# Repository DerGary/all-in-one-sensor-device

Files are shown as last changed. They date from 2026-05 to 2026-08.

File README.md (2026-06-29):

# All-In-One Smart Home Sensor Device

This is a project containing multiple sensors, an esp32 with esphome as well as a 3d printed enclosure to create a DIY Smart Home Sensor Device.

When I started building my smart home, I realized that most devices only cover very specific use cases. To get full functionality in each room, you usually need to buy multiple different devices.

My goal with this project was to create **the ultimate DIY smart home sensor device** that integrates all the essential sensors needed to achieve the following:

## 🎯 Goals

1. Control the lighting in a room by turning it on when motion is detected and keeping it on as long as someone is present (even if the person is not moving).
1. Monitor the brightness in the room and only turn lights on if needed (and off again when no longer required).
1. Measure air quality, humidity, and temperature.
1. Use Bluetooth to track a person’s smartphone and thereby determine which room they are in, so the smart home can react accordingly.
1. Keep the footprint as small as possible.
1. Powered by a single cable. USB-C in particular.
1. Ensure the design is unobtrusive and blends seamlessly into the living room.
1. Integrate with Home Assistant.
1. No cloud dependency.

## Device Types and Revisions

- [All-In-One Smart Home Sensor Case V1](./V1/README.md) - [Makerworld](https://makerworld.com/de/models/1744429-all-in-one-smart-home-sensor-case-v1#profileId-1854007)
- [All-In-One Smart Home Sensor Case V2](./V2/README.md) - [Makerworld](https://makerworld.com/de/models/2180710-all-in-one-smart-home-sensor-case-v2#profileId-2381634)
- [All-In-One Smart Home Sensor Case V2.1](./V2.1/README.md) - [Makerworld](https://makerworld.com/de/models/2180710-all-in-one-smart-home-sensor-case-v2#profileId-2381634)
- [Ultimate Smart Home Sensor Case](./Ultimate/README.md) - [Makerworld](https://makerworld.com/de/models/2946707-ultimate-smart-home-sensor-case#profileId-3300915)

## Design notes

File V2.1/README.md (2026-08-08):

![[./instructions/intro]]

## 🛠️ Assembly Instructions

1. Download the V2.1 assembly instructions PDF from below
2. Follow the assembly instructions in the PDF file

![[./instructions/changelog]]
![[../V2/changelog]]
![[./instructions/disclaimer]]

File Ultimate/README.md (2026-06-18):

![[./instructions/intro]]

## 🛠️ Assembly Instructions

1. Download the Ultimate assembly instructions PDF from below
2. Follow the assembly instructions in the PDF file

![[./instructions/changelog]]
![[./instructions/disclaimer]]

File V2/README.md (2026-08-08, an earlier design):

# All-In-One Smart Home Sensor Case V2

[Makerworld](https://makerworld.com/de/models/2180710-all-in-one-smart-home-sensor-case-v2#profileId-2381634)

## Please read the disclaimer at the bottom before printing

Hello everyone 👋, this has been one of my biggest projects so far. If you have any questions about the project please ask them in the comments then I can answer them and everyone can learn from that.

When I started building my smart home, I realized that most devices only cover very specific use cases. To get full functionality in each room, you usually need to buy multiple different devices.

My goal with this project was to create **the ultimate DIY smart home sensor device** that integrates all the essential sensors needed to achieve the following:

## 🎯 Goals

1. Control the lighting in a room by turning it on when motion is detected and keeping it on as long as someone is present (even if the person is not moving).
1. Monitor the brightness in the room and only turn lights on if needed (and off again when no longer required).
1. Measure air quality, humidity, and temperature.
1. Use Bluetooth to track a person’s smartphone and thereby determine which room they are in, so the smart home can react accordingly.
1. Keep the footprint as small as possible.
1. Powered by a single cable. USB-C in particular.
1. Ensure the design is unobtrusive and blends seamlessly into the living room.
1. Integrate with Home Assistant.
1. No cloud dependency.

## 🖨️ Print Instructions

- **Material:** PLA/PETG
- **Layer Height:** 0.20 mm
- **Nozzle:** 0.4 mm
- **Infill:** 15 %
- **Walls:** 2
- **Divider:** print **upright** with a **brim**, flat side on the build plate. If you orient it differently, it won’t print correctly.
- **Brightness sensor shield:** print with **transparent** material, or omit it entirely. It’s not required but hides the sensor a bit and improves the look.

## 🛠️ Assembly Instructions

1. Download the V2 assembly instructions PDF from below
2. Follow the assembly instructions in the PDF file

## 🆕 Changelog

See [changelog.md](./changelog.md).

### ⚠️ Disclaimer

This project is **not easy**: you have to solder a lot, including **very small** pins. You have been warned — but I’d love to see people try it 😊

The finished product is not perfect — that’s why the title is not *“Ultimate Smart Home Sensor Device”* 😅. I plan to release a revised version with other sensors when I have time and when the sensors I want become more accessible. Since I don’t know when that will be, I’m sharing this version for now.

**Things that bug me on the current version:**

1. **(This got a lot better on the V2 version, to a point where its not really an issue anymore, but it might happen and therefore is still listed here)** The motion sensor is very cheap and sometimes triggers when no one is in the room. (This can be minimized by **reducing the ESP’s Wi-Fi signal strength**, as cheap motion sensors are prone to misfire due to Wi-Fi interference.)
1. The motion sensor can trigger when you **air the room**, as it detects heat changes.
1. The presence sensor uses **24 GHz**. While it can detect mostly stationary humans, it cannot detect **very small movements** or someone under a blanket. (This mostly applies to my girlfriend — somehow I am tracked a bit better 😅).
1. The presence sensor is **extremely hard to solder**. I actually broke a sensor by accidentally desoldering the resistor right next to the pins. I now solder the wires directly to the pins which is janky but it works and is a lot easier.

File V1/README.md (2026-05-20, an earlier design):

# All-In-One Smart Home Sensor Case V1

This version of the sensor is deprecated please use V2 instead.

Please find more information on this version at [Makerworld](https://makerworld.com/de/models/1744429-all-in-one-smart-home-sensor-case-v1#profileId-1854007)

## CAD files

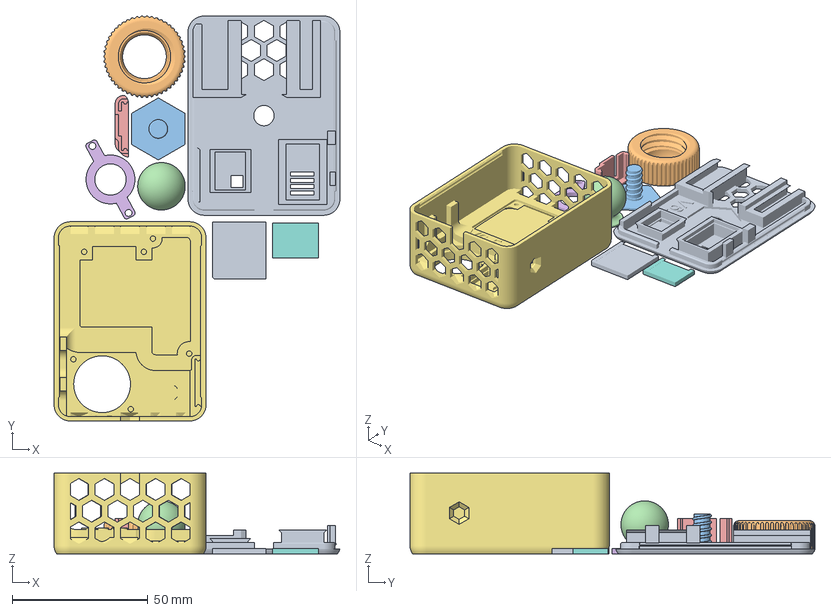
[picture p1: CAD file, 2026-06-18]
Ultimate/models/ultimate.3mf
105.3 x 149.2 x 29.8 mm
ultimate.stl_5
Screw.stl
ultimate.stl_6
ultimate.stl_9
ultimate.stl_4
ultimate.stl_3
Assembly
ultimate.stl_7
ultimate.stl_8

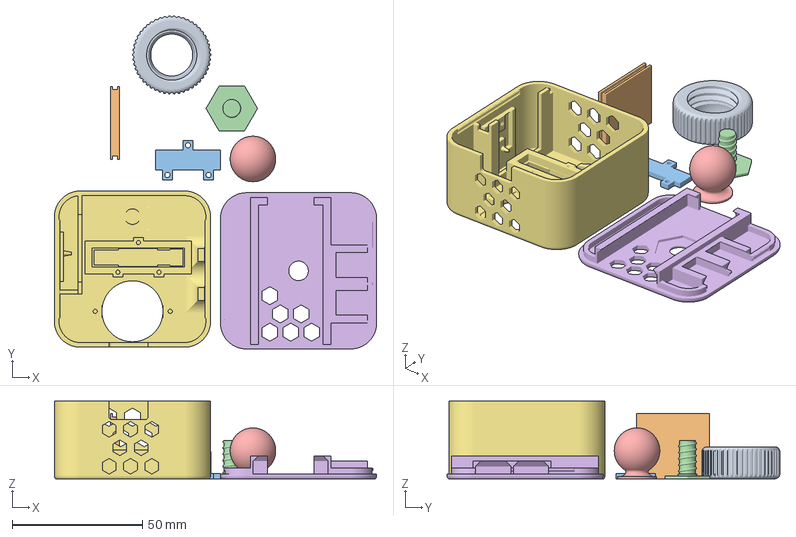
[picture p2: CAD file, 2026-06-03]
V2.1/models/V2.1-Large.3mf
123.8 x 127.8 x 29.8 mm
Screw.stl
V2.1-D1Mini.stl_2
V2.1-D1Mini.stl_5
V2.1-D1Mini.stl_6
V2.1-D1Mini.stl_8
V2.1-Large.stl_7
V2.1-Large.stl

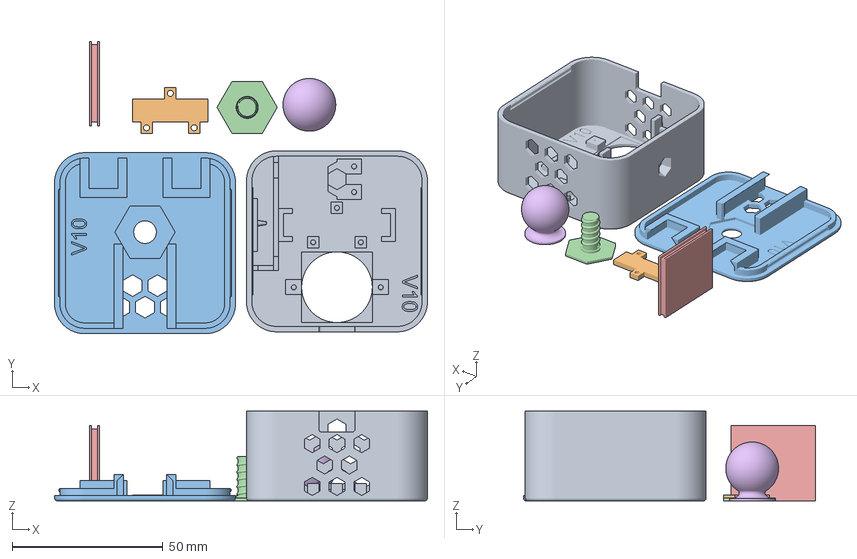
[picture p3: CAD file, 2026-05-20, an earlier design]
V2/models/v2-SuperMini.3mf
123.6 x 96.9 x 29.8 mm
All-In One Sensor Case ESP Super Mini.stl
All-In One Sensor Case ESP Super Mini.stl_4
All-In One Sensor Case ESP Super Mini.stl_5
All-In One Sensor Case ESP Super Mini.stl_6
All-In One Sensor Case ESP Super Mini.stl_7
All-In One Sensor Case ESP Super Mini.stl_8

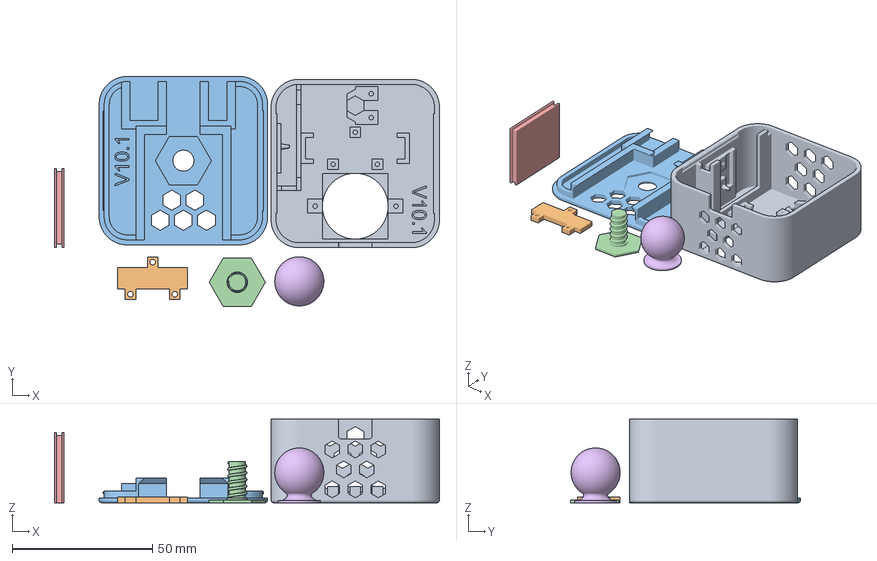
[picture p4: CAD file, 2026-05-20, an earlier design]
V2/models/v2-D1Mini.3mf
137.1 x 81.9 x 29.8 mm
All-In One Sensor Case ESP D1 Mini.stl
All-In One Sensor Case ESP D1 Mini.stl_4
All-In One Sensor Case ESP D1 Mini.stl_5
All-In One Sensor Case ESP D1 Mini.stl_6
All-In One Sensor Case ESP D1 Mini.stl_7
All-In One Sensor Case ESP D1 Mini.stl_8

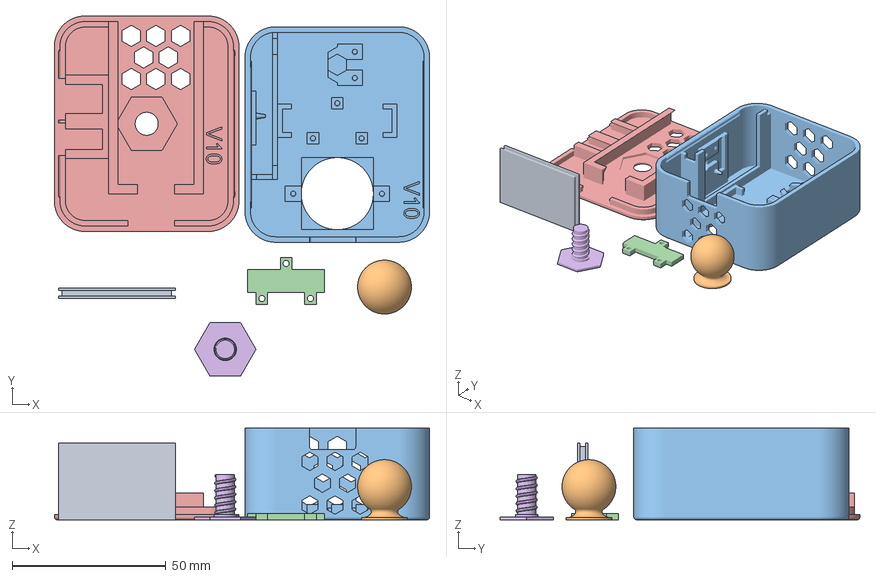
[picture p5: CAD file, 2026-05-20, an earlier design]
V2/models/v2-Large.3mf
121.9 x 116.9 x 29.8 mm
Sensor Gehäuse Large ESP32.stl_2
Sensor Gehäuse Large ESP32.stl_8
Sensor Gehäuse Large ESP32.stl
Sensor Gehäuse Large ESP32.stl_5
Sensor Gehäuse Large ESP32.stl_6
Sensor Gehäuse Large ESP32.stl_7

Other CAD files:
V2.1/models/V2.1-SuperMini.3mf
V2.1/models/V2.1-D1Mini.3mf
Ultimate/models/ultimate.stl
V2.1/models/V2.1-D1Mini.stl
V2.1/models/V2.1-Large.stl
V2.1/models/V2.1-SuperMini.stl
V2/models/v2-D1Mini.stl
V2/models/v2-Large.stl
V2/models/v2-SuperMini.stl

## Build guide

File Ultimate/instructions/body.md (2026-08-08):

## 🔢 Steps

1. Source all the parts from the shopping list
1. Print the enclosure
1. Solder and wire all sensors to the distribution boards and ESP
1. Flash the ESP with the software and verify that all sensors work (connect it to your Home Assistant instance to monitor them).
1. Assemble the sensors and ESP into the enclosure.
1. Place the device in its designated spot.
1. After a few minutes, calibrate the sensors and re-flash the software.
1. Create your Home Assistant automations using the sensors.

### 🛒 Shopping List

You can also buy the parts from other sites. If you don’t mind waiting, AliExpress is usually cheaper. I’ve listed the exact products I used because I can confirm they worked for me.

| Name | Hint | Link |
| ----- | --- | --- |
| ESP32 Super Mini | My prebuilt binaries use the C6, you can also use other variants if you build it yourself. | [DFRobot ESP32-C6](https://www.berrybase.de/en/dfrobot-beetle-esp32-c6-wifi-6-bluetooth-5-zigbee-3.0-thread-risc-v-13-io-ports-3.3v) <br> [ESP32-C6 Super Mini](https://de.aliexpress.com/item/1005009089500839.html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) (you must choose the correct variant, as the link does not include the choice) |
| Power Supply (PSU) | Any low-power PSU you already have should work. Otherwise, buy a simple one. | [Amazon](https://www.amazon.de/dp/B0D7MD5BJ3?ref=ppx_yo2ov_dt_b_fed_asin_title&th=1) |
| Temperature Sensor SHT4x or BME280 | I decided to use the SHT41 as its temperature sensor is more accurate. <br> The BME280 is also supported when you need to measure air pressure. | [BME280](https://amzn.eu/d/04BAvHum) <br> [SHT4x](https://de.aliexpress.com/item/1005008518326181.html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) |
| Screws | 8x M2x3mm | [Amazon](https://www.amazon.de/dp/B0CZNT5YXV?ref=ppx_yo2ov_dt_b_fed_asin_title&th=1) |
| Brightness Sensor BH1750 | Worked flawlessly for me in V1 and V2 so it is back in the Ultimate | [Amazon](https://www.amazon.de/dp/B0D3WN41FS?ref=ppx_yo2ov_dt_b_fed_asin_title) |
| CO2 Sensor SCD4x | Measures actual CO2 concentration. Both SCD40 and SCD41 are supported. | [Aliexpress](https://de.aliexpress.com/item/1005008696769890.html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) |
| VOC Sensor SGP30 | Measures volatile organic compounds (air quality). I am using the blue module also called GY-SGP30. | [Aliexpress](https://de.aliexpress.com/item/1005012034193686.html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) |
| Motion Sensor Panasonic EKMC 1603111 | Theoretically other Panasonic PIRs would be also compatible if they have the same form factor. | [Aliexpress](https://de.aliexpress.com/item/1005006704410099.html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) |
| Presence Sensor LD2450 | Handles multi-person, zone-based tracking. Pay attention that the one you buy includes the cable as it is easier to work with. | [Amazon](https://www.amazon.de/dp/B0FMRQ6DWJ?ref_=ppx_hzod_title_dt_b_fed_asin_title_0_0) |
| Presence Sensor C4001 | Handles still-presence detection (detecting a stationary person). Both sensors are needed; they complement each other. Unfortunately this sensor is hard to source — import taxes may apply depending on the supplier. | [DigiKey](https://www.digikey.de/de/products/detail/dfrobot/SEN0609/23028638) <br> [RobotShop](https://eu.robotshop.com/de/products/dfrobot-mmwave-c4001-24ghz-sensor-zur-erkennung-menschlicher-prasenz-25-meter-uart) <br> [Mouser](https://www.mouser.de/ProductDetail/DFRobot/SEN0609?qs=HFfMDpzxxd21aKNJkzimmg%3D%3D) <br> [OpenELAB](https://openelab.io/de/products/dfrobot-mmwavec400124ghz-humanpresencedetectionsensor-25meters) <br> [DFRobot](https://www.dfrobot.com/product-2793.html) |
| Cables | I used 22 AWG wire | [Aliexpress](https://de.aliexpress.com/item/1005007671008743.html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)<br>[Amazon](https://www.amazon.de/dp/B0FDKT9XPV?ref_=ppx_hzsearch_conn_dt_b_fed_asin_title_1&th=1) |
| Long USB Cable | Choose length to fit your setup. | [Aliexpress](https://de.aliexpress.com/item/1005007053181899.html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) |
| Filament | I printed my case in Kingroon White PLA and with Kingroon White PETG. You can use bambu labs filament of course. I printed the brightness sensor cover out of translucent PLA/PETG. | [Kingroon Filament](https://de.aliexpress.com/item/1005007226921275.html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)<br>[Elegoo Transparent PLA](https://www.amazon.de/dp/B0CD7BS7B1?ref_=ppx_hzsearch_conn_dt_b_fed_asin_title_8)<br>[eSUN Clear PETG](https://www.3djake.de/esun/petg-clear-5) |
| Cable Distribution (Proto Boards) | I broke something off proto boards and used that to distribute the cables which needed to go to multiple sensors. | [Amazon](https://amzn.eu/d/0a2D7E1M) |
| Status LED | I used an LED from leftovers of a WS2812 LED strip with 5V that I got lying around | [Amazon](https://amzn.eu/d/04rXpC34) |
| 100µF 16V Electrolytic Capacitor<br>100nF (104) Ceramic Capacitor | The capacitors are used to suppress interferences that may be injected by the ESP32 into the power rails.<br> This measure was taken to improve the reliability of the PIR sensor and remove false positives as much as possible. It is recommended by Panasonic to do so. I got pretty good results without them but I wanted the best possible experience and your mileage may vary if you omit them. | [Amazon](https://www.amazon.de/dp/B0DXC7MX53) |

You also need:

- A soldering iron (and soldering skills)
- Solder
- Wire stripping tool
- Side cutters to trim the cables
- Screwdriver
- Pliers
- Desoldering pump (optional)
- Multimeter (optional if you trust your soldering skills)
- Electrical tape (optional, to cover LEDs on the C4001 and ESP)

### 🔢 Assembly Instructions

1. Desolder all the pin headers if there are any on your purchased sensors
    - Remove the pin spacers with pliers.
    - Clamp the sensor in a vise.
    - Desolder and remove the pins. It’s also possible to heat the solder and pull the pins with pliers without a desoldering pump.
1. Break a **7x4** matrix from the proto board
    I used a carpet knife to cut around the matrix on the proto board on both sides and used pliers to carefully break the proto board at the cut.

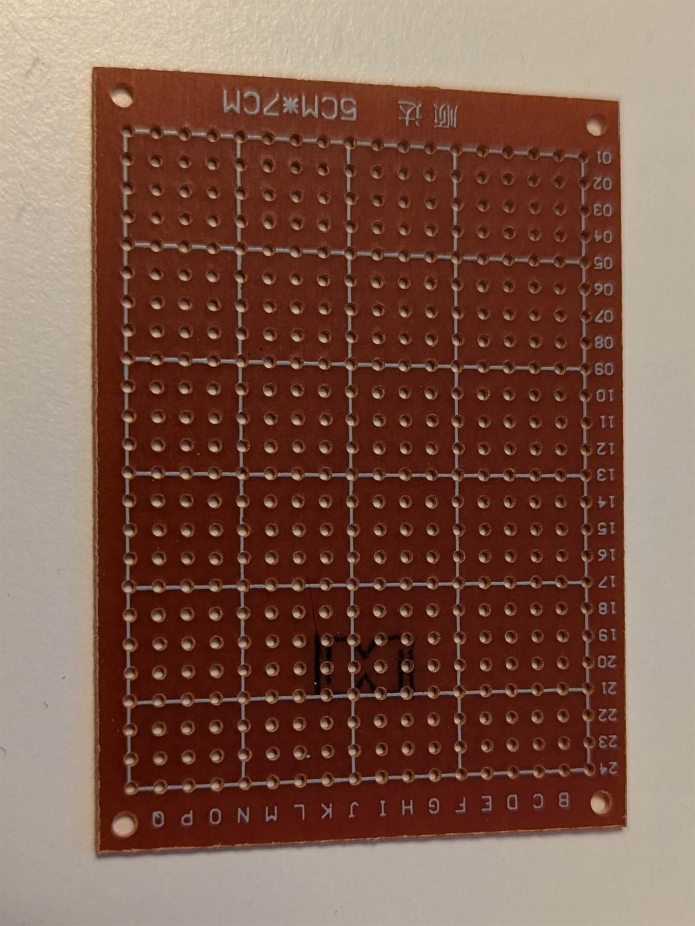
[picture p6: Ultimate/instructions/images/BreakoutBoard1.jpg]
    
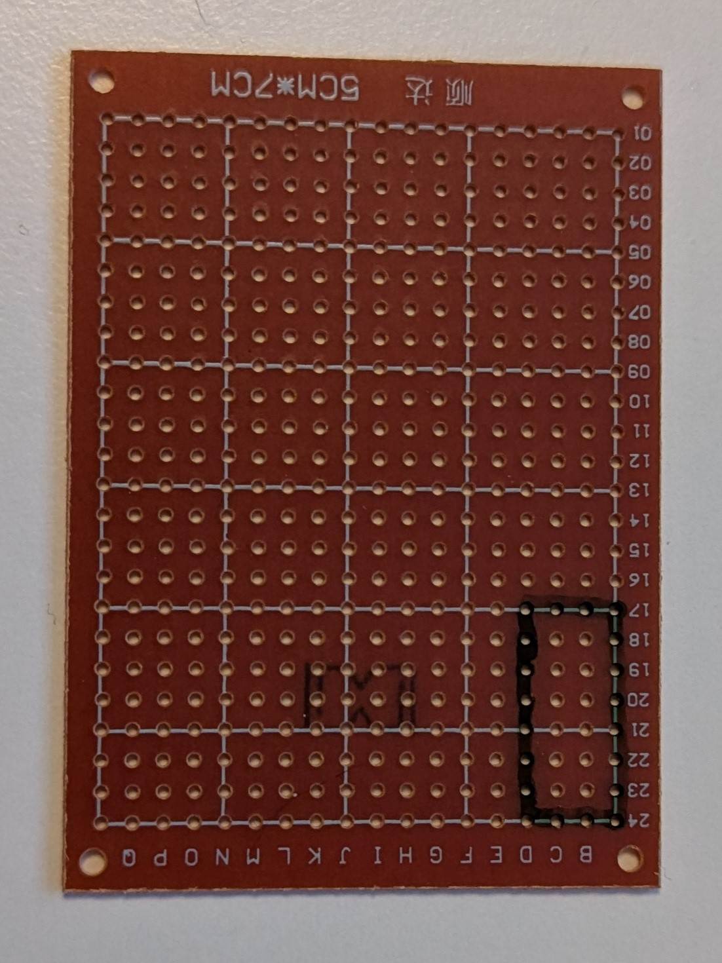
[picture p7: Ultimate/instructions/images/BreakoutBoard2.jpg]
    
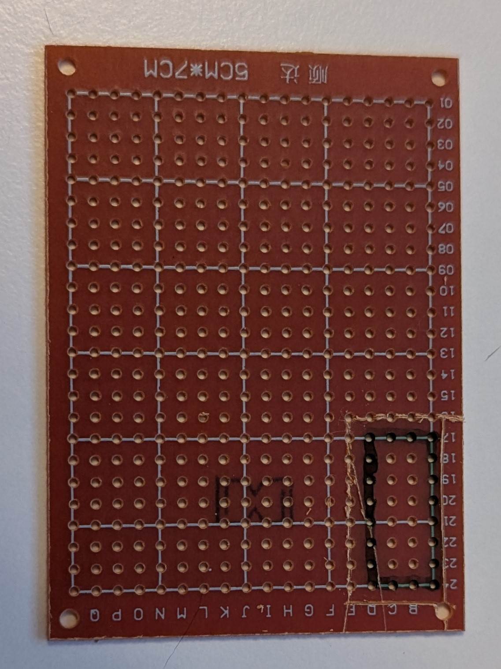
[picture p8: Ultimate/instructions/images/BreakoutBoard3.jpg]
    
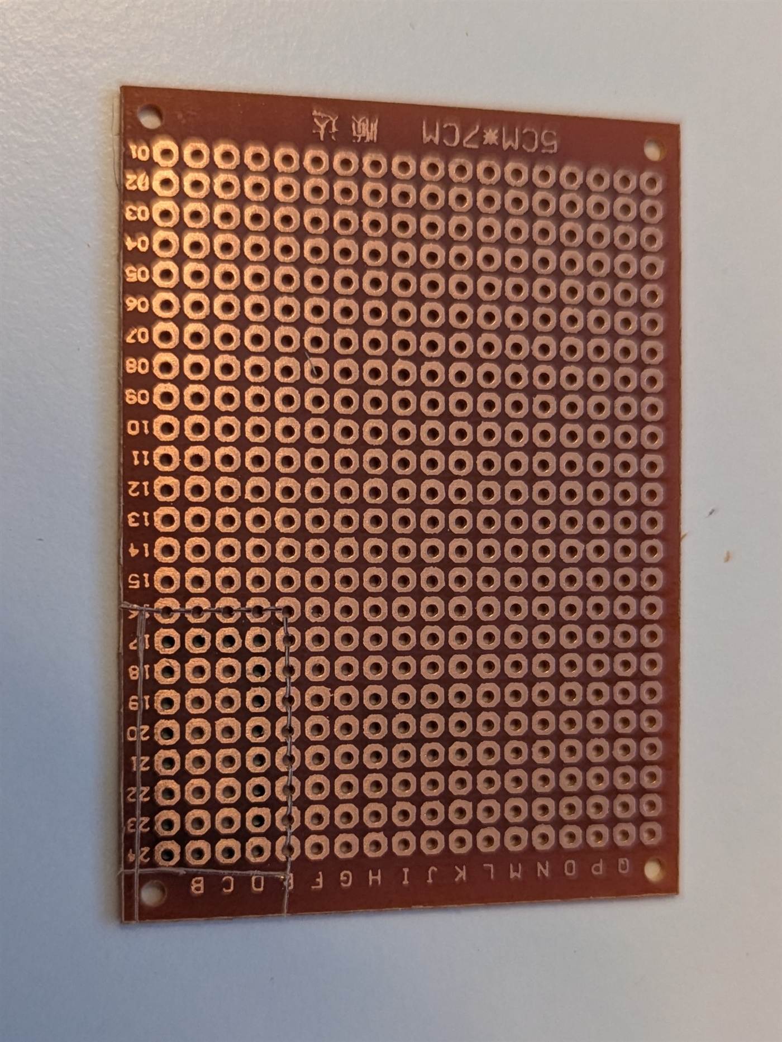
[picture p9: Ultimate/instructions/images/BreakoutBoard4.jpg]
    
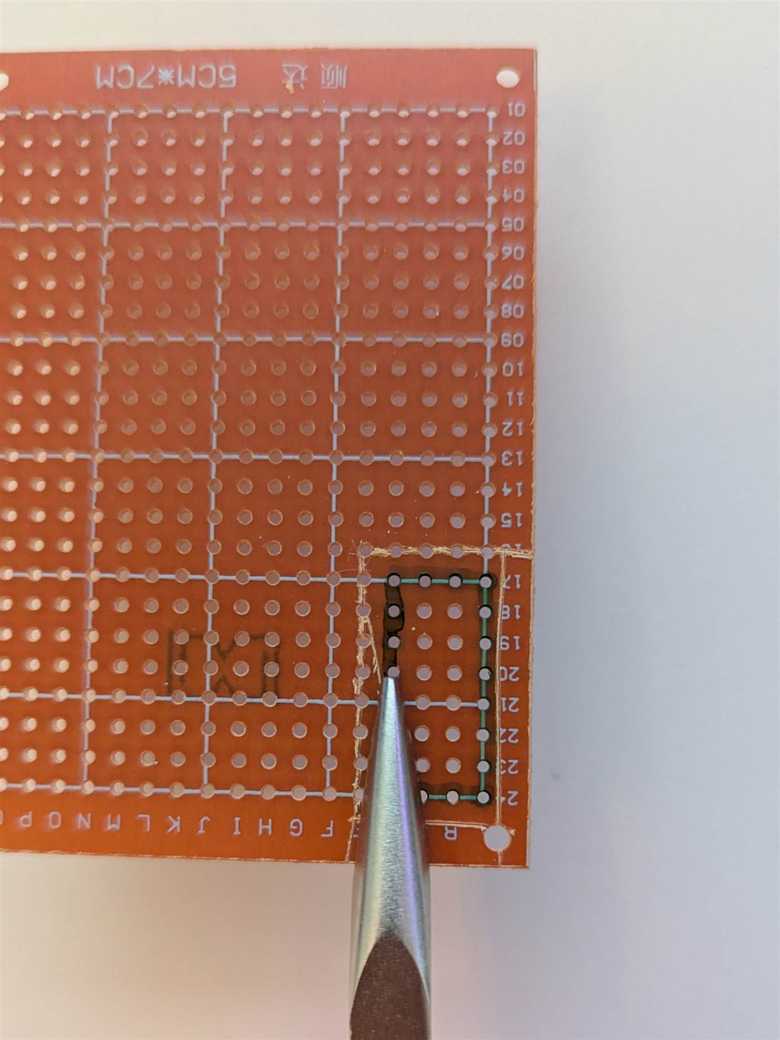
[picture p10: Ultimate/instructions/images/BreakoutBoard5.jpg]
    
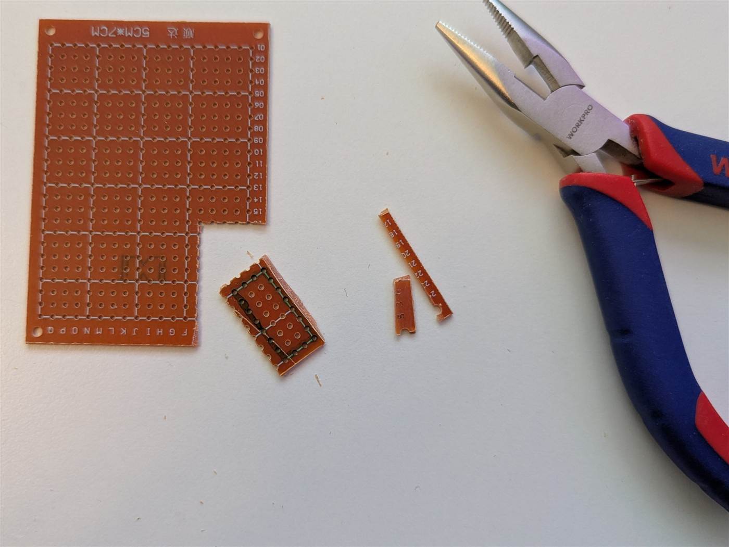
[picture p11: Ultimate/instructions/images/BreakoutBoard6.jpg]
    

1. Break a **5×2** matrix from the proto board
    Using the same technique as above.
1. Cut wires to length. I wrote the length of the cables in mm into the connection drawings. I show the two distribution boards separately to make things easier to follow. (There are further steps below on soldering order.) For the generic ESP32-C6 Super Mini the wiring differs in one aspect from the DFRobot Beetle as it only has one ground pin.
    - I only had 5 colors of wire
        - red = Voltage (If you have more colors use different colors for 3.3V (BME280/BH1750/SGP4x/SHT4x/SCD4x/PIR) and 5V(LD2450/C4001/LED), It is important to never mix them up)
        - black = Ground
        - Green = I2C SCL/UART (If you have more colors you can use different colors for UART and I2C)
        - Blue = I2C SDA/UART (If you have more colors you can use different colors for UART and I2C)
        - Yellow = Motion Out / Status LED Data In
    - **DFRobot Beetle ESP32-C6**
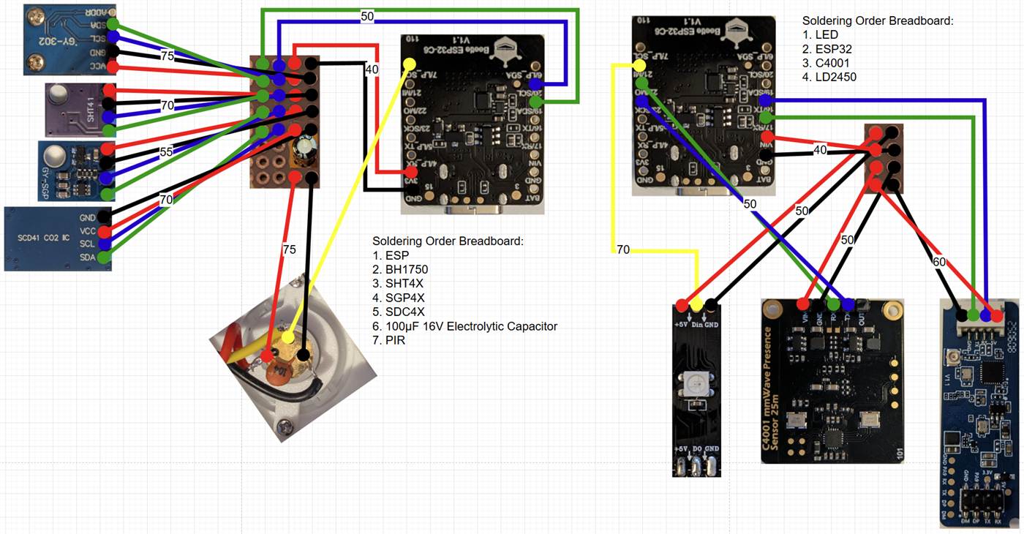
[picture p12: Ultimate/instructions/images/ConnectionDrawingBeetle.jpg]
        
    - **Generic ESP32-C6 Super Mini**
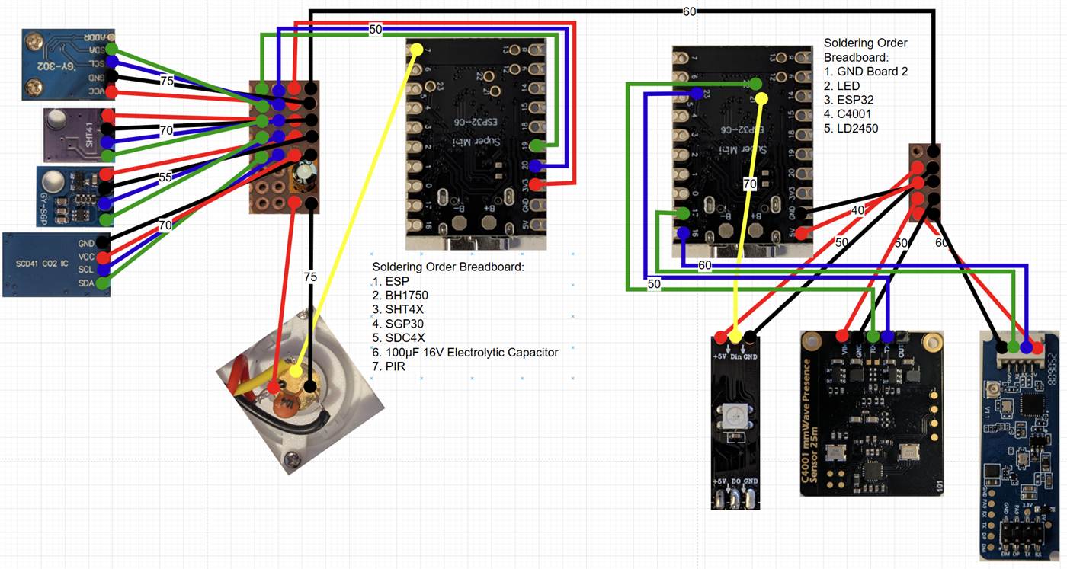
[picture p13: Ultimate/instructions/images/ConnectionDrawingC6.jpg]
        

    **Pin Reference**

    | Sensor / Function | GPIO |
    | --- | --- |
    | PIR Motion Out | GPIO7 |
    | I2C SDA (BH1750 / SHT4x / SGP30 / SCD4x) | GPIO19 |
    | I2C SCL (BH1750 / SHT4x / SGP30 / SCD4x) | GPIO20 |
    | WS2812 LED Data | GPIO21 |
    | LD2450 TX (ESP→Sensor) | GPIO16 |
    | LD2450 RX (Sensor→ESP) | GPIO17 |
    | C4001 TX (ESP→Sensor) | GPIO22 |
    | C4001 RX (Sensor→ESP) | GPIO23 |

1. Make sure to tin the wire ends
1. Solder one end of each wire to the sensors as described in the Connection Drawings from Step 4
    - PIR Sensor:
        - First place the printed round PIR bracket on the sensor as this can't be done when the sensor is already soldered together
        - The middle pin is the data pin
        - also solder the 100nF ceramic capacitor between the ground and the voltage pin
    - Presence Sensor LD2450:
        - **The colors of the included cable are different to the drawings. The cable may have different colors on your version. Pay attention to correctly wire every pin to the correct location. The pins are labeled on the board.**

    | PIR Sensor | Presence Sensors | BH1750 |
    | ---------- | ---------------- | ------ |
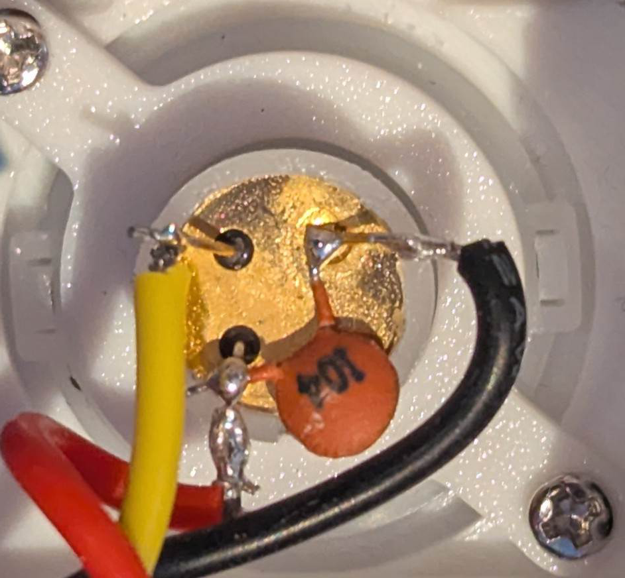
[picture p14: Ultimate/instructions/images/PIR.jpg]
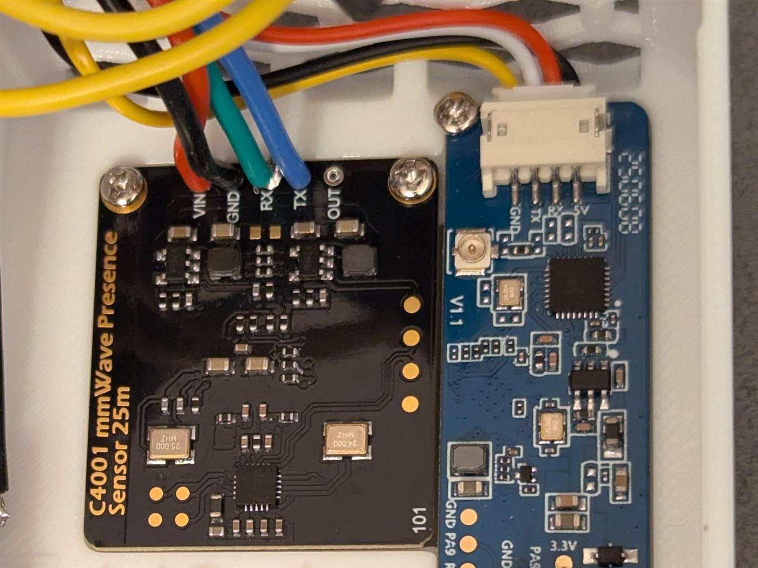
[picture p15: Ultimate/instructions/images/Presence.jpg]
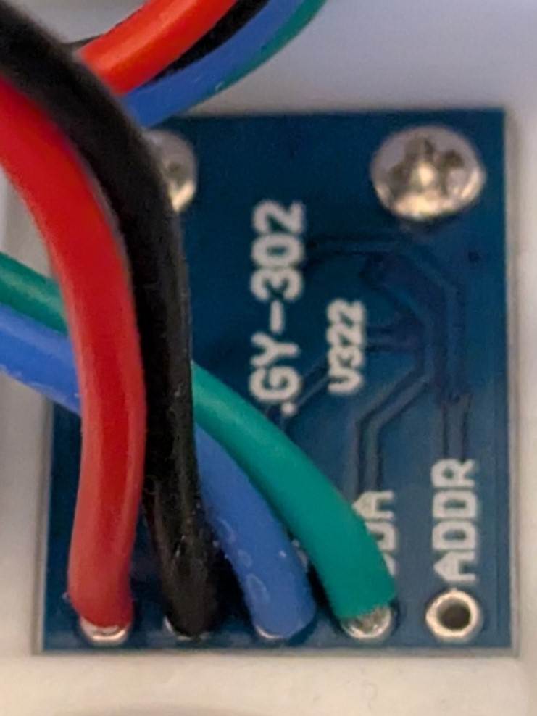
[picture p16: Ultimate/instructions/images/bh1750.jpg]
    |  |  |  |

    | SHT41 | SCD41 | SGP30 |
    | ----- | ----- | ----- |
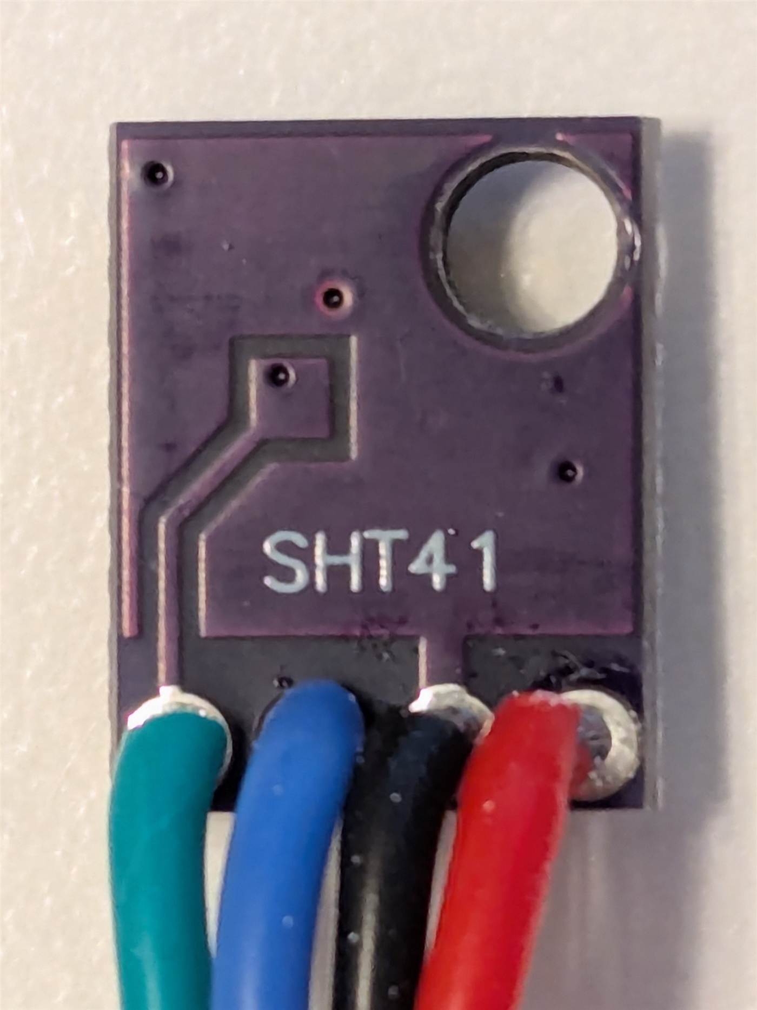
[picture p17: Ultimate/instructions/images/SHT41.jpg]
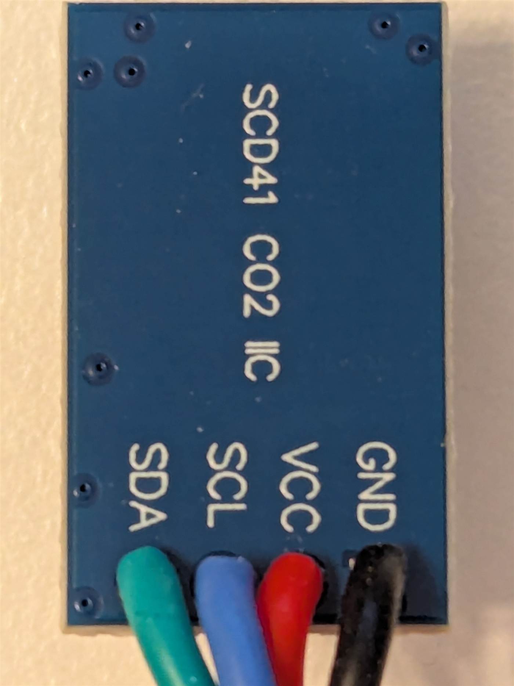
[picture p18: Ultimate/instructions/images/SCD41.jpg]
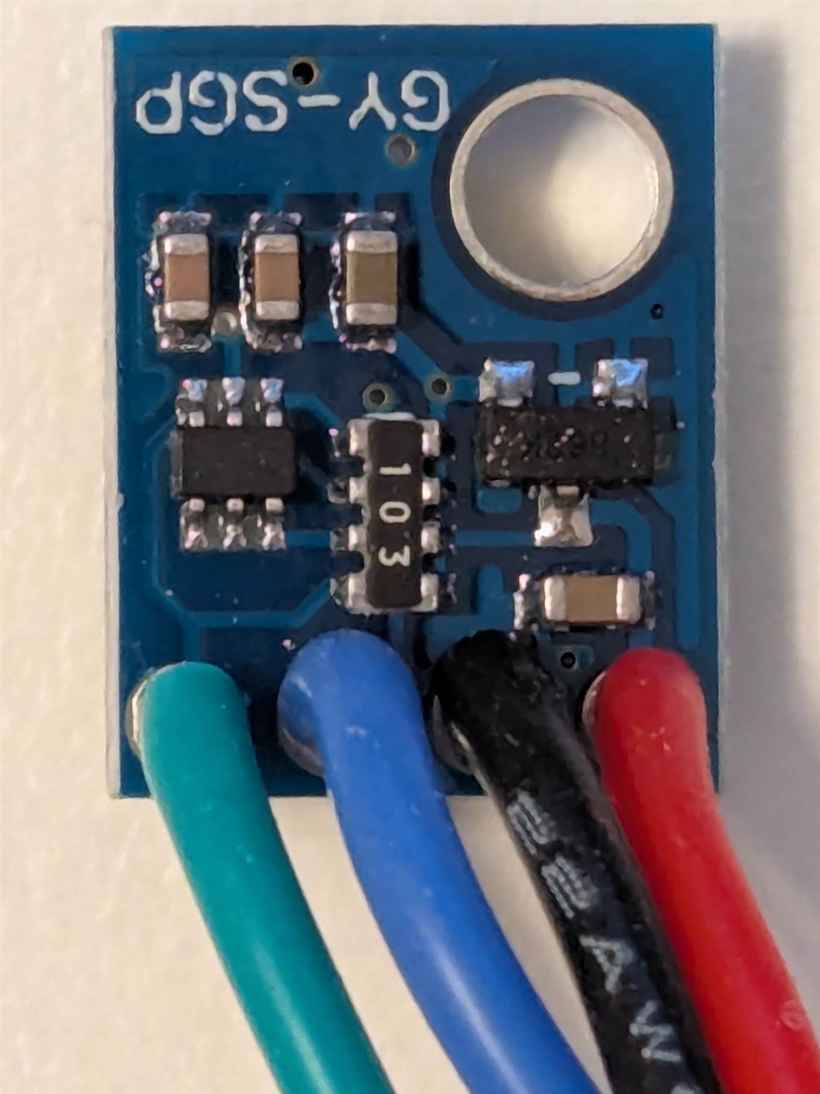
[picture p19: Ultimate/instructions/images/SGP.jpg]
    |  |  |  |

1. Solder the **other end** of the wires to the **distribution proto boards and ESP respectively. Connect wires of the same color together.** If you used a proto board where the lines are already connected via the board you don't need to do any extra step. My proto board has separated solder points so I had to bridge them.

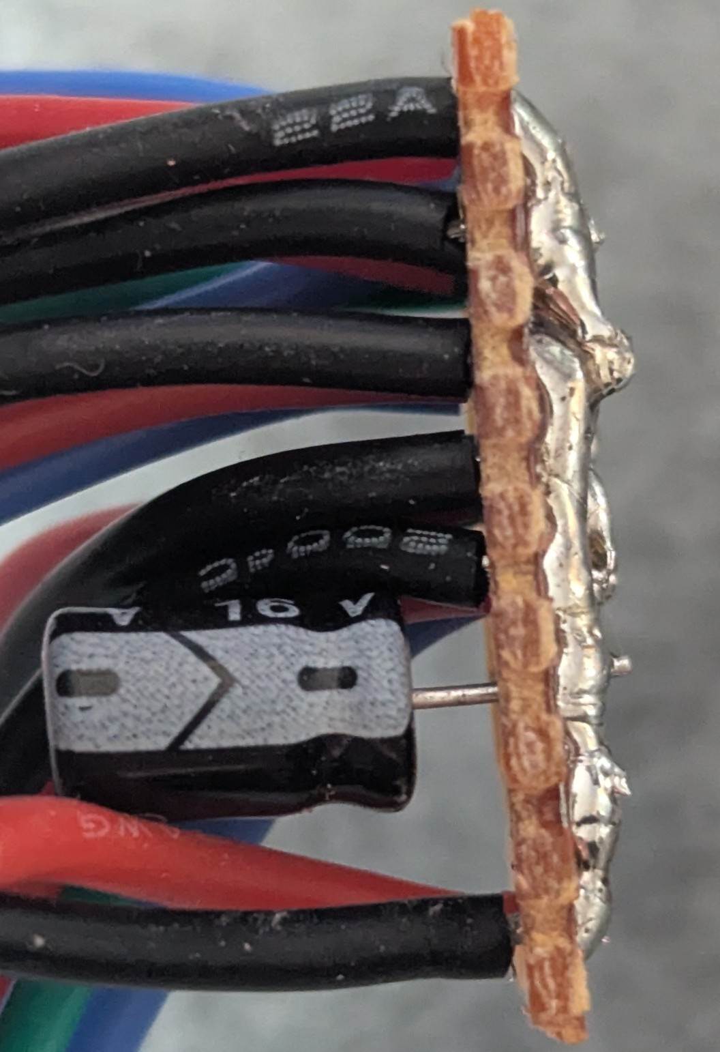
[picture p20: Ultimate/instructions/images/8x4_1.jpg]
    
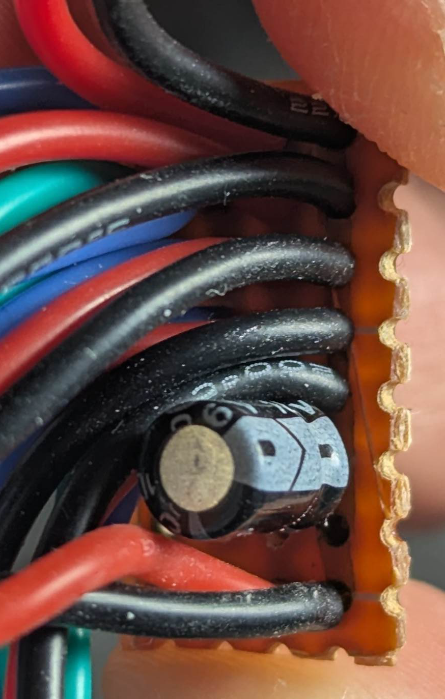
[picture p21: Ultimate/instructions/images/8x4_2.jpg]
    
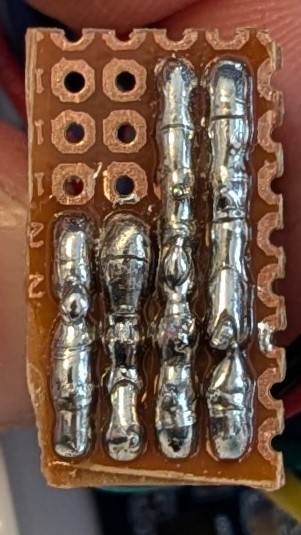
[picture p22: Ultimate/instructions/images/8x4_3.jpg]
    <br>
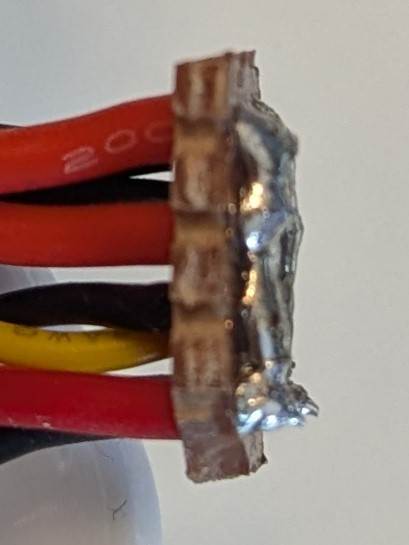
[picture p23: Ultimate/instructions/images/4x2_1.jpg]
    
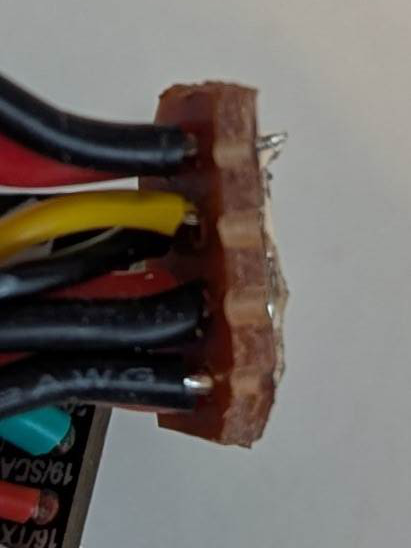
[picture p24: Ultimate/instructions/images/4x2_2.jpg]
    
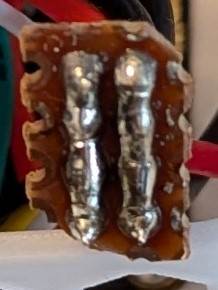
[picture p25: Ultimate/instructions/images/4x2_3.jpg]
    

    Also solder the **100µF electrolytic capacitor** across the 3.3V and GND rails on the distribution proto board, as shown in the Connection Drawings above. Observe polarity — the negative lead (shorter leg / marked stripe) connects to GND.

1. **Solder the wires to the ESP pins** as described in the connection drawings above. You need to attach the cables from the back side (because the wifi antenna is on the front and we want that to be facing away from the motion sensor) — attach them as shown in the photos.

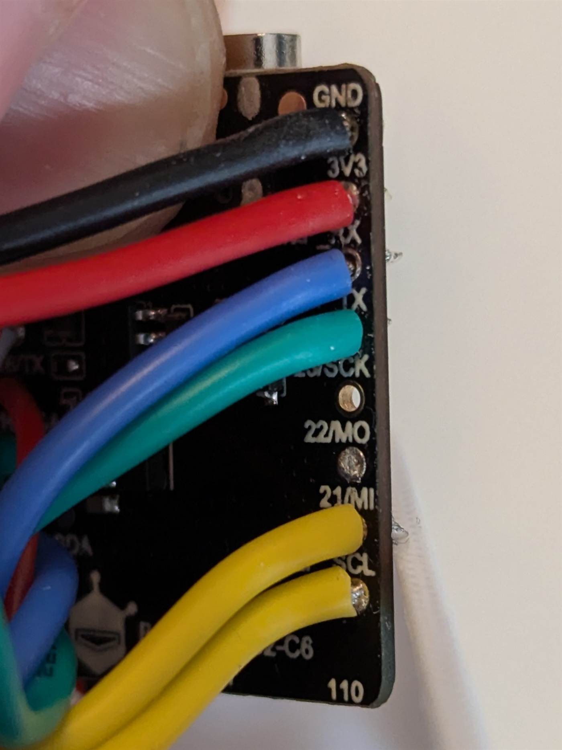
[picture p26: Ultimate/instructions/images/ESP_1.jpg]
    
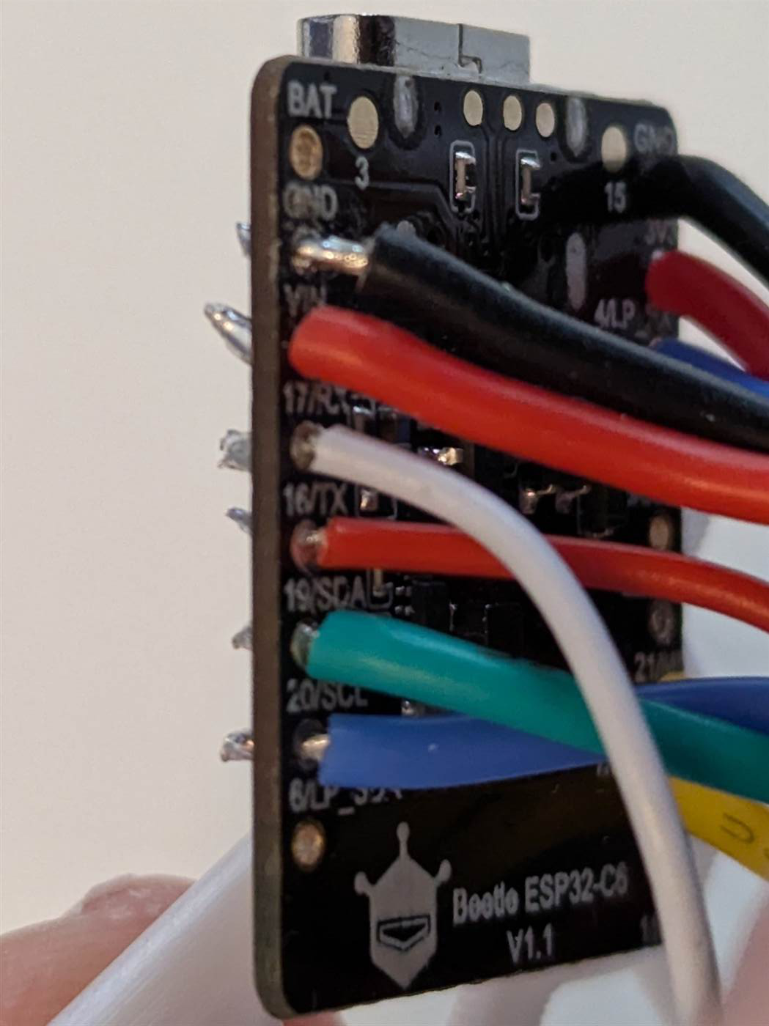
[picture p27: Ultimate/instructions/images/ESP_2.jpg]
    
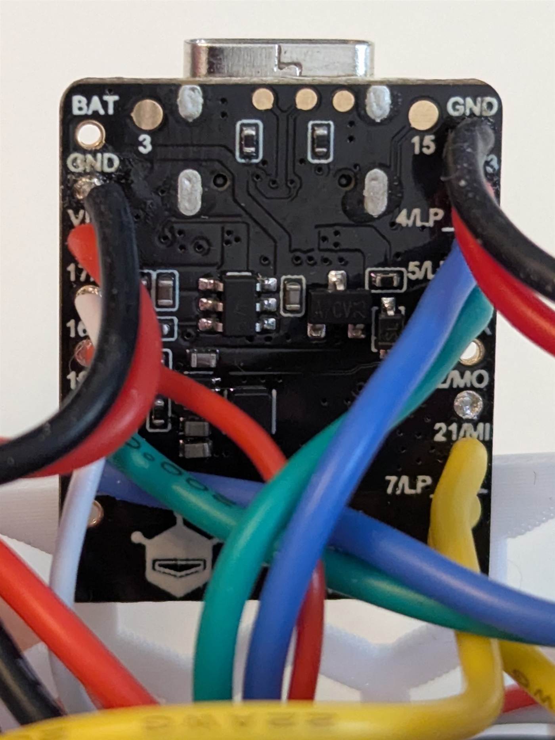
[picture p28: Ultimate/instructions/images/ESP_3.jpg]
    

1. Use a **multimeter** to verify that solder joints of different colors do not bridge. Any short can damage components and may cause smoke or even fire.
1. Now it's time to check whether all the soldering has worked out. Flash the software onto the ESP. It can be found in the software section. Verify that all sensors are detected and reporting, then return here to complete assembly.
1. Optionally cover the LEDs on the **C4001** and the **ESP** with a small piece of electrical tape to prevent them from lighting up inside the enclosure.

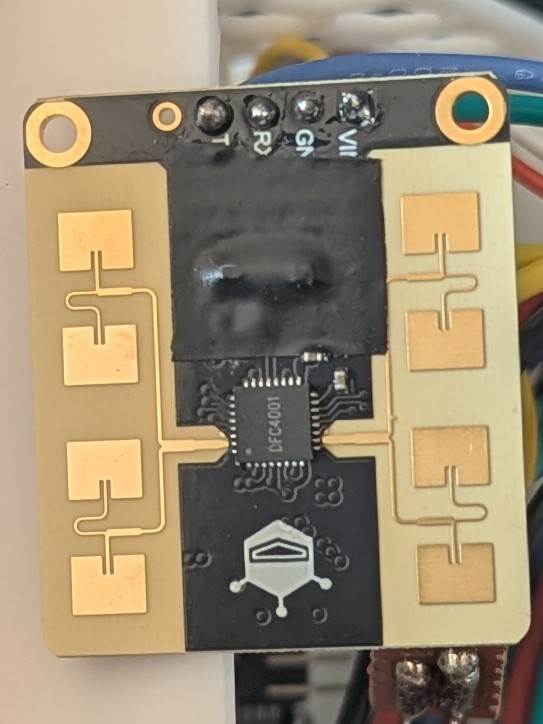
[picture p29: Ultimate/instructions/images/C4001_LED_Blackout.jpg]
    
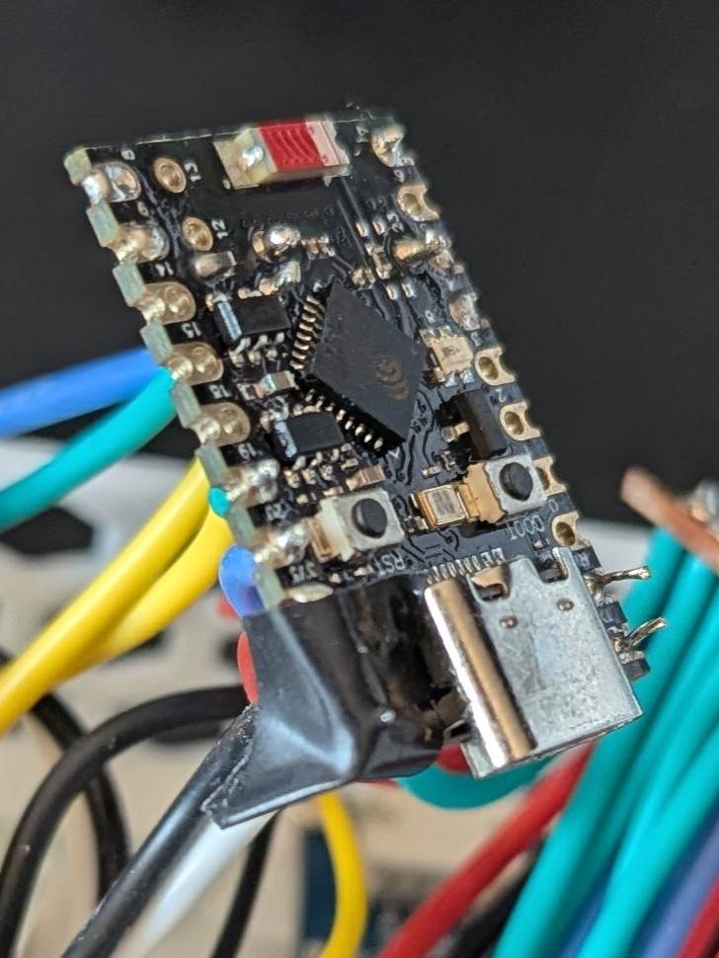
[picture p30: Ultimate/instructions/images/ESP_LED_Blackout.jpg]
    

1. Attach the ball head mount to the back of the case

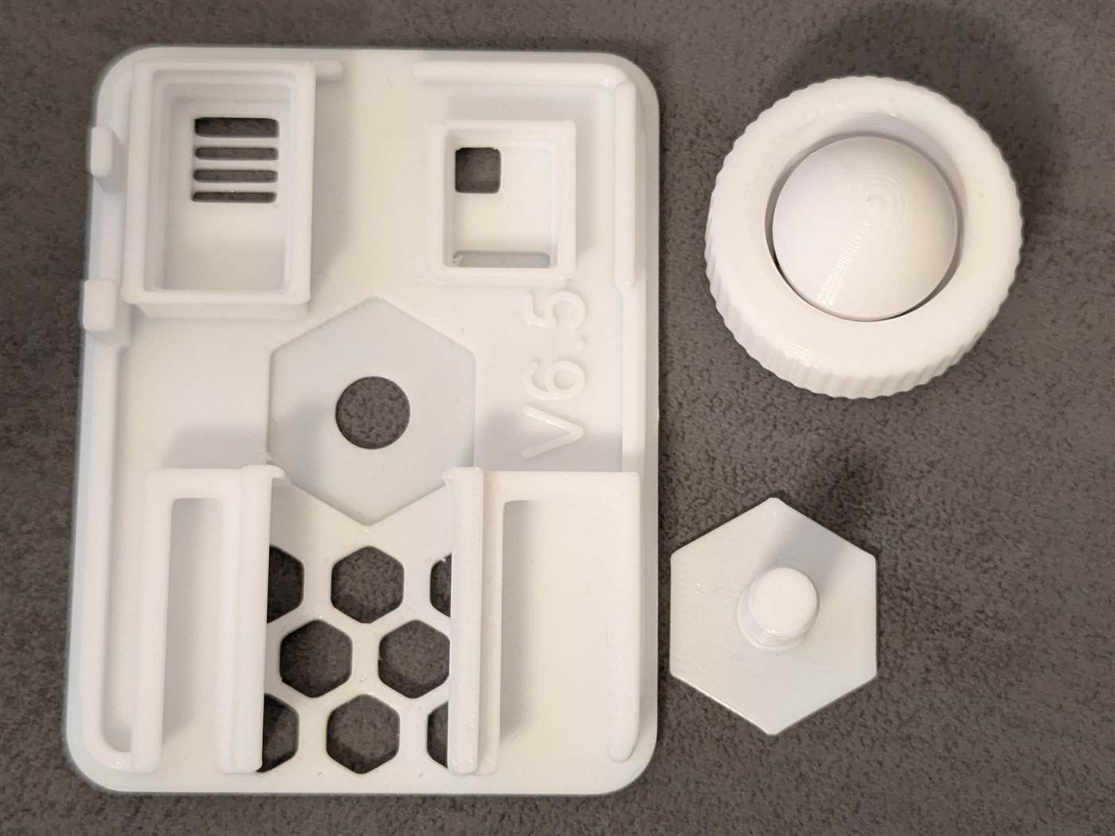
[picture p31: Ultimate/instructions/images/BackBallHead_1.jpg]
    
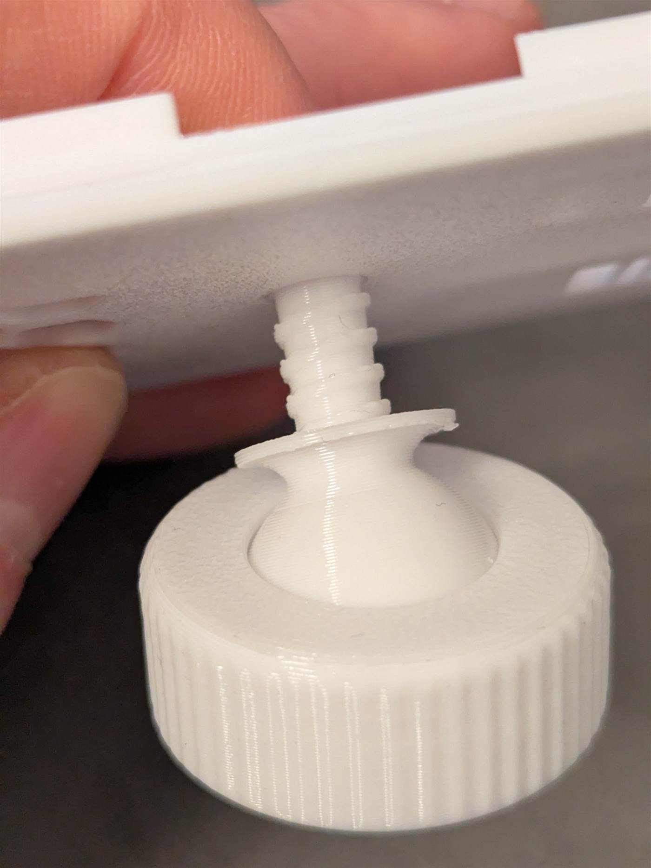
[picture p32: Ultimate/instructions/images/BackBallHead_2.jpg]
    
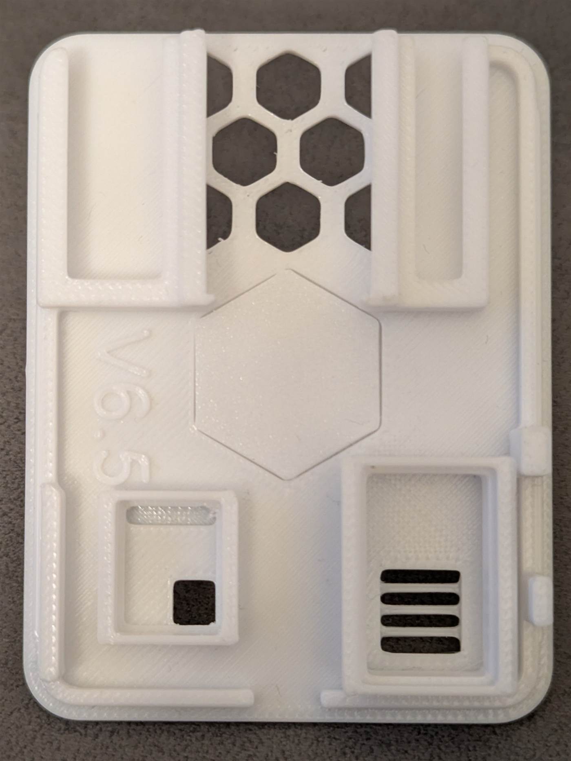
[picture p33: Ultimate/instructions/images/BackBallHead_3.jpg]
    

1. Place all the sensors, boards and ESP in place using M2x3mm screws
    The order does not really matter but it is easiest to do it in the order depicted in the photos here:

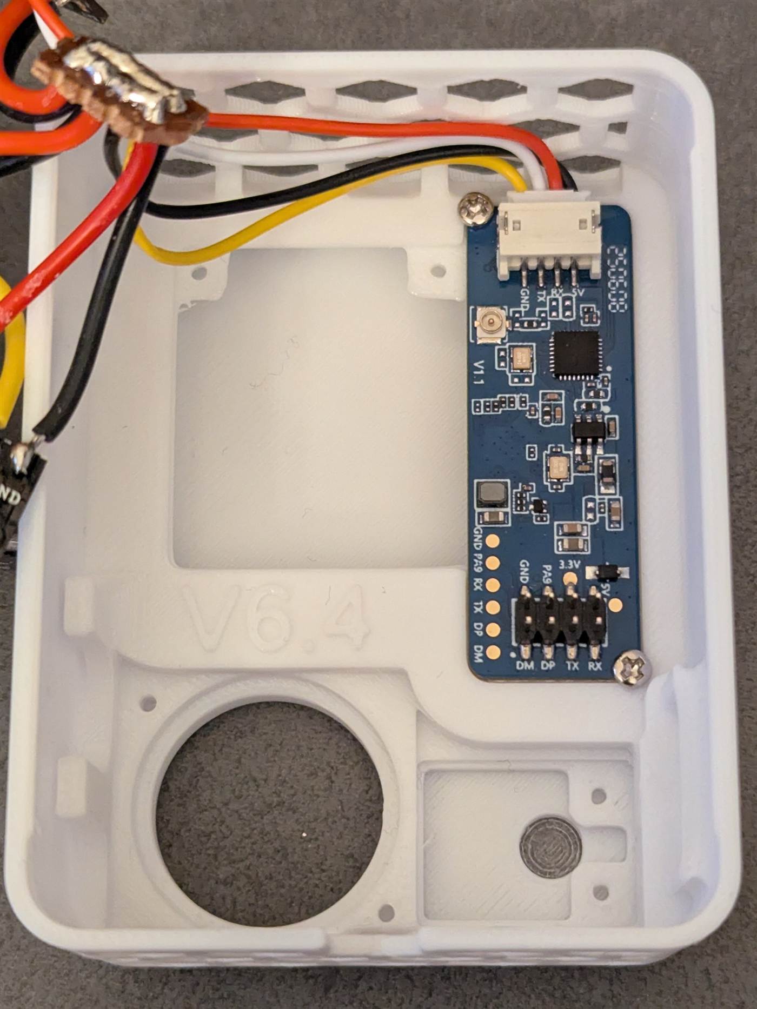
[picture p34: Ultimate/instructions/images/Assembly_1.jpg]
    
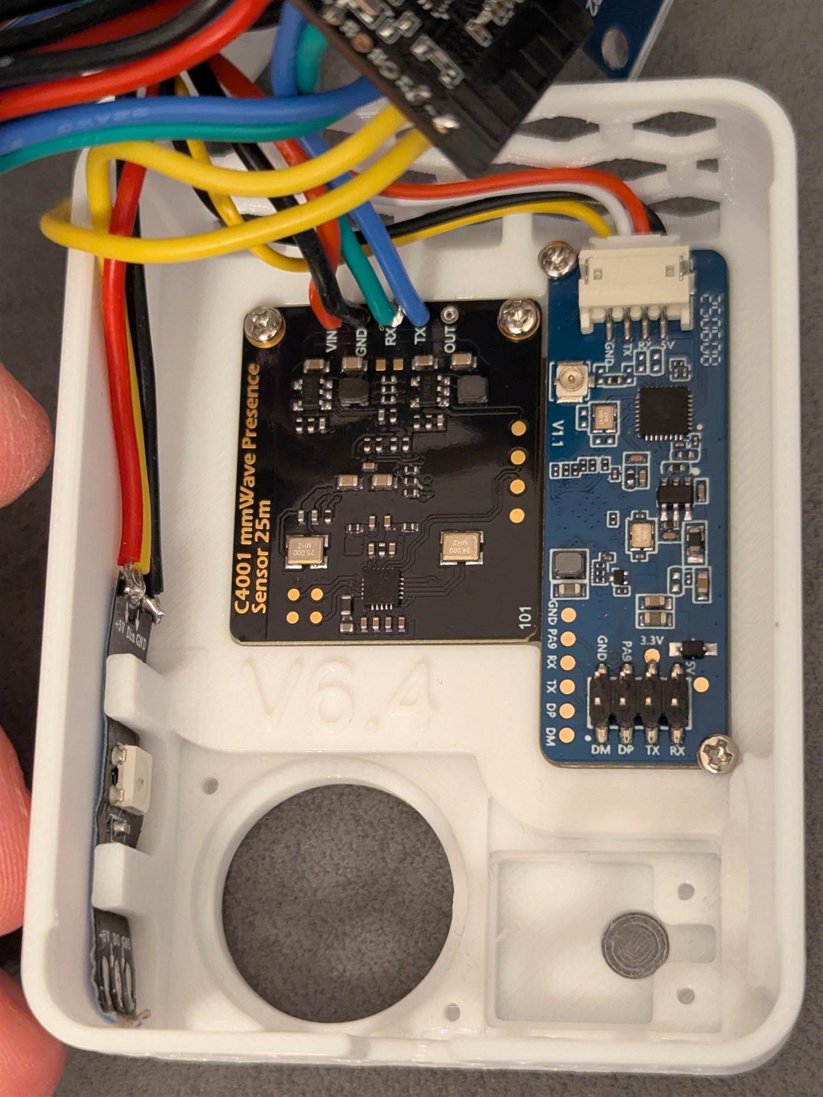
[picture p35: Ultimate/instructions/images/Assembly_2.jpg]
    
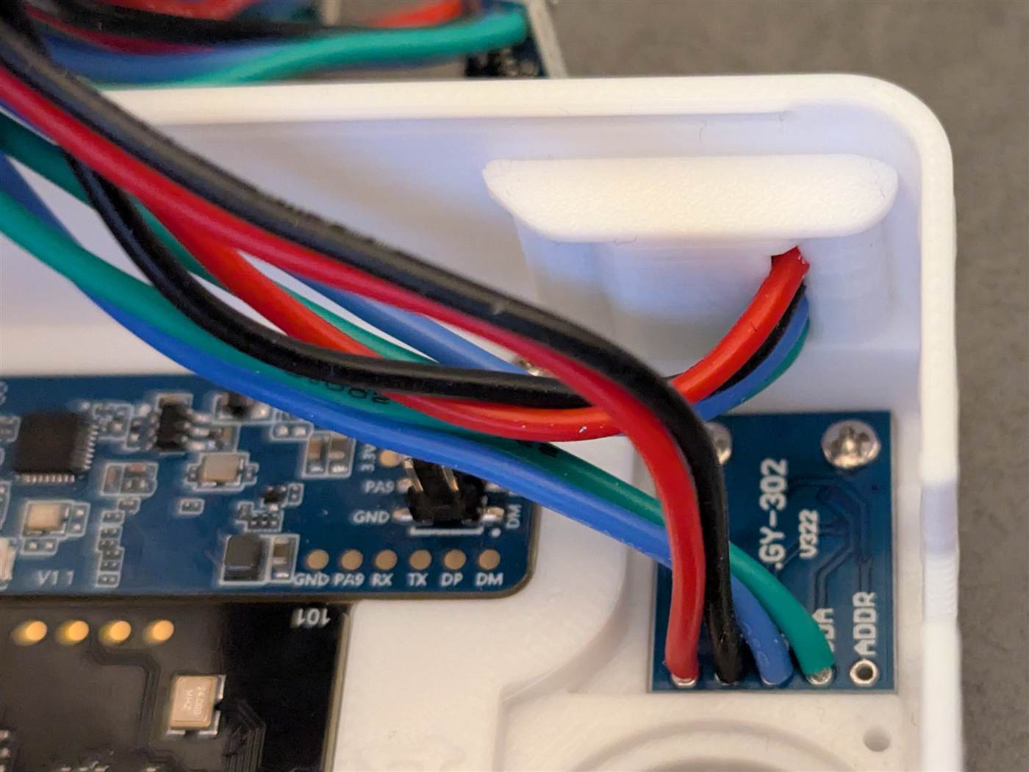
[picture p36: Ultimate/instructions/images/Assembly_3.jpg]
    
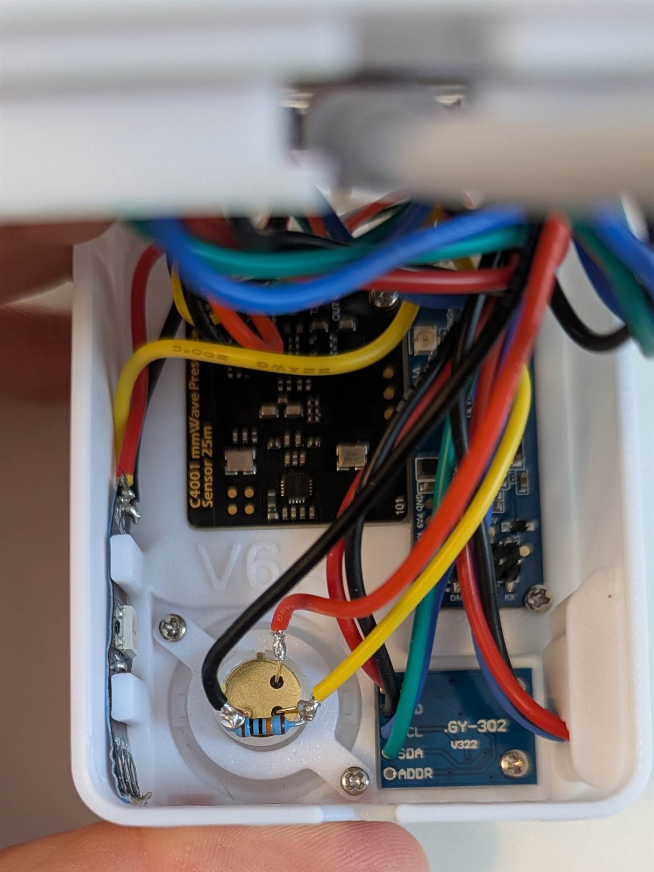
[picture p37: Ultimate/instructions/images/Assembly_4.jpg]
    
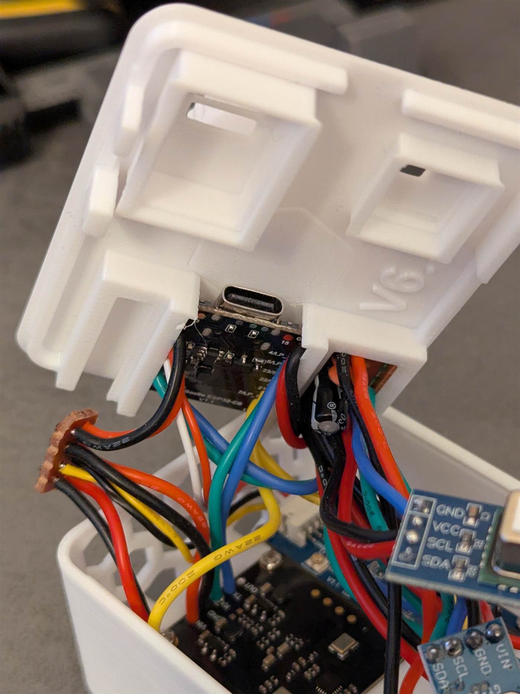
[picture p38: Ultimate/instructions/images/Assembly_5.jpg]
    
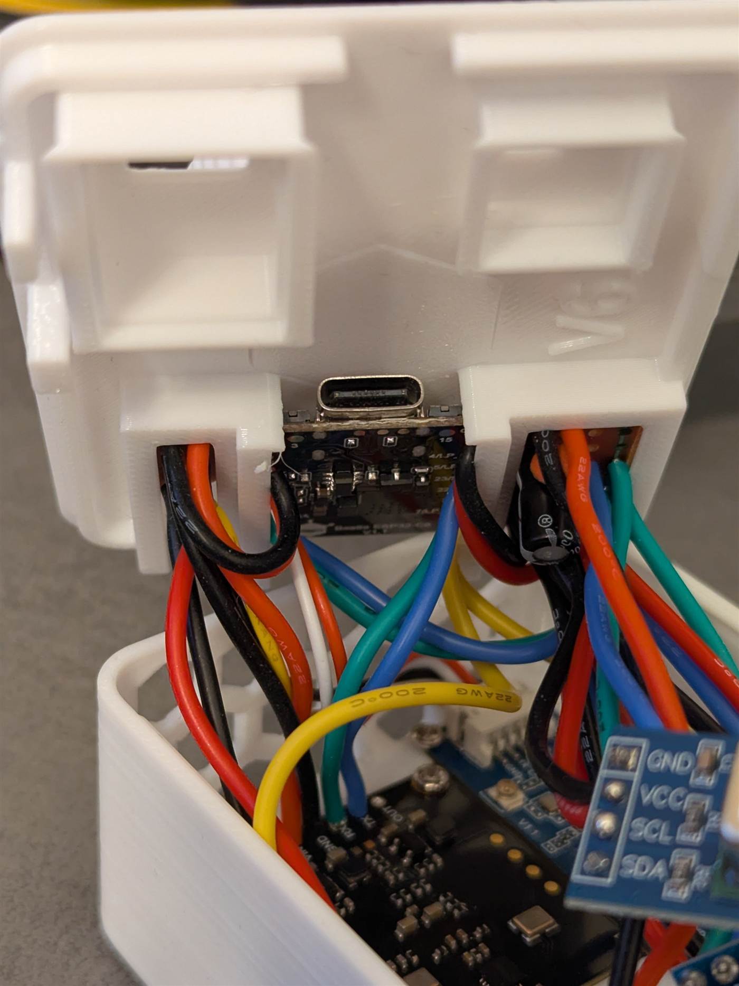
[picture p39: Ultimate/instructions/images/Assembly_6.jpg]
    
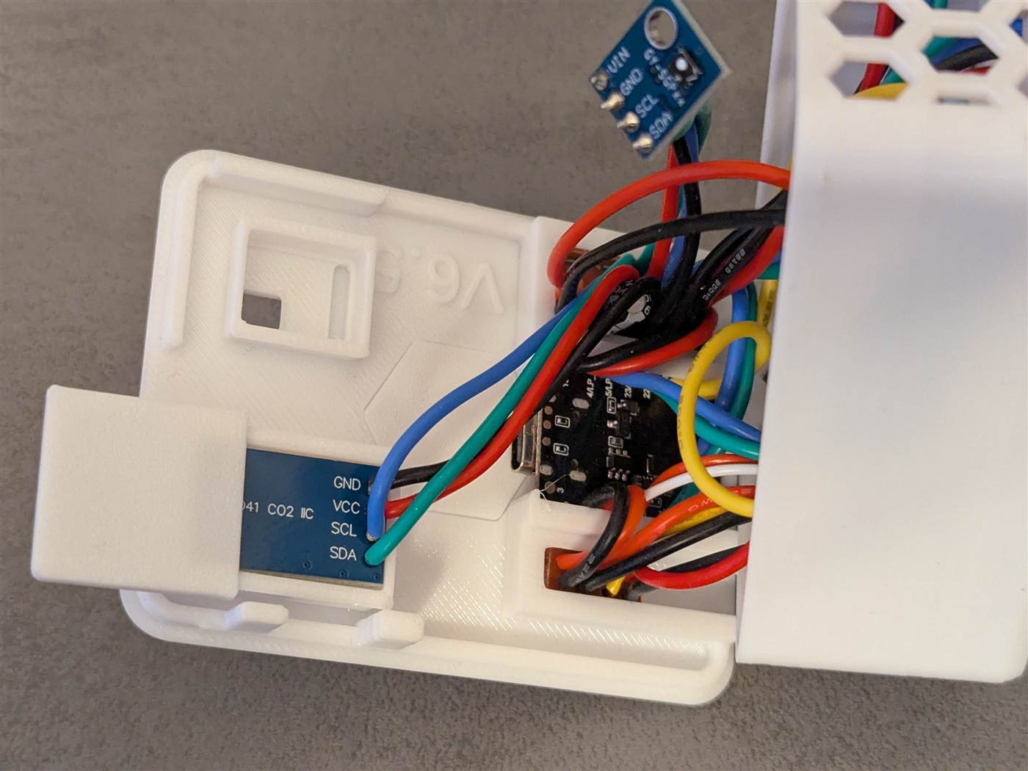
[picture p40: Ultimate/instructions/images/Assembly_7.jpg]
    
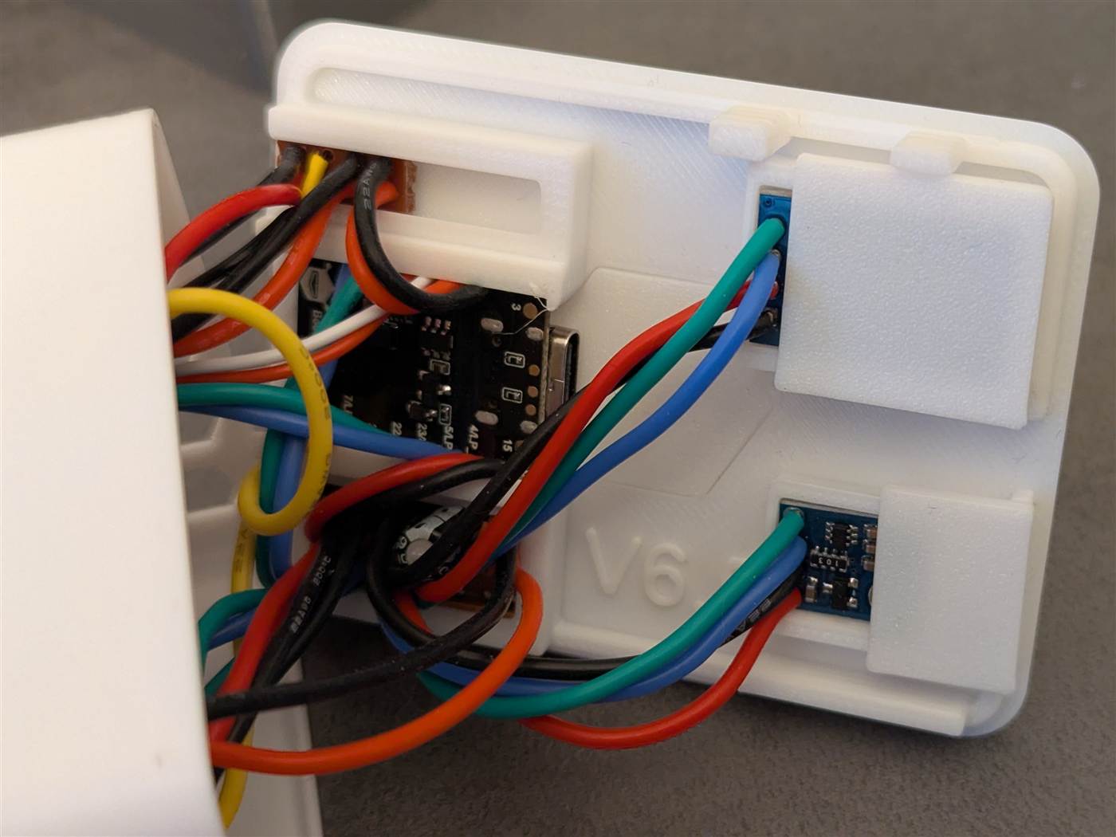
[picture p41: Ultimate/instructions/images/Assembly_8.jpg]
    
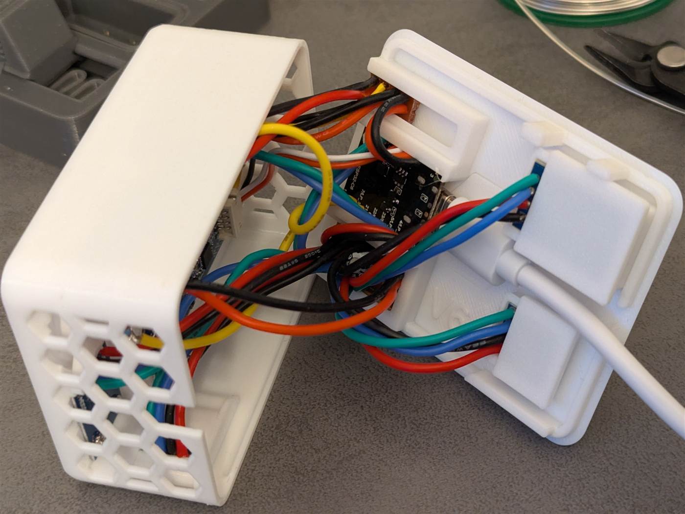
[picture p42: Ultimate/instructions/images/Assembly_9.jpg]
    
1. The case for the temperature sensor is used to hold it in place as well as shield it a bit from the heat produced by the other components
1. The SGP30 and SCD4X sensors do have shields that slide on to secure them in place
1. Attach the USB cable.
1. Close the lid — it **snaps** into place.

**Congratulations — you’re done!** 🥳🎉
Post a picture and a comment to this model — I’d love to see your results 🤗

### 💾 Software

This project uses [ESPHome](https://esphome.io/) as the underlying software. It's easy to set up and flash. It uses YAML files that define the sensors connected to the device and their properties. You can either checkout my code and compile it yourself or you can pick one of my precompiled firmware binaries and flash it. I won't provide general ESPHome compilation instructions — the official documentation is excellent:
Guide: <https://esphome.io/guides/installing_esphome/>

#### Flash my precompiled binaries

##### Initial installation

1. Navigate to [my Github](https://github.com/DerGary/all-in-one-sensor-device/releases?q=ultimate&expanded=true) and find the latest Release.
1. In the assets section find the binary that fits your setup. The variations are:
    - language = `de`/`en`
    - temperature sensor: `sht4x`/`bme280`
    - Pick the `factory` version for initial setup.
1. Navigate to [web.esphome.io](https://web.esphome.io/).
1. Connect the ESP to your computer.
    > **Troubleshooting: Factory-fresh boards cannot be flashed via web.esphome.io**
    > Factory-fresh ESP32-C6 boards bootloop out of the box and web.esphome.io cannot reliably connect to them. Use esptool or the ESPHome CLI instead:
    >
    > **Option 1 — esptool** (run repeatedly until it catches the device between reboots):
>
    > ```
    > esptool --chip esp32c6 --port COM3 write_flash 0x0 firmware.factory.bin
    >    ```
>
    > Replace `COM3` with your actual port number and `firmware.factory.bin` with the file you downloaded.
    >
    > **Option 2 — ESPHome CLI** (as described in the [Flash code directly](#flash-code-directly) section below):
    > Run the command repeatedly — it will catch the device in the brief window between reboots.

1. Click connect and choose the Serial Port (probably there is only one).
1. Click install, choose the `factory` binary file that you downloaded earlier
1. Click install and wait.
1. The LED will flash green after a successful install.
1. Open the Home Assistant app on your smartphone. Make sure that Bluetooth is turned on.
1. Open the ``integration and devices`` view. Home Assistant should pick up the sensor and you can click add.
1. Define WiFi Credentials and click ok.
1. After that you can add the ESPHome integration. Check your router for the ip address of the sensor.
1. Once deployed in its final location, proceed with calibration.

##### Update

1. Navigate to [my Github](https://github.com/DerGary/all-in-one-sensor-device/releases?q=ultimate&expanded=true) and find the latest Release.
1. In the assets section find the binary that fits your setup. The variations are:
    - language = `de`/`en`
    - temperature sensor: `sht4x`/`bme280`
    - Pick the ``ota`` version to update an existing sensor.
1. Navigate to the web page of the sensor by typing its IP address in your browser.
1. At the bottom of the page you will find the OTA update section.
1. Choose the previously downloaded file and click update.

#### Flash code directly

1. Install esphome
1. Checkout my [Github Repository](https://github.com/DerGary/all-in-one-sensor-device)
1. Navigate into the Ultimate folder in a terminal
1. execute `esphome -s lang en -s temp sht4x run device.yaml`
    - For ``temp`` you can choose between ``sht4x`` and ``bme280``
    - For ``lang`` you can choose between ``de`` and ``en``
1. After flashing proceed with adding the sensor to your home assistant instance as described in [initial installation](#initial-installation) section above.

#### OpenThread (instead of WiFi)

As an alternative to WiFi, the device can connect via **OpenThread** — useful if you already run a Thread border router (e.g. via Home Assistant's OTBR add-on) and want to keep the sensor off your WiFi network.

> **⚠️ There are no precompiled OpenThread binaries.** A Thread network's credentials (the "dataset") must be compiled directly into the firmware — unlike WiFi, there is no equivalent of Improv BLE to provide them after flashing. This means every Thread-connected device needs its own custom build with its own dataset baked in. Our CI only ever compiles the OpenThread variant as a build check with a placeholder dataset (`CHANGEME`) and never publishes it as a release asset, so downloading a `thread` binary from GitHub is not possible — you must build it yourself.

To build and flash with OpenThread:

1. Get your Thread dataset TLV from Home Assistant: **Settings → Devices & Services → Thread** integration → **Configure** → select your preferred network → click the info (ⓘ) icon → copy the **Dataset TLVs** value.
1. Install esphome and checkout the [Github Repository](https://github.com/DerGary/all-in-one-sensor-device) as described in [Flash code directly](#flash-code-directly) above.
1. Navigate into the `Ultimate` folder in a terminal.
1. execute `esphome -s lang <lang> -s temp <temp> -s connectivity thread -s openthread_tlv <your-tlv> run device.yaml`
    - For ``temp`` you can choose between ``sht4x`` and ``bme280``
    - For ``lang`` you can choose between ``de`` and ``en``
    - Replace `<your-tlv>` with the dataset TLV from step 1.
1. Once flashed, the device joins your Thread network directly — no WiFi pairing step is needed. Add it to Home Assistant the same way as any other Thread/Matter-adjacent ESPHome device on your network.

Switching back to WiFi later requires reflashing with `-s connectivity wifi_improv` (the default).

### 🏠 Home Assistant Entities

Below is a reference of all entities this device exposes in Home Assistant. Entities marked **Hidden** in the *HA visibility* column are not shown by default — enable them via the entity settings (cog icon) when you need them.

#### Combined Occupancy

| Entity | Type | HA visibility | Default value | Description |
| --- | ---- | --- | --- | --- |
| Occupancy | Binary sensor | Visible | — | The main signal for automations. Turns on when motion is detected and turns off only when both motion **and** presence are inactive simultaneously. PIR motion is required to trigger it; the radar presence sensors sustain it. |
| Presence | Binary sensor | Visible | — | True when either the C4001 or the LD2450 detects a target anywhere in range. Radar sensors have higher trigger latency than the PIR, so this signal responds more slowly to someone entering the room. Its main role is to feed into the Occupancy logic above — without it, Occupancy would turn off shortly after the PIR stops seeing movement, even if someone is still sitting in the room. |

#### Status LED

| Entity | Type | HA visibility | Default value | Description |
| --- | ---- | --- | --- | --- |
| Status-LED | Light | Visible | — | The WS2812 RGB status LED. Can be controlled manually from Home Assistant at any time, but will be overwritten by the automation whenever occupancy or air quality changes while the corresponding switch is on. |
| Show air quality through LED | Switch (config) | Visible | Off | When on, the LED pulses orange (warning) or red (critical) when air quality thresholds are exceeded. |
| Show occupancy through LED | Switch (config) | Visible | Off | When on, the LED glows warm white while the room is occupied. |
| Air Quality State | Text sensor | Visible | — | Current air quality alarm level: `Good`, `Warning`, or `Critical` (translated to the selected language). Warning triggers when CO₂ exceeds ~1250 ppm or TVOC exceeds ~660 ppb; critical when CO₂ exceeds ~2000 ppm or TVOC exceeds ~2200 ppb. Useful for custom automations that need to react to the same thresholds the LED uses. |

#### Temperature & Humidity

| Entity | Type | HA visibility | Default value | Description |
| --- | ---- | --- | --- | --- |
| Temperature | Sensor | Visible | — | Ambient temperature (°C), corrected by the offset below. |
| Humidity | Sensor | Visible | — | Relative humidity (%), corrected by the offset below. |
| Temperature Offset | Number (config) | Visible | 0.0 °C | Offset added to the raw temperature reading. Use to compensate for self-heating of the enclosure. |
| Humidity Offset | Number (config) | Visible | 0.0 % | Offset added to the raw humidity reading. |
| Air Pressure *(BME280 only)* | Sensor | Hidden | — | Barometric pressure (hPa). Only available when using the BME280 temperature sensor variant. |
| Temperature SCD | Sensor | Hidden | — | Temperature (°C) as measured by the SCD4x's internal sensor. These values cannot be calibrated with the current software — use the dedicated temperature sensor (SHT4x/BME280) and its offset entities above for accurate readings. |
| Humidity SCD | Sensor | Hidden | — | Relative humidity (%) as measured by the SCD4x's internal sensor. Same caveat as Temperature SCD — exposed for completeness only. |

#### Air Quality

| Entity | Type | HA visibility | Default value | Description |
| --- | ---- | --- | --- | --- |
| CO² | Sensor | Visible | — | CO₂ concentration (ppm) measured by the SCD4x. |
| TVOC | Sensor | Visible | — | Total volatile organic compounds (ppb) measured by the SGP30. |

#### Illuminance

| Entity | Type | HA visibility | Default value | Description |
| --- | ---- | --- | --- | --- |
| Illuminance | Sensor | Visible | — | Ambient light level (lux) from the BH1750. |

#### LD2450 Presence Sensor

| Entity | Type | HA visibility | Default value | Description |
| --- | ---- | --- | --- | --- |
| LD2450 Presence | Binary sensor | Hidden | — | True when the LD2450 alone detects at least one target. The combined **Presence** entity above is usually more useful. |
| LD2450 Presence Target Count | Sensor | Hidden | — | Number of targets currently tracked by the LD2450 (0–3). |
| LD2450 Multi Target Tracking | Switch | Hidden | On | When on, the LD2450 tracks up to 3 targets at once. When off, only the nearest target is reported. Leave on for zone-based detection. |
| LD2450 Max Distance | Number (config) | Hidden | 6.0 m | Maximum detection range (m). Targets beyond this distance are ignored. |
| LD2450 Max Angle | Number (config) | Hidden | 90° | Upper horizontal tilt angle limit (°). Lets you exclude targets above this elevation angle. |
| LD2450 Min Angle | Number (config) | Hidden | −90° | Lower horizontal tilt angle limit (°). |
| LD2450 Restart | Button | Hidden | — | Restarts the LD2450 sensor module (not the ESP). |
| LD2450 Factory Defaults | Button | Hidden | — | Resets the LD2450 to factory defaults. |
| LD2450 Bluetooth Mode | Switch | Hidden | Off | Enables Bluetooth on the LD2450 (for use with the vendor app). Disable when not needed to avoid interference. |

**Per-target diagnostics** (all hidden by default — enable Target 1 when mapping zone coordinates):

| Entity | Type | Default value | Description |
| --- | ---- | --- | --- |
| LD2450 Target-N X Position | Sensor | — | Horizontal position (m). Negative = left of sensor, positive = right. Enable to map zone corner coordinates. |
| LD2450 Target-N Y Position | Sensor | — | Distance in front of the sensor (m). Enable together with X Position to map coordinates. |
| LD2450 Target-N Distance | Sensor | — | Euclidean distance to the target (m). |
| LD2450 Target-N Speed | Sensor | — | Radial speed of the target (m/s). |
| LD2450 Target-N Angle | Sensor | — | Horizontal angle to the target (°). |
| LD2450 Target-N Distance Resolution | Sensor | — | Distance resolution reported by the sensor for this target. |

**Zone entities** — Zone 1 is visible by default. Zones 2 and 3 are fully hidden by default; enable them in Home Assistant when you need to track additional areas.

| Entity | Type | HA visibility | Default value | Description |
| --- | ---- | --- | --- | --- |
| LD2450 Zone-1 Occupancy | Binary sensor | Visible | — | True when at least one target is inside Zone 1's polygon. |
| LD2450 Zone-1 Count | Sensor | Visible | — | Number of targets currently inside Zone 1. |
| LD2450 Zone-1 Polygon | Text (config) | Visible | *(empty)* | Zone shape as `x1,y1;x2,y2;...` in meters. Zone is inactive until a valid polygon is entered. See [Calibration → LD2450](#-calibration) for the format. |
| LD2450 Zone-1 Margin | Number (config) | Visible | 0.25 m | Extra margin added around the polygon edges when testing whether a target is inside. |
| LD2450 Zone-2 / Zone-3 | (same set) | Hidden | (same) | Enable these in Home Assistant when you need to track a second or third area. |

#### C4001 Presence Sensor

| Entity | Type | HA visibility | Default value | Description |
| --- | ---- | --- | --- | --- |
| C4001 Presence | Binary sensor | Hidden | — | True when the C4001 detects a person. The combined **Presence** entity above is usually more useful. |
| C4001 Sustain Sensitivity | Number (config) | Visible | 7 | How sensitive the sensor is to keeping a detected person tracked (0–9). Lower = requires more movement to maintain presence. I found a value of 4 to work well. |
| C4001 Trigger Sensitivity | Number (config) | Visible | 7 | How sensitive the sensor is to initially detecting a person (0–9). Recommended range: 2–6. I found a value of 1 to work well. |
| C4001 Min Detection Distance | Number (config) | Visible | Sensor default | Minimum detection range (m). 0.6 m is a sensible starting value. |
| C4001 Max Detection Distance | Number (config) | Visible | Sensor default | Maximum detection range (m, up to 25 m). 6 m covers most rooms well. |
| C4001 Trigger Distance | Number (config) | Visible | 6 m | A person must enter within this distance to trigger the initial "occupied" state. Useful for ignoring distant, incidental movement at the edge of the detection zone. |
| C4001 Confirmation Latency | Number (config) | Hidden | Sensor default | Delay (s) before a newly detected presence is confirmed. |
| C4001 Disappearance Latency | Number (config) | Hidden | Sensor default | Delay (s) after the last detection before presence is cleared. |
| C4001 Blocking Time | Number (config) | Hidden | Sensor default | Minimum time (s) between consecutive trigger events. |
| **C4001 Save Configuration** | **Button** | **Visible** | **—** | **Changes to any C4001 setting above have no effect until this button is pressed. The driver does not send updated values to the sensor until you trigger a save.** |

#### Diagnostics & System

| Entity | Type | HA visibility | Default value | Description |
| --- | ---- | --- | --- | --- |
| [Device Name] Status | Binary sensor | Visible | — | True when the device is connected to Home Assistant. |
| Restart | Button | Visible | — | Restarts the ESP. |
| Uptime | Sensor | Visible | — | Time since last reboot (seconds). Unexpectedly low values indicate unplanned reboots. |
| Available Memory | Sensor | Hidden | — | Free heap memory (bytes). Should stay above ~40–50 kB for stable operation; lower values can cause unexpected reboots. |
| WiFi Signal Strength dB | Sensor | Hidden | — | RSSI of the connected access point (dB). Useful for debugging connectivity issues — values below −80 dB indicate a weak signal that may cause interruptions. This reflects the transmit power and distance of the access point only; it is not affected by the WiFi TX Power setting of this device. |
| WiFi TX Power | Number | Hidden | 8.5 dBm | WiFi transmit power of the ESP (dBm, 8.5–20). The default of 8.5 dBm is sufficient for most setups and minimises RF interference with the PIR sensor. Increase only if the device is far from the router and connectivity is unreliable. |

### 🎯 Calibration

Calibration is **non-trivial** and may take time and multiple iterations. I mainly use **offset calibration**, which is the easiest approach, though there are more accurate methods also available. If you mount the sensor high in the room (which improves presence detection) it will decrease the accuracy of the temperature sensor as hot air rises up. When you mount it high in the room you should use linear calibration to calibrate the temperature sensor.

**BME280 / SHT4X**:

Only **temperature** and **humidity** calibration is covered here. Air pressure calibration is not required for typical smart home use.

Let the device sit for **5–10 minutes** to heat-soak.

Place a trusted sensor nearby.

Calibrate humidity and temperature using the input components **Temperature Offset** and **Humidity Offset** directly in Home Assistant.

**LD2450 Presence Sensor:**

The LD2450 itself can't be calibrated, and the main presence detection (used by the device's overall presence/occupancy sensor) works out of the box — it reports a person as present anywhere within the sensor's range, whether or not they're standing inside a configured zone.

Zones are a separate, optional feature on top of that: they let you trigger automations based on a person being in a *specific* part of the room (e.g. "at the desk" or "on the couch"), rather than just "somewhere in range". You don't need to configure any zones for general presence detection to work. Zones are fully configurable from Home Assistant — no app and no reflashing required.

*Coordinate system*

- The sensor sits at the origin (`X = 0`, `Y = 0`).
- `Y` is the distance straight out in front of the sensor, in meters.
- `X` is the distance to the side, in meters — negative is to the left of the sensor, positive is to the right (as seen from behind the sensor, facing the same direction it does).

*Finding coordinates*

1. On the device page of your sensor in Home Assistant, enable the disabled-by-default entities **LD2450 Target-1 X Position** and **LD2450 Target-1 Y Position** (find the entity → click the cog icon → enable).
1. Walk to each corner of the area you want to outline as a zone and note the `X`/`Y` values these entities report while you stand there.
1. Once you have the coordinates you need, you can disable the target entities again — they update every second and add unnecessary load to the Home Assistant recorder, and aren't required for zone-based presence detection.

*Setting up a zone*

The firmware exposes 3 zones (`LD2450 Zone-1`, `LD2450 Zone-2`, `LD2450 Zone-3`). Each zone's shape is entered as a single text entity, e.g. `LD2450 Zone-1 Polygon`, found under the "Configuration" category. This means a zone isn't limited to a rectangle or a fixed number of corners — it can be any polygon, with as many corners as you need.

1. Pick one of the 3 zones.
1. In its `Polygon` text field, enter the corner coordinates you noted earlier as `x1,y1;x2,y2;x3,y3;...` — comma between X and Y of a point, semicolon between points, no spaces. Decimal values are supported using a **dot** as the decimal separator (e.g. `1.5`, never `1,5` — the comma is already the X/Y separator). Negative X values are valid and simply mean the point is to the left of the sensor (e.g. `-1.5,2` is 1.5 m to the left, 2 m in front). For example, a 3×4m rectangle starting at the sensor would be `0,0;0,4;3,4;3,0`, a narrower 1.5×3m zone offset to the right would be `0.5,0;0.5,3;2,3;2,0`, and a zone centered on the sensor spanning 2 m either side would be `-2,0;-2,4;2,4;2,0`.
1. Use at least 3 points, and go around the shape in order (clockwise or counter-clockwise, doesn't matter — just don't skip across the shape) so the points form a simple, non-self-intersecting polygon.
1. The shape must stay convex — picture a rectangle, a trapezoid, a diamond, or a hexagon, not a star, an arrow, or an L-shape. If you enter an invalid (too short, unparsable, self-intersecting, or non-convex) polygon, the sensor silently ignores the change and keeps the last valid shape, so you can't break anything by typing a half-finished value.
1. Repeat for additional zones if you want to track multiple areas — see the tips below for ideas on using more than one zone.

Zone polygons are re-evaluated every 30 seconds, so after editing the text field you may need to wait up to half a minute before the zone boundary takes effect. Once the new polygon is applied, the zone's target count will change from `unavailable` to `0` (or the current number of people inside). Note that entering an invalid polygon does not reset a zone — the previous valid shape stays active until a new valid one is accepted. To fully disable a zone, clear its text field to empty and reboot the sensor; the zone will then remain inactive until a valid polygon is entered again.

*Reading zone state*

- `LD2450 Zone-1 Occupancy`/`Zone-2 Occupancy`/`Zone-3 Occupancy` (binary sensor): on while at least one target is detected inside that zone. Use this in automations that should only react to a person being in that specific area.
- `LD2450 Zone-1 Count`/`Zone-2 Count`/`Zone-3 Count` (sensor): number of targets currently tracked inside that zone.
- Both entities share the same default name and are only distinguished by their entity type (binary sensor vs. sensor) — rename them in the entity settings if you'd like clearer labels on your dashboard, e.g. "Zone 1 Occupancy" / "Zone 1 Target Count".
- `LD2450 Presence` (binary sensor, disabled by default) and the main combined presence/occupancy sensor of the device are **not** affected by zones — they're on whenever any target is detected anywhere in range. Zones only add the extra, location-specific binary sensors described above.

*Tips*

- Zones are most useful for "only do X when someone is in this particular spot" automations — e.g. dim a light only when someone is at the desk, regardless of whether someone else is also present elsewhere in the room.
- If you do want a stricter "anyone in the room" signal than the sensor's raw range provides (e.g. to ignore detections through a doorway into a neighboring room), you can create a zone outlining your room's walls and use its occupancy sensor in your own automations instead of the default presence sensor.
- Zones can overlap, so the whole-room zone above can coexist with smaller, specific zones.
- If you need more than 3 zones, edit `sensors/ld2450.yaml` and reflash — 3 already covers most use cases.

**C4001 Presence Sensor:**

The C4001 Sensor got a couple of settings that can be changed. You can find the settings in the config section in Home Assistant. The main settings to calibrate are:

- Sustain / Trigger Sensitivity
  - The C4001 millimeter wave proximity sensor has two sensitivities: trigger sensitivity and hold sensitivity. Trigger sensitivity refers to the ease of triggering the sensor when entering the sensing area. Hold sensitivity refers to the sensitivity of continuous detection of the target after the sensor is triggered. Both trigger and hold sensitivities have 10 levels, with higher numbers indicating higher sensitivity and lower numbers indicating lower sensitivity. The default sensitivity value is 7
  - Note: Please configure the sensitivity according to the actual usage environment and requirements. Lower sensitivity requires larger movement amplitude and closer distance of the target to be detected. Higher sensitivity requires a higher demand for environmental interference. If there are interferences, it is more prone to false alarms. Setting the trigger sensitivity to 8 or 9 may cause a certain probability of false alarms, and it is mainly used in scenarios where false alarms are not sensitive. Generally, it is recommended to configure the trigger sensitivity between 2 and 6, with a value range of 0 to 9.
- Min / Max Distance
  - 0.6-25 meters
- Trigger Distance
  - The trigger distance of the C4001 millimeter wave presence sensor refers to the distance at which it can trigger from no one to someone. For example, if the maximum detection distance is configured as 10 meters, and the trigger distance is set to 6 meters, the sensor will only display "someone" when someone is within 6 meters. If someone is between 6-10 meters, it will not be triggered as "someone". The trigger distance can be set within the range of 0-25m, with a default of 6m.
  - Note: Configuring the trigger distance can optimize the problem of false triggering caused by slight movements at the edge. The smaller the trigger distance, the closer you need to be to the center axis of the sensor to trigger it. The trigger distance value cannot be greater than the difference between the maximum and minimum detection distances

> **⚠️ After changing any C4001 setting, press the C4001 Save Configuration button.** The driver does not send updated values to the sensor until you trigger a save — nothing changes in its behavior until you press this button.

### 🎯 Placement Considerations

1. When you mount the sensor high in the room it will improve presence sensing, but decrease temperature readings. Hot air rises and will skew and destabilize temperature readings.
1. Don’t place the device near a heater — it reduces temperature accuracy and can trigger the motion sensor.
1. Don’t place it directly in strong airflow (e.g., when airing the room), as the motion sensor detects rapid heat changes.

### 📢 Tips

- You can use the [underware collection](https://makerworld.com/de/models/783010-underware-2-0-infinite-cable-management?from=search#profileId-1504508) to route your cables.
- You can use [my cable clamps](https://makerworld.com/de/models/1744421-adhesive-cable-clamp-for-usb-cables-4mm-3mm#profileId-1853998) to route USB cables. They fit the cables linked here, use minimal filament, and can be attached with double-sided tape.
- You can use [my collection of ball head mounts](https://makerworld.com/de/collections/9129741-ball-head-mounts) to mount the device to cabinets, tubes, walls, desks etc.
- It’s preferable to position the device **facing the area where you stay** rather than just facing the door. The motion sensor has a wide field of view and covers most of the room, while the presence sensor works best when pointed directly at the target.

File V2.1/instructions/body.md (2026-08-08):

## 🔢 Steps

1. Source all the parts from the shopping list
1. Print the enclosure
1. Solder all sensors to the esp
1. Flash the ESP with the software and verify that all sensors work (connect it to your Home Assistant instance to monitor them).
1. Assemble the sensors and ESP into the enclosure.
1. Place the device in its designated spot.
1. After a few minutes, calibrate the sensors and re-flash the software.
1. Create your Home Assistant automations using the sensors.

### 🛒 Shopping List

You can also buy the parts from other sites. If you don’t mind waiting, AliExpress is usually cheaper. I’ve listed the exact products I used because I can confirm they worked for me.

| Name | Hint | Link |
| ----- | --- | --- |
| ESP32 | This case features several variants that fit different ESP form factors. <br> I would recommend the D1 Mini or Super Mini Variants | D1 Mini [Amazon](https://www.amazon.de/dp/B0FP2N2YNL) <br> D1 Mini [AliExpress](https://de.aliexpress.com/item/1005006414001036.html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) <br> ESP32 Large [Amazon](https://www.amazon.de/dp/B0D9BSKR16?ref_=ppx_hzsearch_conn_dt_b_fed_asin_title_2&th=1) <br> ESP32 C6 Super Mini [Aliexpress](https://de.aliexpress.com/item/1005009089500839.html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) (you need to choose the correct version manually) |
| Power Supply (PSU) | Any low-power PSU you already have should work. Otherwise, buy a simple one. | [Amazon](https://www.amazon.de/dp/B0D7MD5BJ3?ref=ppx_yo2ov_dt_b_fed_asin_title&th=1) |
| Temperatur Sensor BME280 or BME680 | BME680 air quality readings may not be reliable (see Disclaimer). | [BME280](https://amzn.eu/d/06HNHzUl) <br> [BME680](https://www.amazon.de/dp/B0CYH34X3P?ref=ppx_yo2ov_dt_b_fed_asin_title) |
| Screws | <ul><li>BME280/BME680 = 1x M2.5x3mm</li><li>Presence Sensor Shield = 3x M2x3mm</li><li>Motion Sensor HC-SR501 = 2x M2x3mm</li><li>Brightness Sensor BH170 = 2x M2x3mm</li></ul><br>You can try to use M2 for all the sensors but the BME280 sensor cutouts are too big for M2 head and might fall through. | [Amazon](https://www.amazon.de/dp/B0CZNT5YXV?ref=ppx_yo2ov_dt_b_fed_asin_title&th=1)|
| Brightness Sensor BH1750 | Works flawlessly for me, no hints necessary. | [Amazon](https://www.amazon.de/dp/B0D3WN41FS?ref=ppx_yo2ov_dt_b_fed_asin_title)|
| Motion Sensor HC-SR501 | The sensor case is specifically designed for a motion sensor with this form factor. I know they are not the best, but they are reasonably cheap, see Disclaimer for more details | [Amazon](https://www.amazon.de/dp/B0939XMBXJ?ref=ppx_yo2ov_dt_b_fed_asin_title) |
| Presence Sensor LD2410B | <ul><li>The sensor case is specifically designed for a presence sensor with this form factor. I experienced that they are not the best, but they are reasonably cheap, see Disclaimer for more details. </li><li>I recommend buying the sensor with pins and also buy the appropriate cable with it. Soldering these small pins is extremely hard and can even damage the sensor. Therefore I recommend attaching the cable using the plug and soldering only the side that must be attached to the ESP.</li></ul> | [Aliexpress](https://de.aliexpress.com/item/1005004920357733.html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) |
| LED | One segment of a WS2812 5V RGB LED. If you are like me you may have them already lying around at home 😄. | [Amazon](https://amzn.eu/d/0iexLtnJ) |
| Cables | I used 22 AWG wire | [Aliexpress](https://de.aliexpress.com/item/1005007671008743.html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) |
| Long USB Cable | Choose length to fit your setup. | [Aliexpress](https://de.aliexpress.com/item/1005007053181899.html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) |
| Filament | I printed my case in Kingroon White PLA and with Kingroon White PETG. You can use bambu labs filament of course. I printed the brightness sensor cover out of translucent PLA/PETG. | [Kingroon White PLA](https://de.aliexpress.com/item/1005007226921275.html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) <br> [Elegoo Transparent PLA](https://www.amazon.de/dp/B0CD7BS7B1?ref_=ppx_hzsearch_conn_dt_b_fed_asin_title_8) |
| Cable Distribution (Proto Boards) | I broke something off proto boards that I got lying around and used that to distribute the cables which needed to go to multiple sensors. I added a link to something similar. You can try a different approach. Don't try to solder every cable from every sensor directly to the ESP as this will be a mess 😅 | [Aliexpress](https://de.aliexpress.com/item/1005006236993083.html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) |

You also need:

- A soldering iron (and soldering skills)
- Solder
- Wire stripping tool
- Side cutters to trim the cables
- Screwdriver
- Pliers
- Desoldering pump (optional)
- Multimeter (optional if you trust your soldering skills)

### 🔢 Assembly Instructions

1. If you are using the ESP32 Large version you need to desolder the pins
    - Cut the black spacers into chunks of 4–5 pins and remove them with pliers.
    - Clamp the ESP in a vise [(I use a printable vise from Thingiverse)](https://www.thingiverse.com/thing:4764937).
    - Desolder the pins and pull them out with pliers. It’s also possible to heat the solder and pull the pins with pliers **without** a desoldering pump.
1. **Desolder Motion sensor (HC-SR501) pins:**
    - Remove the pin spacers with pliers.
    - Clamp the motion sensor in a vise.
    - Desolder and remove the pins. It’s also possible to heat the solder and pull the pins with pliers without a desoldering pump.
1. Break a **2×4** *(2x5 for Super Mini)* matrix from the proto board — for **motion** and **presence** sensors.
1. Break a **4×3** matrix from the proto board — for **brightness** and **temperature** sensors.
1. Cut wires to length. I wrote the length of the cables in mm into the connection drawings below. I show the two distribution boards separately to make things easier to follow. (There are further steps below on soldering order.) Pick the Connection Drawing that matches the ESP32 Version that you are using. The cable lengths and pinout slightly differs depending on the version.
    - I only a limited number of different colored cables. In the connection drawings I used the following colors:
        - red = 3.3V (BME/BH1750)
        - white/grey 5V(LD2410/HC-SR501/LED)
        - black = Ground
        - Green = I2C SCL/UART (If you have more colors you can use different colors for UART and I2C)
        - Blue = I2C SDA/UART (If you have more colors you can use different colors for UART and I2C)
        - Yellow = Motion Out
    - In the photos below I also used red for 5V, but make sure you don't mix 5V and 3.3V.

   #### D1 Mini

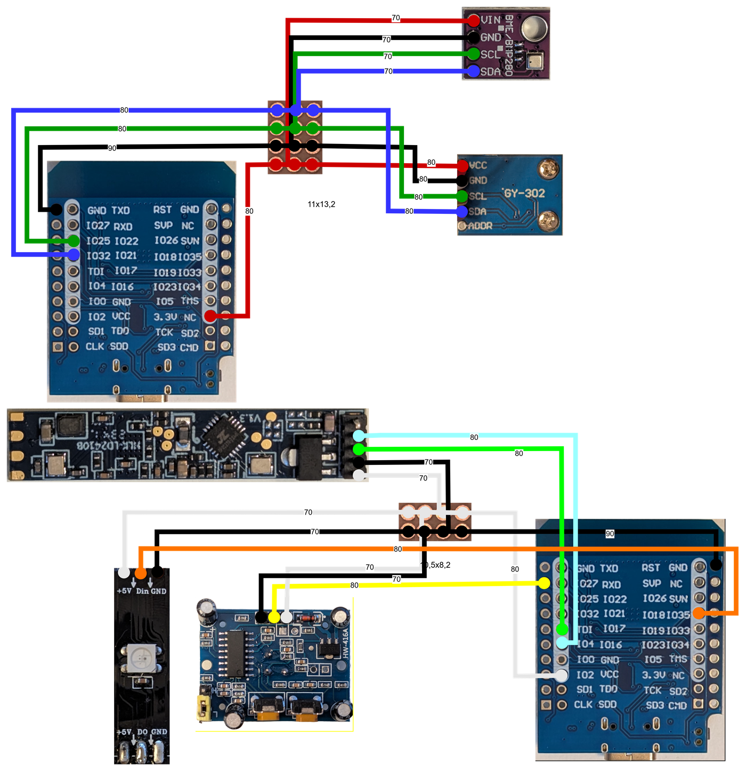
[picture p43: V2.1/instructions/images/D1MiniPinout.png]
D1 Mini Pinout
    

   #### ESP32 Large

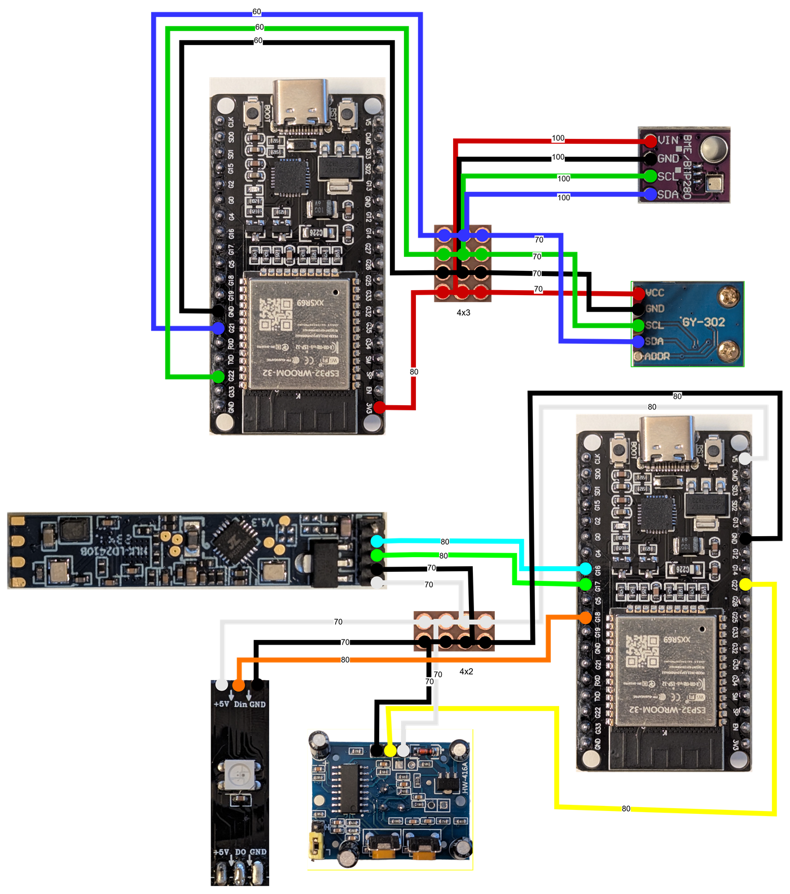
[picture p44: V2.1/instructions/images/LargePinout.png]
Large Pinout
    

   #### Super Mini

    The Ground of the two distribution boards are connected as the board only has one ground pin
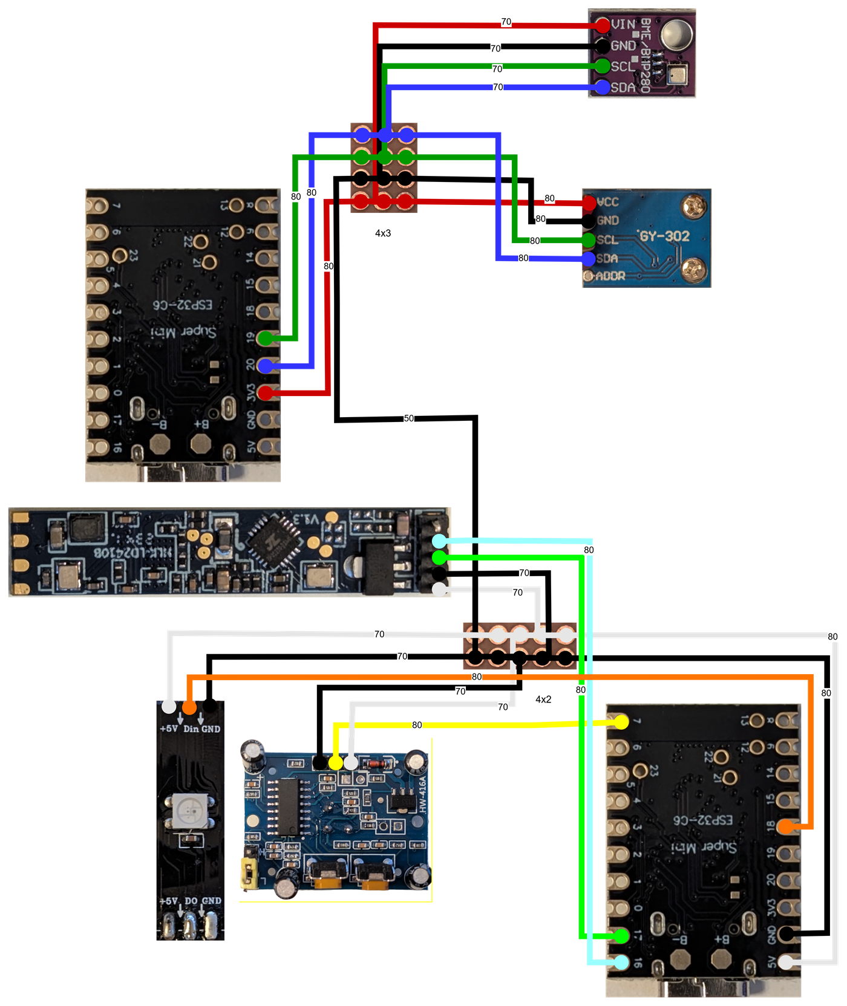
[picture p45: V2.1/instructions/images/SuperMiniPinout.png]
Super Mini Pinout
    

1. Make sure to tin the wire ends
1. Solder **one end** of each wire to the **sensors** as described in the Connection Drawings from Step 4

    | Motion Sensor | Presence Sensor | Brightness Sensor | Temperature Sensor | LED |
    | ---- | ---- | ---- | ---- | ---- |
    | Motion Sensor | Presence Sensor | Brightness Sensor | Temperature Sensor | LED |

1. Solder the **other end** of the wires to the **distribution proto boards and ESP respectively. Connect wires of the same color together**. If you used a proto board where the lines are already connected via the board you don't need to do any extra step. My proto board has separated solder points so I had to bridge them.

    - The 4x3 pin distribution board is connected to the brightness and temperature sensors.
    - The 2x4(2x5) pin distribution board is connected to the motion, presence sensors and LED.

    |4x3|2x4(2x5)|
    |---|---|
    | 4x3 pin distribution board | 2x3 pin distribution board |

1. **Solder the wires to the ESP pins** as described in the connection drawings above. You need to attach the cables from the back side (because the wifi antenna is on the front and we want that to be facing away from the motion sensor) — attach them as shown in the photos.

    | Large | D1 Mini |
    | --- | --- |
    | ESP Soldered Wires example | ESP Soldered Wires example |

1. Use a **multimeter** to verify that solder joints of different colors do not bridge. Any short can damage components and may cause smoke or even fire.
1. Now it's time to check whether all the soldering has worked out. Flash the software onto the ESP. It can be found in the software section. Verify that all sensors are detected and reporting, then return here to complete assembly.
1. Screw all the sensors in place using M2x3mm screws

    sensors in place

1. Screw the temperature sensor in place. For the BME680 There is already a cone protruding from the wall that holds the sensor in place on the lower screw hole. (1x M2.5x3mm)

    temperature sensors in place

1. Slide the **divider wall** into place. It shields the temperature sensor from ESP board heat. It won’t eliminate the effect entirely, but it’s an improvement.

    Divider Wall

1. Attach the **ball head** to the back of the enclosure.

    Ball Head Back

1. It might be a good idea to hide the ESP integrated status led with some electrical tape, depending on the brightness of the led. I got some really bright D1 Mini variants where the LED is disturbing.

    Ball Head Back

1. Slide the ESP32 into the rails on the backplate. And attach the USB cable.

    | D1 Mini | Super Mini |
    | --- | --- |
    | D1 Mini Rails | Super Mini Rails |

1. Slide the distribution boards into the rails on the backplate.

    | D1 Mini | Large |
    | --- | --- |
    | Distribution Board Rails | Distribution Board Rails |

1. Close the lid — it **snaps** into place.

    Closed Case

**Congratulations — you’re done!** 🥳🎉

Post a picture and a comment to this model — I’d love to see your results 🤗

### 💾 Software

This project uses [ESPHome](https://esphome.io/) as the underlying software. It’s easy to set up and flash. It uses YAML files that define the sensors connected to the device and their properties. You can either checkout my code and compile it yourself or you can pick one of my precompiled firmware binaries and flash it. I won’t provide general ESPHome compilation instructions — the official documentation is excellent:
Guide: <https://esphome.io/guides/installing_esphome/>

#### Flash my precompiled binaries

##### Initial installation

1. Navigate to [my Github](https://github.com/DerGary/all-in-one-sensor-device/releases?q=v2.1&expanded=true) and find the latest Release.
1. In the assets section find the binary that fits your setup. The variations are:
    - variant = ``esp32``/`esp32c6`
    - language = `de`/`en`
    - temperature sensor: `bme280`/`bme680`
    - Pick the `factory` version for initial setup.
1. Navigate to [web.esphome.io](https://web.esphome.io/).
1. Connect the esp to your computer.
1. Click connect and choose the Serial Port (probably there is only one).
1. Click install, choose the `factory` binary file that you downloaded earlier
1. Click install and wait.
1. The LED will flash green after a successful install.
1. Open the Home Assistant app on your smartphone. Make sure that Bluetooth is turned on.
1. Open the ``integration and devices`` view. Home Assistant should pick up the sensor and you can click add.
1. Define WiFi Credentials and click ok.
1. After that you can add the ESPHome integration. Check your router for the ip address of the sensor.
1. Once deployed in its final location, proceed with calibration.

##### Update

1. Navigate to [my Github](https://github.com/DerGary/all-in-one-sensor-device/releases?q=v2.1&expanded=true) and find the latest Release.
1. In the assets section find the binary that fits your setup. The variations are:
    - variant = ``esp32``/`esp32c6`
    - language = `de`/`en`
    - temperature sensor: `bme280`/`bme680`
    - Pick the ``ota`` version to update an existing sensor.
1. Navigate to the web page of the sensor by typing its IP address in your browser.
1. At the bottom of the page you will find the OTA update section.
1. Choose the previously downloaded file and click update.

#### Flash code directly

1. Install esphome
1. Checkout my [Github Repository](https://github.com/DerGary/all-in-one-sensor-device)
1. Navigate into the V2.1 folder in a terminal
1. execute `esphome -s variant esp32 -s temp bme280 -s lang de run device.yaml`
    - You can change ``esp32`` to any esphome compatible esp variant. Although you have to adhere to the **super mini** pinout when anything other than `esp32` is chosen here.
    - For ``temp`` you can choose between ``bme280`` and ``bme680``
    - For ``lang`` you can choose between ``de`` and ``en``
1. After flashing proceed with adding the sensor to your home assistant instance as described in [initial installation](#initial-installation) section above.

#### OpenThread (instead of WiFi)

As an alternative to WiFi, the device can connect via **OpenThread** — useful if you already run a Thread border router (e.g. via Home Assistant's OTBR add-on) and want to keep the sensor off your WiFi network. OpenThread requires the **esp32c6** variant, since it needs its 802.15.4 radio — the plain `esp32` variant cannot use it.

> **⚠️ There are no precompiled OpenThread binaries.** A Thread network's credentials (the "dataset") must be compiled directly into the firmware — unlike WiFi, there is no equivalent of Improv BLE to provide them after flashing. This means every Thread-connected device needs its own custom build with its own dataset baked in. Our CI only ever compiles the OpenThread variant as a build check with a placeholder dataset (`CHANGEME`) and never publishes it as a release asset, so downloading a `thread` binary from GitHub is not possible — you must build it yourself.

To build and flash with OpenThread:

1. Get your Thread dataset TLV from Home Assistant: **Settings → Devices & Services → Thread** integration → **Configure** → select your preferred network → click the info (ⓘ) icon → copy the **Dataset TLVs** value.
1. Install esphome and checkout the [Github Repository](https://github.com/DerGary/all-in-one-sensor-device) as described in [Flash code directly](#flash-code-directly) above.
1. Navigate into the `V2.1` folder in a terminal.
1. execute `esphome -s variant esp32c6 -s temp <temp> -s lang <lang> -s connectivity thread -s openthread_tlv <your-tlv> run device.yaml`
    - For ``temp`` you can choose between ``bme280`` and ``bme680``
    - For ``lang`` you can choose between ``de`` and ``en``
    - `variant` stays `esp32c6` — OpenThread needs its 802.15.4 radio.
    - Replace `<your-tlv>` with the dataset TLV from step 1.
1. Once flashed, the device joins your Thread network directly — no WiFi pairing step is needed. Add it to Home Assistant the same way as any other Thread/Matter-adjacent ESPHome device on your network.

Switching back to WiFi later requires reflashing with `-s connectivity wifi_improv` (the default).

#### Status LED

| Color | Pattern | Meaning |
| --- | --- | --- |
| Green | Fast Pulse | Sensor is waiting to be paired via Improv BLE |
| Pink | Fast Pulse | Sensor is not connected to wifi or home assistant |
| Warm White | Steady | When the occupancy automation is enabled, indicates that the area is occupied. |
| Orange | Slow Pulse | When the air quality automation is enabled, indicates that the air quality level is warning. |
| Red | Slow Pulse | When the air quality automation is enabled, indicates that the air quality level is critical. |

### 🎯 Calibration

Calibration is **non-trivial** and may take time and multiple iterations. I mainly use **offset calibration**, which is the easiest approach, though there are more accurate methods also available.

#### BME680 / BME280

I only calibrated **temperature** and **humidity**. I don’t use air pressure, and air quality is meant to auto-calibrate.

1. Let the device sit in its final location for **5–10 minutes** to saturate with heat from the ESP.
1. Place a **trusted temperature & humidity sensor** nearby.
1. Calibrate humidity and temperature using the input components **Temperature Offset** and **Humidity Offset** directly in Home Assistant.

#### Motion Sensor

The motion sensor has a jumper that defines the mode of the sensor.

- H (Repeat Trigger / Retriggerable mode)
  - As long as motion is detected, the output stays **HIGH**.
Example: If the delay time is set to 10 s and motion is detected again after 5 s, the timer resets and the output remains HIGH continuously until no more motion is detected.
- L (Single Trigger / Non-Retriggerable mode)
  - When motion is detected, the output goes **HIGH** for the set delay time, then returns to LOW — even if motion is still happening during that period. Only after the delay finishes and the sensor is ready again can it trigger once more.

The default seems to be **L**, while I use **H**.

The sensor has **two potentiometers**: one for **trigger time** and one for **sensitivity**. Looking from the back, the **left** is sensitivity and the **right** is time delay (I always mix them up 😅).

1. Set the **time delay** long enough that the presence sensor has already triggered, but short enough to release in a timely manner when a person leaves. This makes automations easier.
1. Set **sensitivity** just high enough to trigger where needed, but as low as possible to reduce false positives.
I set it to about there:

    HC-SR501 Knobs
    HC-SR501 Knobs

#### Presence Sensor

This sensor is the most challenging to calibrate. The g0-g8 values depict the different distances from the sensor.

1. **Enable Engineering Mode**
1. Ensure **no one is in the room** while calibrating.
1. Let the sensor sit for **10 minutes** while Home Assistant gathers **g0–g8 move/still** energy values.
1. Review the history of each **g0–g8** value in Home Assistant. Find the **highest** value each.
1. Set the **g0–g8 still thresholds** to **10 % higher** than the highest observed value for this distance.
1. Set the **g0–g8 move thresholds** to **20 % higher** than the highest observed value for this distance.
1. **Disable engineering mode**

### 🚫 Don'ts

1. Don’t mount the device **too high**. Hot air rises and will skew and destabilize temperature readings; it may also affect the motion sensor.
1. Don’t place the device **near a heater** — it reduces temperature accuracy and can trigger the motion sensor.
1. Don’t place it directly in strong airflow (e.g., when airing the room), as the motion sensor detects rapid heat changes.

### 📢 Tips

- You can use the [underware collection](https://makerworld.com/de/models/783010-underware-2-0-infinite-cable-management?from=search#profileId-1504508) to route your cables.
- You can use [**my cable clamps**](https://makerworld.com/de/models/1744421-adhesive-cable-clamp-for-usb-cables-4mm-3mm#profileId-1853998) to route USB cables. They fit the cables linked here, use minimal filament, and can be attached with double-sided tape.
- You can use [my collection of ball head mounts](https://makerworld.com/de/collections/9129741-ball-head-mounts) to mount the device to cabinets, tubes, walls, desks etc.
- It’s preferable to position the device **facing the area where you stay** rather than just facing the door. The motion sensor has a wide field of view and covers most of the room, while the presence sensor works best when pointed directly at the target.
- You can test all sensors with **jumper wires** before committing to soldering.

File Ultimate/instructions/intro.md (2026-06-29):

# Ultimate Smart Home Sensor Case

[Makerworld](https://makerworld.com/de/models/2946707-ultimate-smart-home-sensor-case#profileId-3300915)

## Please read the disclaimer at the bottom before printing

Hello everyone 👋. When I started building my smart home, I quickly realized that most devices only address very specific use cases. To achieve full functionality in each room, you typically need to combine several different sensors and devices. This complexity motivated me to start designing my own smart home sensor that combines multiple sensors into one device using 3D printing.

After releasing my first All-In-One Smart Home Sensor Case and [a subsequent Version 2](https://makerworld.com/de/models/2180710-all-in-one-smart-home-sensor-case-v2), my primary focus shifted toward improving sensor reliability—specifically reducing false positives from the PIR sensor and significantly improving still-presence detection.

This effort took more than a year and involved testing multiple sensor combinations, iterating on the enclosure design, and continuously refining the software stack. The result of that work is what I am releasing now: **the Ultimate Smart Home Sensor Case.**

My goals were the same as with the previous case, but to improve every aspect of it — creating the ultimate DIY smart home sensor device that integrates all the essential sensors needed to achieve the following:

## 🎯 Goals

1. Control the lighting in a room by turning it on when motion is detected and keeping it on as long as someone is present (even if the person is not moving).
1. Monitor the brightness in the room and only turn lights on if needed (and off again when no longer required).
1. Measure air quality, humidity, and temperature.
1. Use a status LED to indicate air quality or other system states
1. Use Bluetooth to track a person’s smartphone and thereby determine which room they are in, so the smart home can react accordingly.
1. Keep the footprint as small as possible.
1. Powered by a single cable. USB-C in particular.
1. Ensure the design is unobtrusive and blends seamlessly into the living room.
1. Integrate with Home Assistant.
1. No cloud dependency.

If you have any questions about the project please ask them in the comments then I can answer them and everyone can learn from that.

## 🖨️ Print Instructions

- **Material:** PLA/PETG
- **Layer Height:** 0.20 mm
- **Nozzle:** 0.4 mm
- **Infill:** 15 % Gyroid
- **Walls:** 2
- **Bottom Layers:** 4
- **Brightness sensor shield:** print with **transparent** material, or omit it entirely. It’s not required but hides the sensor a bit and improves the look.

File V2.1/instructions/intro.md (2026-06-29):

# All-In-One Smart Home Sensor Case V2.1

[Makerworld](https://makerworld.com/de/models/2180710-all-in-one-smart-home-sensor-case-v2#profileId-2381634)

## 🆕 Also check out the Ultimate Version

The V2.1 is the budget-friendly version of this series and will continue to be maintained and improved. For rooms where you need more — multi-target tracking, zone tracking, reliable presence detection for very still people (e.g. watching TV or sleeping), more accurate temperature & humidity, more sophisticated air quality measurements, or a more reliable PIR sensor — check out the [Ultimate Smart Home Sensor Case](https://makerworld.com/de/models/2946707-ultimate-smart-home-sensor-case). It comes at a higher component cost, but offers significantly more capability where it counts.

## Please read the disclaimer at the bottom before printing

Hello everyone 👋, this has been one of my biggest projects so far. If you have any questions about the project please ask them in the comments then I can answer them and everyone can learn from that.

When I started building my smart home, I realized that most devices only cover very specific use cases. To get full functionality in each room, you usually need to buy multiple different devices.

My goal with this project was to create **the ultimate DIY smart home sensor device** that integrates all the essential sensors needed to achieve the following:

## 🎯 Goals

1. Control the lighting in a room by turning it on when motion is detected and keeping it on as long as someone is present (even if the person is not moving).
1. Monitor the brightness in the room and only turn lights on if needed (and off again when no longer required).
1. Measure air quality, humidity, and temperature.
1. Use Bluetooth to track a person’s smartphone and thereby determine which room they are in, so the smart home can react accordingly.
1. Keep the footprint as small as possible.
1. Powered by a single cable. USB-C in particular.
1. Ensure the design is unobtrusive and blends seamlessly into the living room.
1. Integrate with Home Assistant.
1. No cloud dependency.

## 🖨️ Print Instructions

- **Material:** PLA/PETG
- **Layer Height:** 0.20 mm
- **Nozzle:** 0.4 mm
- **Infill:** 15 %
- **Walls:** 2
- **Divider:** print **upright** with a **brim**, flat side on the build plate. If you orient it differently, it won’t print correctly.
- **Brightness sensor shield:** print with **transparent** material, or omit it entirely. It’s not required but hides the sensor a bit and improves the look.

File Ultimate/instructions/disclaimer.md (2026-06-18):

# ⚠️ Disclaimer

This project is **not easy**: you have to solder a lot. In comparison to the previous case the sensors have normal pin sizes and are therefore a bit easier to solder. Nevertheless you have been warned — I’d love to see people build it 😊

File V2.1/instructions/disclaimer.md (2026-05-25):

### ⚠️ Disclaimer

This project is **not easy**: you have to solder a lot. You have been warned — but I’d love to see people try it 😊

The finished product is not perfect — that’s why the title is not *“Ultimate Smart Home Sensor Device”* 😅. I plan to release a revised version with other sensors when I have time and when the sensors I want become more accessible. Since I don’t know when that will be, I’m sharing this version for now.

**Things that bug me on the current version:**

1. **(This got a lot better on the V2 version, to a point where its not really an issue anymore, but it might happen and therefore is still listed here)** The motion sensor is very cheap and sometimes triggers when no one is in the room. (This can be minimized by **reducing the ESP’s Wi-Fi signal strength**, as cheap motion sensors are prone to misfire due to Wi-Fi interference.)
    - My latest firmware contains an optional slider to set the max wifi power. I recommend using the lowest value possible that still enables a stable wifi connection.
1. The motion sensor can trigger when you **air the room**, as it detects heat changes.
1. The presence sensor uses **24 GHz**. While it can detect mostly stationary humans, it cannot detect **very small movements** or someone under a blanket. (This mostly applies to my girlfriend — somehow I am tracked a bit better 😅).
1. The presence sensor is **extremely hard to solder**. I actually broke a sensor by accidentally desoldering the resistor right next to the pins. That is why I recommend using the separately available cable for it.

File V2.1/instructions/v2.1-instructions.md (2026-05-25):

# All-In-One Smart Home Sensor Case V2

## Please read the disclaimer at the bottom before printing

Hello everyone 👋, this has been one of my biggest projects so far. If you have any questions about the project please ask them in the comments then I can answer them and everyone can learn from that.

When I started building my smart home, I realized that most devices only cover very specific use cases. To get full functionality in each room, you usually need to buy multiple different devices.

My goal with this project was to create **the ultimate DIY smart home sensor device** that integrates all the essential sensors needed to achieve the following:

## 🎯 Goals

1. Control the lighting in a room by turning it on when motion is detected and keeping it on as long as someone is present (even if the person is not moving).
1. Monitor the brightness in the room and only turn lights on if needed (and off again when no longer required).
1. Measure air quality, humidity, and temperature.
1. Use Bluetooth to track a person’s smartphone and thereby determine which room they are in, so the smart home can react accordingly.
1. Keep the footprint as small as possible.
1. Powered by a single cable. USB-C in particular.
1. Ensure the design is unobtrusive and blends seamlessly into the living room.
1. Integrate with Home Assistant.
1. No cloud dependency.

## 🔢 Steps

1. Source all the parts from the shopping list
1. Print the enclosure
1. Solder all sensors to the esp
1. Flash the ESP with the software and verify that all sensors work (connect it to your Home Assistant instance to monitor them).
1. Assemble the sensors and ESP into the enclosure.
1. Place the device in its designated spot.
1. After a few minutes, calibrate the sensors and re-flash the software.
1. Create your Home Assistant automations using the sensors.

### 🛒 Shopping List

You can also buy the parts from other sites. If you don’t mind waiting, AliExpress is usually cheaper. I’ve listed the exact products I used because I can confirm they worked for me.

| Name | Hint | Link |
| ----- | --- | --- |
| ESP32 | This case features several variants that fit different ESP form factors. <br> I would recommend the D1 Mini or Super Mini Variants | D1 Mini [Amazon](https://www.amazon.de/dp/B0FP2N2YNL) <br> D1 Mini [AliExpress](https://de.aliexpress.com/item/1005006414001036.html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) <br> ESP32 Large [Amazon](https://www.amazon.de/dp/B0D9BSKR16?ref_=ppx_hzsearch_conn_dt_b_fed_asin_title_2&th=1) <br> ESP32 C6 Super Mini [Aliexpress](https://de.aliexpress.com/item/1005009089500839.html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) (you need to choose the correct version manually) |
| Power Supply (PSU) | Any low-power PSU you already have should work. Otherwise, buy a simple one. | [Amazon](https://www.amazon.de/dp/B0D7MD5BJ3?ref=ppx_yo2ov_dt_b_fed_asin_title&th=1) |
| Temperatur Sensor BME280 or BME680 | BME680 air quality readings may not be reliable (see Disclaimer). | [BME280](https://www.amazon.de/dp/B0CYH34X3P?ref=ppx_yo2ov_dt_b_fed_asin_title) <br> [BME680](https://www.amazon.de/dp/B0CYH34X3P?ref=ppx_yo2ov_dt_b_fed_asin_title) |
| Screws | <ul><li>BME280/BME680 = 1x M2.5x3mm</li><li>Presence Sensor Shield = 3x M2x3mm</li><li>Motion Sensor HC-SR501 = 2x M2x3mm</li><li>Brightness Sensor BH170 = 2x M2x3mm</li></ul><br>You can try to use M2 for all the sensors but the BME280 sensor cutouts are too big for M2 head and might fall through. | [Amazon](https://www.amazon.de/dp/B0CZNT5YXV?ref=ppx_yo2ov_dt_b_fed_asin_title&th=1)|
| Brightness Sensor BH1750 | Works flawlessly for me, no hints necessary. | [Amazon](https://www.amazon.de/dp/B0D3WN41FS?ref=ppx_yo2ov_dt_b_fed_asin_title)|
| Motion Sensor HC-SR501 | The sensor case is specifically designed for a motion sensor with this form factor. I know they are not the best, but they are reasonably cheap, see Disclaimer for more details | [Amazon](https://www.amazon.de/dp/B0939XMBXJ?ref=ppx_yo2ov_dt_b_fed_asin_title) |
| Presence Sensor LD2410B | <ul><li>The sensor case is specifically designed for a presence sensor with this form factor. I experienced that they are not the best, but they are reasonably cheap, see Disclaimer for more details. </li><li>The soldering points of this sensor are smaller than the ones of the other sensor and the esp. It is very hard to remove the pins. I would advise to buy the variant without the pins. </li><li>It might be possible to use jumper wires here so you don't have to solder, but the pins are smaller than the standard jumper wire ones and need the appropriate smaller jumper wires. </li><li>An alternative is to solder the wires directly to the pin headers, although this might be janky, it works and is way less hassle.</li></ul> | [Aliexpress](https://de.aliexpress.com/item/1005004920357733.html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) |
| LED | One segment of a WS2812 5V RGB LED  | [Amazon](https://amzn.eu/d/0iexLtnJ) |
| Cables | I used 22 AWG wire | [Aliexpress](https://de.aliexpress.com/item/1005007671008743.html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) |
| Long USB Cable | Choose length to fit your setup. | [Aliexpress](https://de.aliexpress.com/item/1005007053181899.html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) |
| Filament | I printed my case in Kingroon White PLA and with Kingroon White PETG. You can use bambu labs filament of course. I printed the brightness sensor cover out of translucent PLA/PETG. | [Kingroon White PLA](https://de.aliexpress.com/item/1005007226921275.html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) <br> [Elegoo Transparent PLA](https://www.amazon.de/dp/B0CD7BS7B1?ref_=ppx_hzsearch_conn_dt_b_fed_asin_title_8) |
| Cable Distribution (Proto Boards) | I broke something off proto boards that I got lying around and used that to distribute the cables which needed to go to multiple sensors. I added a link to something similar. You can try a different approach. Don't try to solder every cable from every sensor directly to the ESP as this will be a mess 😅 | [Aliexpress](https://de.aliexpress.com/item/1005006236993083.html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) |

You also need:

- A soldering iron (and soldering skills)
- Solder
- Wire stripping tool
- Side cutters to trim the cables
- Screwdriver
- Pliers
- Desoldering pump (optional)
- Multimeter (optional if you trust your soldering skills)

### 🖨️ Print Instructions

- **Material:** PLA/PETG
- **Layer Height:** 0.20 mm
- **Nozzle:** 0.4 mm
- **Infill:** 15 %
- **Walls:** 2
- **Divider:** print **upright** with a **brim**, flat side on the build plate. If you orient it differently, it won’t print correctly.
- **Brightness sensor shield:** print with **transparent** material, or omit it entirely. It’s not required but hides the sensor a bit and improves the look.

### 🔢 Assembly Instructions

1. If you are using the ESP32 Large version you need to desolder the pins
    - Cut the black spacers into chunks of 4–5 pins and remove them with pliers.
    - Clamp the ESP in a vise (I use a printable vise from Thingiverse).
    - Desolder the pins and pull them out with pliers. It’s also possible to heat the solder and pull the pins with pliers **without** a desoldering pump.
1. **Desolder Motion sensor (HC-SR501) pins:**
    - Remove the pin spacers with pliers.
    - Clamp the motion sensor in a vise.
    - Desolder and remove the pins. It’s also possible to heat the solder and pull the pins with pliers without a desoldering pump.
1. Break a **2×4** *(2x5 for Super Mini)* matrix from the proto board — for **motion** and **presence** sensors.
1. Break a **4×3** matrix from the proto board — for **brightness** and **temperature** sensors.
1. Cut wires to length. I wrote the length of the cables in mm into the connection drawings. I show the two distribution boards separately to make things easier to follow. (There are further steps below on soldering order.) Pick the Connection Drawing that matches the ESP32 Version that you are using. The cable lengths and pinout slightly differs depending on the version.
    - I only got 5 colors of cables
        - red = 3.3V (BME/BH1750)
        - white/grey 5V(LD2410/HC-SR501/LED)
        - black = Ground
        - Green = I2C SCL/UART (If you have more colors you can use different colors for UART and I2C)
        - Blue = I2C SDA/UART (If you have more colors you can use different colors for UART and I2C)
        - Yellow = Motion Out

   #### D1 Mini

    D1 Mini Pinout

   #### ESP32 Large

    Large Pinout

   #### Super Mini

    the Ground of the two distribution boards are connected as the board only has one ground pin
    Super Mini Pinout

1. Make sure to tin the wire ends
1. Solder **one end** of each wire to the **sensors** as described in the Connection Drawings from Step 4

    | Motion Sensor | Presence Sensor | Brightness Sensor | Temperature Sensor | LED |
    | ---- | ---- | ---- | ---- | ---- |
    | Motion Sensor | Presence Sensor | Brightness Sensor | Temperature Sensor | LED |

1. Solder the **other end** of the wires to the **distribution proto boards and ESP respectively. Connect wires of the same color together**. If you used a proto board where the lines are already connected via the board you don't need to do any extra step. My proto board has separated solder points so I had to bridge them.

    - The 4x3 pin distribution board is connected to the brightness and temperature sensors.
    - The 2x4(2x5) pin distribution board is connected to the motion, presence sensors and LED.

    |4x3|2x4(2x5)|
    |---|---|
    | 4x3 pin distribution board | 2x3 pin distribution board |

1. **Solder the wires to the ESP pins** as described in the connection drawings above. You need to attach the cables from the back side (because the wifi antenna is on the front and we want that to be facing away from the motion sensor) — attach them as shown in the photos.

    | Large | D1 Mini |
    | --- | --- |
    | ESP Soldered Wires example | ESP Soldered Wires example |

1. Use a **multimeter** to verify that solder joints of different colors do not bridge. Any short can damage components and may cause smoke or even fire.
1. Now it's time to check whether all the soldering has worked out. Flash the software onto the ESP. It can be found in the software section. Verify that all sensors are detected and reporting, then return here to complete assembly.
1. Screw all the sensors in place using M2x3mm screws

    sensors in place

1. Screw the temperature sensor in place. For the BME680 There is already a cone protruding from the wall that holds the sensor in place on the lower screw hole. (1x M2.5x3mm)

    temperature sensors in place

1. Slide the **divider wall** into place. It shields the temperature sensor from ESP board heat. It won’t eliminate the effect entirely, but it’s an improvement.

    Divider Wall

1. Attach the **ball head** to the back of the enclosure.

    Ball Head Back

1. It might be a good idea to hide the ESP integrated status led with some electrical tape, depending on the brightness of the led. I got some really bright D1 Mini variants where the LED is disturbing.

    Ball Head Back

1. Slide the ESP32 into the rails on the backplate. And attach the USB cable.

    | D1 Mini | Super Mini |
    | --- | --- |
    | D1 Mini Rails | Super Mini Rails |

1. Slide the distribution boards into the rails on the backplate.

    | D1 Mini | Large |
    | --- | --- |
    | Distribution Board Rails | Distribution Board Rails |

1. Close the lid — it **snaps** into place.

    Closed Case

**Congratulations — you’re done!** 🥳🎉

Post a picture and a comment to this model — I’d love to see your results 🤗

### 💾 Software

TODO: Software überarbeiten

This project uses [ESPHome](https://esphome.io/) as the underlying software. It’s easy to set up and flash. You need a single YAML file that defines the sensors connected to the device and their properties. I won’t provide general ESPHome flashing instructions — the official documentation is excellent:
Guide: <https://esphome.io/guides/installing_esphome/>

1. Download the source code from [my GitHub](https://github.com/DerGary/all-in-one-sensor-device/archive/refs/heads/main.zip)
1. Extract the zip file
1. Navigate to the V2 Folder
1. There is an esp32.yaml (for the D1 Mini and the ESP32 Large Version) and an esp32supermini.yaml (for the supermini version, with another pinout). Choose the one that matches your ESP version. You can copy the file multiple times and name it differently if you want to create multiple devices.
1. Change the **friendly name, name**, and optionally the **area** to your liking.
1. Also uncomment/comment out the includes for the language package and the sensor that you are using.
1. In **secrets.yaml**, set **wifi-password** and **wifi-ssid** to your Wi-Fi credentials.
1. Set the **esp-password** and **esp-username** to any values you like. If you create multiple devices you should set unique values for each of the device and rename the secrets to reflect that.
1. Set the **esp-api-key** to a value generated via the website: <https://esphome.io/components/api/#configuration-variables> This value is used to add the device to home assistant. If you create multiple devices you should set unique values for each of the device and rename the secrets to reflect that.
1. Run ``esphome run device.yaml`` to flash the device.
1. Test whether all sensors work as expected.
1. Once deployed in its final location, proceed with calibration.

### 🎯 Calibration

Calibration is **non-trivial** and may take time and multiple iterations. I mainly use **offset calibration**, which is the easiest approach, though there are more accurate methods also available.

#### BME680

I only calibrated **temperature** and **humidity**. I don’t use air pressure, and air quality is meant to auto-calibrate.

1. Let the device sit in its final location for **5–10 minutes** to saturate with heat from the ESP.
1. Place a **trusted temperature & humidity sensor** nearby.
1. In the **parameters** section of your ESPHome file, set ``bme680_temperature_offset`` to the difference between your device and the trusted sensor. Flash the new values — this also changes humidity readings.
1. Additionally you can calibrate humidity and temperature further using the input components **Temperature Offset** and **Humidity Offset** directly in Home Assistant.

#### BME280

Again, I only calibrated temperature and humidity; I don’t use air pressure.

1. Let the device sit for **5–10 minutes** to heat-soak.
1. Place a trusted sensor nearby.
1. Calibrate humidity and temperature using the input components **Temperature Offset** and **Humidity Offset** directly in Home Assistant.

#### Motion Sensor

The motion sensor has a jumper that defines the mode of the sensor.

- H (Repeat Trigger / Retriggerable mode)
  - As long as motion is detected, the output stays **HIGH**.
Example: If the delay time is set to 10 s and motion is detected again after 5 s, the timer resets and the output remains HIGH continuously until no more motion is detected.
- L (Single Trigger / Non-Retriggerable mode)
  - When motion is detected, the output goes **HIGH** for the set delay time, then returns to LOW — even if motion is still happening during that period. Only after the delay finishes and the sensor is ready again can it trigger once more.

The default seems to be **L**, while I use **H**.

The sensor has **two potentiometers**: one for **trigger time** and one for **sensitivity**. Looking from the back, the **left** is sensitivity and the **right** is time delay (I always mix them up 😅).

1. Set the **time delay** long enough that the presence sensor has already triggered, but short enough to release in a timely manner when a person leaves. This makes automations easier.
1. Set **sensitivity** just high enough to trigger where needed, but as low as possible to reduce false positives.
I set it to about there:

    HC-SR501 Knobs

Presence Sensor:

This sensor is the most challenging to calibrate. The g0-g8 values depict the different distances from the sensor.

1. **Enable Engineering Mode**
1. Ensure **no one is in the room** while calibrating.
1. Let the sensor sit for **10 minutes** while Home Assistant gathers **g0–g8 move/still** energy values.
1. Review the history of each **g0–g8** value in Home Assistant. Find the **highest** value each.
1. Set the **g0–g8 thresholds** to **5–10 % higher** than the highest observed value for this distance.
1. **Disable engineering mode**

### 🚫 Don'ts

1. Don’t mount the device **too high**. Hot air rises and will skew and destabilize temperature readings; it may also affect the motion sensor.
1. Don’t place the device **near a heater** — it reduces temperature accuracy and can trigger the motion sensor.
1. Don’t place it directly in strong airflow (e.g., when airing the room), as the motion sensor detects rapid heat changes.

### 📢 Tips

- You can use the [underware collection](https://makerworld.com/de/models/783010-underware-2-0-infinite-cable-management?from=search#profileId-1504508) to route your cables.
- You can use [**my cable clamps**](https://makerworld.com/de/models/1744421-adhesive-cable-clamp-for-usb-cables-4mm-3mm#profileId-1853998) to route USB cables. They fit the cables linked here, use minimal filament, and can be attached with double-sided tape.
- You can use [my collection of ball head mounts](https://makerworld.com/de/collections/9129741-ball-head-mounts) to mount the device to cabinets, tubes, walls, desks etc.
- It’s preferable to position the device **facing the area where you stay** rather than just facing the door. The motion sensor has a wide field of view and covers most of the room, while the presence sensor works best when pointed directly at the target.
- You can test all sensors with **jumper wires** before committing to soldering.

### ⚠️ Disclaimer

This project is **not easy**: you have to solder a lot, including **very small** pins. You have been warned — but I’d love to see people try it 😊

The finished product is not perfect — that’s why the title is not *“Ultimate Smart Home Sensor Device”* 😅. I plan to release a revised version with other sensors when I have time and when the sensors I want become more accessible. Since I don’t know when that will be, I’m sharing this version for now.

**Things that bug me on the current version:**

1. **(This got a lot better on the V2 version, to a point where its not really an issue anymore, but it might happen and therefore is still listed here)** The motion sensor is very cheap and sometimes triggers when no one is in the room. (This can be minimized by **reducing the ESP’s Wi-Fi signal strength**, as cheap motion sensors are prone to misfire due to Wi-Fi interference.)
1. The motion sensor can trigger when you **air the room**, as it detects heat changes.
1. The presence sensor uses **24 GHz**. While it can detect mostly stationary humans, it cannot detect **very small movements** or someone under a blanket. (This mostly applies to my girlfriend — somehow I am tracked a bit better 😅).
1. The presence sensor is **extremely hard to solder**. I actually broke a sensor by accidentally desoldering the resistor right next to the pins. I now solder the wires directly to the pins which is janky but it works and is a lot easier.

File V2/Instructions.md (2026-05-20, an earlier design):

# All-In-One Smart Home Sensor Case V2

## Please read the disclaimer at the bottom before printing

Hello everyone 👋, this has been one of my biggest projects so far. If you have any questions about the project please ask them in the comments then I can answer them and everyone can learn from that.

When I started building my smart home, I realized that most devices only cover very specific use cases. To get full functionality in each room, you usually need to buy multiple different devices.

My goal with this project was to create **the ultimate DIY smart home sensor device** that integrates all the essential sensors needed to achieve the following:

## 🎯 Goals

1. Control the lighting in a room by turning it on when motion is detected and keeping it on as long as someone is present (even if the person is not moving).
1. Monitor the brightness in the room and only turn lights on if needed (and off again when no longer required).
1. Measure air quality, humidity, and temperature.
1. Use Bluetooth to track a person’s smartphone and thereby determine which room they are in, so the smart home can react accordingly.
1. Keep the footprint as small as possible.
1. Powered by a single cable. USB-C in particular.
1. Ensure the design is unobtrusive and blends seamlessly into the living room.
1. Integrate with Home Assistant.
1. No cloud dependency.

## 🆕 Changes since the V1 Version

1. 3 different versions for different boards
    - Version for the ESP32 D1 Mini (no need to desolder the pins anymore 🥳).
    - Version for the ESP32 Super Mini (it should work with ESP32 C3/C6/S3, but i only tested it with the C6)
    - Version for the ESP32 Large Version
1. No need for jumper headers and wires / everything is soldered so it is a more secure connection
1. Separated wifi antenna and motion sensor farther apart to reduce false positive detections
1. Incorporate the ball head mount into the design, which is fully printable now and does not need a screw anymore.
1. The brightness sensor shield is now a solid part of the body. To print it you need an AMS or you have to remove that part before printing.
1. Tweaked the software
    - easier calibration experience
    - use of esp-idf framework which results in way less memory usage, so more features can be activated
    - added captive portal out of the box
    - german and english variant
    - used other uart pins, because using the uart0 will hinder from flashing the device via usb

## 🔢 Steps

1. Source all the parts from the shopping list
1. Print the enclosure
1. Solder all sensors to the esp
1. Flash the ESP with the software and verify that all sensors work (connect it to your Home Assistant instance to monitor them).
1. Assemble the sensors and ESP into the enclosure.
1. Place the device in its designated spot.
1. After a few minutes, calibrate the sensors and re-flash the software.
1. Create your Home Assistant automations using the sensors.

### 🛒 Shopping List

You can also buy the parts from other sites. If you don’t mind waiting, AliExpress is usually cheaper. I’ve listed the exact products I used because I can confirm they worked for me.

| Name | Hint | Link |
| ----- | --- | --- |
| ESP32 | This case features several variants that fit different ESP form factors. <br> I would recommend the D1 Mini or Super Mini Variants | D1 Mini [Amazon](https://www.amazon.de/dp/B0FP2N2YNL) <br> D1 Mini [AliExpress](https://de.aliexpress.com/item/1005006414001036.html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) <br> ESP32 Large [Amazon](https://www.amazon.de/dp/B0D9BSKR16?ref_=ppx_hzsearch_conn_dt_b_fed_asin_title_2&th=1) <br> ESP32 C6 Super Mini [Aliexpress](https://de.aliexpress.com/item/1005009089500839.html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) (you need to choose the correct version manually) |
| Power Supply (PSU) | Any low-power PSU you already have should work. Otherwise, buy a simple one. | [Amazon](https://www.amazon.de/dp/B0D7MD5BJ3?ref=ppx_yo2ov_dt_b_fed_asin_title&th=1) |
| Temperatur Sensor BME280 or BME680 | BME680 air quality readings may not be reliable (see Disclaimer). | [BME280](https://www.amazon.de/dp/B0CYH34X3P?ref=ppx_yo2ov_dt_b_fed_asin_title) <br> [BME680](https://www.amazon.de/dp/B0CYH34X3P?ref=ppx_yo2ov_dt_b_fed_asin_title) |
| Screws | <ul><li>BME280/BME680 = 1x M2.5x3mm</li><li>Presence Sensor Shield = 3x M2x3mm</li><li>Motion Sensor HC-SR501 = 2x M2x3mm</li><li>Brightness Sensor BH170 = 2x M2x3mm</li></ul><br>You can try to use M2 for all the sensors but the BME280 sensor cutouts are too big for M2 head and might fall through. | [Amazon](https://www.amazon.de/dp/B0CZNT5YXV?ref=ppx_yo2ov_dt_b_fed_asin_title&th=1)|
| Brightness Sensor BH1750 | Works flawlessly for me, no hints necessary. | [Amazon](https://www.amazon.de/dp/B0D3WN41FS?ref=ppx_yo2ov_dt_b_fed_asin_title)|
| Motion Sensor HC-SR501 | The sensor case is specifically designed for a motion sensor with this form factor. I know they are not the best, but they are reasonably cheap, see Disclaimer for more details | [Amazon](https://www.amazon.de/dp/B0939XMBXJ?ref=ppx_yo2ov_dt_b_fed_asin_title) |
| Presence Sensor LD2410B | <ul><li>The sensor case is specifically designed for a presence sensor with this form factor. I experienced that they are not the best, but they are reasonably cheap, see Disclaimer for more details. </li><li>The soldering points of this sensor are smaller than the ones of the other sensor and the esp. It is very hard to remove the pins. I would advise to buy the variant without the pins. </li><li>It might be possible to use jumper wires here so you don't have to solder, but the pins are smaller than the standard jumper wire ones and need the appropriate smaller jumper wires. </li><li>An alternative is to solder the wires directly to the pin headers, although this might be janky, it works and is way less hassle.</li></ul> | [Aliexpress](https://de.aliexpress.com/item/1005004920357733.html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) |
| Cables | I used 22 AWG wire | [Aliexpress](https://de.aliexpress.com/item/1005007671008743.html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) |
| Long USB Cable | Choose length to fit your setup. | [Aliexpress](https://de.aliexpress.com/item/1005007053181899.html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) |
| Filament | I printed my case in Kingroon White PLA and with Kingroon White PETG. You can use bambu labs filament of course. I printed the brightness sensor cover out of translucent PLA/PETG. | [Kingroon White PLA](https://de.aliexpress.com/item/1005007226921275.html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) <br> [Elegoo Transparent PLA](https://www.amazon.de/dp/B0CD7BS7B1?ref_=ppx_hzsearch_conn_dt_b_fed_asin_title_8) |
| Cable Distribution (Proto Boards) | I broke something off proto boards that I got lying around and used that to distribute the cables which needed to go to multiple sensors. I added a link to something similar. You can try a different approach. Don't try to solder every cable from every sensor directly to the ESP as this will be a mess 😅 | [Aliexpress](https://de.aliexpress.com/item/1005006236993083.html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) |

You also need:

- A soldering iron (and soldering skills)
- Solder
- Wire stripping tool
- Side cutters to trim the cables
- Screwdriver
- Pliers
- Desoldering pump (optional)
- Multimeter (optional if you trust your soldering skills)

### 🖨️ Print Instructions

- **Material:** PLA/PETG
- **Layer Height:** 0.20 mm
- **Nozzle:** 0.4 mm
- **Infill:** 15 %
- **Walls:** 2
- **Divider:** print **upright** with a **brim**, flat side on the build plate. If you orient it differently, it won’t print correctly.
- **Brightness sensor shield:** print with **transparent** material, or omit it entirely. It’s not required but hides the sensor a bit and improves the look.

### 🔢 Assembly Instructions

1. If you are using the ESP32 Large version you need to desolder the pins
1. **Desolder Motion sensor (HC-SR501) pins:**
    - Remove the pin spacers with pliers.
    - Clamp the motion sensor in a vise.
    - Desolder and remove the pins. It’s also possible to heat the solder and pull the pins with pliers without a desoldering pump.
1. Break a **2×3** matrix from the proto board — for **motion** and **presence** sensors.
1. Break a **4×3** matrix from the proto board — for **brightness** and **temperature** sensors.
1. Cut wires to length. I wrote the length of the cables in mm into the connection drawings. I show the two distribution boards separately to make things easier to follow. (There are further steps below on soldering order.) Pick the Connection Drawing that matches the ESP32 Version that you are using. The cable lengths and pinout slightly differs depending on the version.
    - I only got 5 colors of cables
        - red = Voltage (If you have more colors use different colors for 3.3V (BME/BH1750) and 5V(LD2410/HC-SR501), It is important to never mix them up)
        - black = Ground
        - Green = I2C SCL/UART (If you have more colors you can use different colors for UART and I2C)
        - Blue = I2C SDA/UART (If you have more colors you can use different colors for UART and I2C)
        - Yellow = Motion Out

   #### D1 Mini

    Temperature and Brightness sensors

    D1 Mini Temperature and Brightness sensors

    Presence and Motion Sensors

    D1 Mini Presence and Motion Sensors

   #### ESP32 Large

    Temperature and Brightness sensors
    Temperature and Brightness sensors

    Presence and Motion Sensors
    Presence and Motion Sensors

   #### Super Mini

    the Ground of the two distribution boards are connected as the board only has one ground pin
    Super Mini

1. Make sure to tin the wire ends
1. Solder **one end** of each wire to the **sensors** as described in the Connection Drawings from Step 4

    | Motion Sensor | Presence Sensor | Brightness Sensor | Temperature Sensor |
    | ---- | ---- | ---- | ---- |
    | Motion Sensor | Presence Sensor | Brightness Sensor | Temperature Sensor |

1. Solder the **other end** of the wires to the **distribution proto boards and ESP respectively. Connect wires of the same color together**. If you used a proto board where the lines are already connected via the board you don't need to do any extra step. My proto board has separated solder points so I had to bridge them.

    - The 4x3 pin distribution board is connected to the brightness and temperature sensors.
    - The 2x3 pin distribution board is connected to the motion and presence sensors.

    |4x3|2x3|
    |---|---|
    | 4x3 pin distribution board | 2x3 pin distribution board |

1. **Solder the wires to the ESP pins** as described in the connection drawings above. You need to attach the cables from the back side (because the wifi antenna is on the front and we want that to be facing away from the motion sensor) — attach them as shown in the photos.

    ESP Soldered Wires example

1. Use a **multimeter** to verify that solder joints of different colors do not bridge. Any short can damage components and may cause smoke or even fire.
1. Now it's time to check whether all the soldering has worked out. Flash the software onto the ESP. It can be found in the software section. Verify that all sensors are detected and reporting, then return here to complete assembly.
1. Screw all the sensors in place using M2x3mm screws

    sensors in place

1. Screw the temperature sensor in place. For the BME680 There is already a cone protruding from the wall that holds the sensor in place on the lower screw hole. (1x M2.5x3mm)

    temperature sensors in place

1. Slide the **divider wall** into place. It shields the temperature sensor from ESP board heat. It won’t eliminate the effect entirely, but it’s an improvement.

    Divider Wall

1. Attach the **ball head** to the back of the enclosure.

    Ball Head Back

1. Slide the ESP32 into the rails on the backplate. And attach the USB cable.

    D1 Mini Rails
    Super Mini Rails

1. Slide the distribution boards into the rails on the backplate.

    Distribution Board Rails

1. Close the lid — it **snaps** into place.

    Closed Case

**Congratulations — you’re done!** 🥳🎉

Post a picture and a comment to this model — I’d love to see your results 🤗

### 💾 Software

This project uses [ESPHome](https://esphome.io/) as the underlying software. It’s easy to set up and flash. You need a single YAML file that defines the sensors connected to the device and their properties. I won’t provide general ESPHome flashing instructions — the official documentation is excellent:
Guide: <https://esphome.io/guides/installing_esphome/>

1. Download the source code from [my GitHub](https://github.com/DerGary/all-in-one-sensor-device/archive/refs/heads/main.zip)
1. Extract the zip file
1. Navigate to the V2 Folder
1. There is an esp32.yaml (for the D1 Mini and the ESP32 Large Version) and an esp32supermini.yaml (for the supermini version, with another pinout). Choose the one that matches your ESP version. You can copy the file multiple times and name it differently if you want to create multiple devices.
1. Change the **friendly name, name**, and optionally the **area** to your liking.
1. Also uncomment/comment out the includes for the language package and the sensor that you are using.
1. In **secrets.yaml**, set **wifi-password** and **wifi-ssid** to your Wi-Fi credentials.
1. Set the **esp-password** and **esp-username** to any values you like. If you create multiple devices you should set unique values for each of the device and rename the secrets to reflect that.
1. Set the **esp-api-key** to a value generated via the website: <https://esphome.io/components/api/#configuration-variables> This value is used to add the device to home assistant. If you create multiple devices you should set unique values for each of the device and rename the secrets to reflect that.
1. Run ``esphome run device.yaml`` to flash the device.
1. Test whether all sensors work as expected.
1. Once deployed in its final location, proceed with calibration.

### 🎯 Calibration

Calibration is **non-trivial** and may take time and multiple iterations. I mainly use **offset calibration**, which is the easiest approach, though there are more accurate methods also available.

#### BME680

I only calibrated **temperature** and **humidity**. I don’t use air pressure, and air quality is meant to auto-calibrate.

1. Let the device sit in its final location for **5–10 minutes** to saturate with heat from the ESP.
1. Place a **trusted temperature & humidity sensor** nearby.
1. In the **parameters** section of your ESPHome file, set ``bme680_temperature_offset`` to the difference between your device and the trusted sensor. Flash the new values — this also changes humidity readings.
1. Additionally you can calibrate humidity and temperature further using the input components **Temperature Offset** and **Humidity Offset** directly in Home Assistant.

#### BME280

Again, I only calibrated temperature and humidity; I don’t use air pressure.

1. Let the device sit for **5–10 minutes** to heat-soak.
1. Place a trusted sensor nearby.
1. Calibrate humidity and temperature using the input components **Temperature Offset** and **Humidity Offset** directly in Home Assistant.

#### Motion Sensor

The motion sensor has a jumper that defines the mode of the sensor.

- H (Repeat Trigger / Retriggerable mode)
  - As long as motion is detected, the output stays **HIGH**.
Example: If the delay time is set to 10 s and motion is detected again after 5 s, the timer resets and the output remains HIGH continuously until no more motion is detected.
- L (Single Trigger / Non-Retriggerable mode)
  - When motion is detected, the output goes **HIGH** for the set delay time, then returns to LOW — even if motion is still happening during that period. Only after the delay finishes and the sensor is ready again can it trigger once more.

The default seems to be **L**, while I use **H**.

The sensor has **two potentiometers**: one for **trigger time** and one for **sensitivity**. Looking from the back, the **left** is sensitivity and the **right** is time delay (I always mix them up 😅).

1. Set the **time delay** long enough that the presence sensor has already triggered, but short enough to release in a timely manner when a person leaves. This makes automations easier.
1. Set **sensitivity** just high enough to trigger where needed, but as low as possible to reduce false positives.
I set it to about there:

    HC-SR501 Knobs

Presence Sensor:

This sensor is the most challenging to calibrate. The g0-g8 values depict the different distances from the sensor.

1. **Enable Engineering Mode**
1. Ensure **no one is in the room** while calibrating.
1. Let the sensor sit for **10 minutes** while Home Assistant gathers **g0–g8 move/still** energy values.
1. Review the history of each **g0–g8** value in Home Assistant. Find the **highest** value each.
1. Set the **g0–g8 thresholds** to **5–10 % higher** than the highest observed value for this distance.
1. **Disable engineering mode**

### 🚫 Don'ts

1. Don’t mount the device **too high**. Hot air rises and will skew and destabilize temperature readings; it may also affect the motion sensor.
1. Don’t place the device **near a heater** — it reduces temperature accuracy and can trigger the motion sensor.
1. Don’t place it directly in strong airflow (e.g., when airing the room), as the motion sensor detects rapid heat changes.

### 📢 Tips

- You can use the [underware collection](https://makerworld.com/de/models/783010-underware-2-0-infinite-cable-management?from=search#profileId-1504508) to route your cables.
- You can use [**my cable clamps**](https://makerworld.com/de/models/1744421-adhesive-cable-clamp-for-usb-cables-4mm-3mm#profileId-1853998) to route USB cables. They fit the cables linked here, use minimal filament, and can be attached with double-sided tape.
- You can use [my collection of ball head mounts](https://makerworld.com/de/collections/9129741-ball-head-mounts) to mount the device to cabinets, tubes, walls, desks etc.
- It’s preferable to position the device **facing the area where you stay** rather than just facing the door. The motion sensor has a wide field of view and covers most of the room, while the presence sensor works best when pointed directly at the target.
- You can test all sensors with **jumper wires** before committing to soldering.

### ⚠️ Disclaimer

This project is **not easy**: you have to solder a lot, including **very small** pins. You have been warned — but I’d love to see people try it 😊

The finished product is not perfect — that’s why the title is not *“Ultimate Smart Home Sensor Device”* 😅. I plan to release a revised version with other sensors when I have time and when the sensors I want become more accessible. Since I don’t know when that will be, I’m sharing this version for now.

**Things that bug me on the current version:**

1. **(This got a lot better on the V2 version, to a point where its not really an issue anymore, but it might happen and therefore is still listed here)** The motion sensor is very cheap and sometimes triggers when no one is in the room. (This can be minimized by **reducing the ESP’s Wi-Fi signal strength**, as cheap motion sensors are prone to misfire due to Wi-Fi interference.)
1. The motion sensor can trigger when you **air the room**, as it detects heat changes.
1. The presence sensor uses **24 GHz**. While it can detect mostly stationary humans, it cannot detect **very small movements** or someone under a blanket. (This mostly applies to my girlfriend — somehow I am tracked a bit better 😅).
1. The presence sensor is **extremely hard to solder**. I actually broke a sensor by accidentally desoldering the resistor right next to the pins. I now solder the wires directly to the pins which is janky but it works and is a lot easier.

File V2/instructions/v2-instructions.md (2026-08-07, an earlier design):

# All-In-One Smart Home Sensor Case V2

## Please read the disclaimer at the bottom before printing

Hello everyone 👋, this has been one of my biggest projects so far. If you have any questions about the project please ask them in the comments then I can answer them and everyone can learn from that.

When I started building my smart home, I realized that most devices only cover very specific use cases. To get full functionality in each room, you usually need to buy multiple different devices.

My goal with this project was to create **the ultimate DIY smart home sensor device** that integrates all the essential sensors needed to achieve the following:

## 🎯 Goals

1. Control the lighting in a room by turning it on when motion is detected and keeping it on as long as someone is present (even if the person is not moving).
1. Monitor the brightness in the room and only turn lights on if needed (and off again when no longer required).
1. Measure air quality, humidity, and temperature.
1. Use Bluetooth to track a person’s smartphone and thereby determine which room they are in, so the smart home can react accordingly.
1. Keep the footprint as small as possible.
1. Powered by a single cable. USB-C in particular.
1. Ensure the design is unobtrusive and blends seamlessly into the living room.
1. Integrate with Home Assistant.
1. No cloud dependency.

## 🆕 Changes since the V1 Version

1. 3 different versions for different boards
    - Version for the ESP32 D1 Mini (no need to desolder the pins anymore 🥳).
    - Version for the ESP32 Super Mini (it should work with ESP32 C3/C6/S3, but i only tested it with the C6)
    - Version for the ESP32 Large Version
1. No need for jumper headers and wires / everything is soldered so it is a more secure connection
1. Separated wifi antenna and motion sensor farther apart to reduce false positive detections
1. Incorporate the ball head mount into the design, which is fully printable now and does not need a screw anymore.
1. The brightness sensor shield is now a solid part of the body. To print it you need an AMS or you have to remove that part before printing.
1. Tweaked the software
    - easier calibration experience
    - use of esp-idf framework which results in way less memory usage, so more features can be activated
    - added captive portal out of the box
    - german and english variant
    - used other uart pins, because using the uart0 will hinder from flashing the device via usb

## 🔢 Steps

1. Source all the parts from the shopping list
1. Print the enclosure
1. Solder all sensors to the esp
1. Flash the ESP with the software and verify that all sensors work (connect it to your Home Assistant instance to monitor them).
1. Assemble the sensors and ESP into the enclosure.
1. Place the device in its designated spot.
1. After a few minutes, calibrate the sensors and re-flash the software.
1. Create your Home Assistant automations using the sensors.

### 🛒 Shopping List

You can also buy the parts from other sites. If you don’t mind waiting, AliExpress is usually cheaper. I’ve listed the exact products I used because I can confirm they worked for me.

| Name | Hint | Link |
| ----- | --- | --- |
| ESP32 | This case features several variants that fit different ESP form factors. <br> I would recommend the D1 Mini or Super Mini Variants | D1 Mini [Amazon](https://www.amazon.de/dp/B0FP2N2YNL) <br> D1 Mini [AliExpress](https://de.aliexpress.com/item/1005006414001036.html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) <br> ESP32 Large [Amazon](https://www.amazon.de/dp/B0D9BSKR16?ref_=ppx_hzsearch_conn_dt_b_fed_asin_title_2&th=1) <br> ESP32 C6 Super Mini [Aliexpress](https://de.aliexpress.com/item/1005009089500839.html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) (you need to choose the correct version manually) |
| Power Supply (PSU) | Any low-power PSU you already have should work. Otherwise, buy a simple one. | [Amazon](https://www.amazon.de/dp/B0D7MD5BJ3?ref=ppx_yo2ov_dt_b_fed_asin_title&th=1) |
| Temperatur Sensor BME280 or BME680 | BME680 air quality readings may not be reliable (see Disclaimer). | [BME280](https://amzn.eu/d/06HNHzUl) <br> [BME680](https://www.amazon.de/dp/B0CYH34X3P?ref=ppx_yo2ov_dt_b_fed_asin_title) |
| Screws | <ul><li>BME280/BME680 = 1x M2.5x3mm</li><li>Presence Sensor Shield = 3x M2x3mm</li><li>Motion Sensor HC-SR501 = 2x M2x3mm</li><li>Brightness Sensor BH170 = 2x M2x3mm</li></ul><br>You can try to use M2 for all the sensors but the BME280 sensor cutouts are too big for M2 head and might fall through. | [Amazon](https://www.amazon.de/dp/B0CZNT5YXV?ref=ppx_yo2ov_dt_b_fed_asin_title&th=1)|
| Brightness Sensor BH1750 | Works flawlessly for me, no hints necessary. | [Amazon](https://www.amazon.de/dp/B0D3WN41FS?ref=ppx_yo2ov_dt_b_fed_asin_title)|
| Motion Sensor HC-SR501 | The sensor case is specifically designed for a motion sensor with this form factor. I know they are not the best, but they are reasonably cheap, see Disclaimer for more details | [Amazon](https://www.amazon.de/dp/B0939XMBXJ?ref=ppx_yo2ov_dt_b_fed_asin_title) |
| Presence Sensor LD2410B | <ul><li>The sensor case is specifically designed for a presence sensor with this form factor. I experienced that they are not the best, but they are reasonably cheap, see Disclaimer for more details. </li><li>The soldering points of this sensor are smaller than the ones of the other sensor and the esp. It is very hard to remove the pins. I would advise to buy the variant without the pins. </li><li>It might be possible to use jumper wires here so you don't have to solder, but the pins are smaller than the standard jumper wire ones and need the appropriate smaller jumper wires. </li><li>An alternative is to solder the wires directly to the pin headers, although this might be janky, it works and is way less hassle.</li></ul> | [Aliexpress](https://de.aliexpress.com/item/1005004920357733.html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) |
| Cables | I used 22 AWG wire | [Aliexpress](https://de.aliexpress.com/item/1005007671008743.html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) |
| Long USB Cable | Choose length to fit your setup. | [Aliexpress](https://de.aliexpress.com/item/1005007053181899.html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) |
| Filament | I printed my case in Kingroon White PLA and with Kingroon White PETG. You can use bambu labs filament of course. I printed the brightness sensor cover out of translucent PLA/PETG. | [Kingroon White PLA](https://de.aliexpress.com/item/1005007226921275.html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) <br> [Elegoo Transparent PLA](https://www.amazon.de/dp/B0CD7BS7B1?ref_=ppx_hzsearch_conn_dt_b_fed_asin_title_8) |
| Cable Distribution (Proto Boards) | I broke something off proto boards that I got lying around and used that to distribute the cables which needed to go to multiple sensors. I added a link to something similar. You can try a different approach. Don't try to solder every cable from every sensor directly to the ESP as this will be a mess 😅 | [Aliexpress](https://de.aliexpress.com/item/1005006236993083.html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) |

You also need:

- A soldering iron (and soldering skills)
- Solder
- Wire stripping tool
- Side cutters to trim the cables
- Screwdriver
- Pliers
- Desoldering pump (optional)
- Multimeter (optional if you trust your soldering skills)

### 🖨️ Print Instructions

- **Material:** PLA/PETG
- **Layer Height:** 0.20 mm
- **Nozzle:** 0.4 mm
- **Infill:** 15 %
- **Walls:** 2
- **Divider:** print **upright** with a **brim**, flat side on the build plate. If you orient it differently, it won’t print correctly.
- **Brightness sensor shield:** print with **transparent** material, or omit it entirely. It’s not required but hides the sensor a bit and improves the look.

### 🔢 Assembly Instructions

1. If you are using the ESP32 Large version you need to desolder the pins
    - Cut the black spacers into chunks of 4–5 pins and remove them with pliers.
    - Clamp the ESP in a vise (I use a printable vise from Thingiverse).
    - Desolder the pins and pull them out with pliers. It’s also possible to heat the solder and pull the pins with pliers **without** a desoldering pump.
1. **Desolder Motion sensor (HC-SR501) pins:**
    - Remove the pin spacers with pliers.
    - Clamp the motion sensor in a vise.
    - Desolder and remove the pins. It’s also possible to heat the solder and pull the pins with pliers without a desoldering pump.
1. Break a **2×3** *(2x4 for Super Mini)* matrix from the proto board — for **motion** and **presence** sensors.
1. Break a **4×3** matrix from the proto board — for **brightness** and **temperature** sensors.
1. Cut wires to length. I wrote the length of the cables in mm into the connection drawings. I show the two distribution boards separately to make things easier to follow. (There are further steps below on soldering order.) Pick the Connection Drawing that matches the ESP32 Version that you are using. The cable lengths and pinout slightly differs depending on the version.
    - I only got 5 colors of cables
        - red = 3.3V (BME/BH1750)
        - white/grey 5V(LD2410/HC-SR501)
        - black = Ground
        - Green = I2C SCL/UART (If you have more colors you can use different colors for UART and I2C)
        - Blue = I2C SDA/UART (If you have more colors you can use different colors for UART and I2C)
        - Yellow = Motion Out

   #### D1 Mini

    D1 Mini Pinout

   #### ESP32 Large

    Large Pinout

   #### Super Mini

    the Ground of the two distribution boards are connected as the board only has one ground pin
    Super Mini Pinout

1. Make sure to tin the wire ends
1. Solder **one end** of each wire to the **sensors** as described in the Connection Drawings from Step 4

    | Motion Sensor | Presence Sensor | Brightness Sensor | Temperature Sensor |
    | ---- | ---- | ---- | ---- |
    | Motion Sensor | Presence Sensor | Brightness Sensor | Temperature Sensor |

1. Solder the **other end** of the wires to the **distribution proto boards and ESP respectively. Connect wires of the same color together**. If you used a proto board where the lines are already connected via the board you don't need to do any extra step. My proto board has separated solder points so I had to bridge them.

    - The 4x3 pin distribution board is connected to the brightness and temperature sensors.
    - The 2x3 pin distribution board is connected to the motion and presence sensors.

    |4x3|2x3|
    |---|---|
    | 4x3 pin distribution board | 2x3 pin distribution board |

1. **Solder the wires to the ESP pins** as described in the connection drawings above. You need to attach the cables from the back side (because the wifi antenna is on the front and we want that to be facing away from the motion sensor) — attach them as shown in the photos.

    ESP Soldered Wires example

1. Use a **multimeter** to verify that solder joints of different colors do not bridge. Any short can damage components and may cause smoke or even fire.
1. Now it's time to check whether all the soldering has worked out. Flash the software onto the ESP. It can be found in the software section. Verify that all sensors are detected and reporting, then return here to complete assembly.
1. Screw all the sensors in place using M2x3mm screws

    sensors in place

1. Screw the temperature sensor in place. For the BME680 There is already a cone protruding from the wall that holds the sensor in place on the lower screw hole. (1x M2.5x3mm)

    temperature sensors in place

1. Slide the **divider wall** into place. It shields the temperature sensor from ESP board heat. It won’t eliminate the effect entirely, but it’s an improvement.

    Divider Wall

1. Attach the **ball head** to the back of the enclosure.

    Ball Head Back

1. Slide the ESP32 into the rails on the backplate. And attach the USB cable.

    D1 Mini Rails
    Super Mini Rails

1. Slide the distribution boards into the rails on the backplate.

    Distribution Board Rails

1. Close the lid — it **snaps** into place.

    Closed Case

**Congratulations — you’re done!** 🥳🎉

Post a picture and a comment to this model — I’d love to see your results 🤗

### 💾 Software

This project uses [ESPHome](https://esphome.io/) as the underlying software. It’s easy to set up and flash. You need a single YAML file that defines the sensors connected to the device and their properties. I won’t provide general ESPHome flashing instructions — the official documentation is excellent:
Guide: <https://esphome.io/guides/installing_esphome/>

1. Download the source code from [my GitHub](https://github.com/DerGary/all-in-one-sensor-device/archive/refs/heads/main.zip)
1. Extract the zip file
1. Navigate to the V2 Folder
1. There is an esp32.yaml (for the D1 Mini and the ESP32 Large Version) and an esp32supermini.yaml (for the supermini version, with another pinout). Choose the one that matches your ESP version. You can copy the file multiple times and name it differently if you want to create multiple devices.
1. Change the **friendly name, name**, and optionally the **area** to your liking.
1. Also uncomment/comment out the includes for the language package and the sensor that you are using.
1. In **secrets.yaml**, set **wifi-password** and **wifi-ssid** to your Wi-Fi credentials.
1. Set the **esp-password** and **esp-username** to any values you like. If you create multiple devices you should set unique values for each of the device and rename the secrets to reflect that.
1. Set the **esp-api-key** to a value generated via the website: <https://esphome.io/components/api/#configuration-variables> This value is used to add the device to home assistant. If you create multiple devices you should set unique values for each of the device and rename the secrets to reflect that.
1. Run ``esphome run device.yaml`` to flash the device.
1. Test whether all sensors work as expected.
1. Once deployed in its final location, proceed with calibration.

*Note:* if you use a esp32 c6 board, this device can ditch Wifi an instead use OpenThread to join your existing Thread network. Simply uncomment the OpenThread block in esp32supermini.yaml (and remove the wifi block) and ad your openthread-tlv to the secrets. you can find the openthread-tlv in homeassistant under devices -> "thread" integration -> configure -> preferred network -> info (the little i icon). 

### 🎯 Calibration

Calibration is **non-trivial** and may take time and multiple iterations. I mainly use **offset calibration**, which is the easiest approach, though there are more accurate methods also available.

#### BME680

I only calibrated **temperature** and **humidity**. I don’t use air pressure, and air quality is meant to auto-calibrate.

1. Let the device sit in its final location for **5–10 minutes** to saturate with heat from the ESP.
1. Place a **trusted temperature & humidity sensor** nearby.
1. In the **parameters** section of your ESPHome file, set ``bme680_temperature_offset`` to the difference between your device and the trusted sensor. Flash the new values — this also changes humidity readings.
1. Additionally you can calibrate humidity and temperature further using the input components **Temperature Offset** and **Humidity Offset** directly in Home Assistant.

#### BME280

Again, I only calibrated temperature and humidity; I don’t use air pressure.

1. Let the device sit for **5–10 minutes** to heat-soak.
1. Place a trusted sensor nearby.
1. Calibrate humidity and temperature using the input components **Temperature Offset** and **Humidity Offset** directly in Home Assistant.

#### Motion Sensor

The motion sensor has a jumper that defines the mode of the sensor.

- H (Repeat Trigger / Retriggerable mode)
  - As long as motion is detected, the output stays **HIGH**.
Example: If the delay time is set to 10 s and motion is detected again after 5 s, the timer resets and the output remains HIGH continuously until no more motion is detected.
- L (Single Trigger / Non-Retriggerable mode)
  - When motion is detected, the output goes **HIGH** for the set delay time, then returns to LOW — even if motion is still happening during that period. Only after the delay finishes and the sensor is ready again can it trigger once more.

The default seems to be **L**, while I use **H**.

The sensor has **two potentiometers**: one for **trigger time** and one for **sensitivity**. Looking from the back, the **left** is sensitivity and the **right** is time delay (I always mix them up 😅).

1. Set the **time delay** long enough that the presence sensor has already triggered, but short enough to release in a timely manner when a person leaves. This makes automations easier.
1. Set **sensitivity** just high enough to trigger where needed, but as low as possible to reduce false positives.
I set it to about there:

    HC-SR501 Knobs

Presence Sensor:

This sensor is the most challenging to calibrate. The g0-g8 values depict the different distances from the sensor.

1. **Enable Engineering Mode**
1. Ensure **no one is in the room** while calibrating.
1. Let the sensor sit for **10 minutes** while Home Assistant gathers **g0–g8 move/still** energy values.
1. Review the history of each **g0–g8** value in Home Assistant. Find the **highest** value each.
1. Set the **g0–g8 thresholds** to **5–10 % higher** than the highest observed value for this distance.
1. **Disable engineering mode**

### 🚫 Don'ts

1. Don’t mount the device **too high**. Hot air rises and will skew and destabilize temperature readings; it may also affect the motion sensor.
1. Don’t place the device **near a heater** — it reduces temperature accuracy and can trigger the motion sensor.
1. Don’t place it directly in strong airflow (e.g., when airing the room), as the motion sensor detects rapid heat changes.

### 📢 Tips

- You can use the [underware collection](https://makerworld.com/de/models/783010-underware-2-0-infinite-cable-management?from=search#profileId-1504508) to route your cables.
- You can use [**my cable clamps**](https://makerworld.com/de/models/1744421-adhesive-cable-clamp-for-usb-cables-4mm-3mm#profileId-1853998) to route USB cables. They fit the cables linked here, use minimal filament, and can be attached with double-sided tape.
- You can use [my collection of ball head mounts](https://makerworld.com/de/collections/9129741-ball-head-mounts) to mount the device to cabinets, tubes, walls, desks etc.
- It’s preferable to position the device **facing the area where you stay** rather than just facing the door. The motion sensor has a wide field of view and covers most of the room, while the presence sensor works best when pointed directly at the target.
- You can test all sensors with **jumper wires** before committing to soldering.

### ⚠️ Disclaimer

This project is **not easy**: you have to solder a lot, including **very small** pins. You have been warned — but I’d love to see people try it 😊

The finished product is not perfect — that’s why the title is not *“Ultimate Smart Home Sensor Device”* 😅. I plan to release a revised version with other sensors when I have time and when the sensors I want become more accessible. Since I don’t know when that will be, I’m sharing this version for now.

**Things that bug me on the current version:**

1. **(This got a lot better on the V2 version, to a point where its not really an issue anymore, but it might happen and therefore is still listed here)** The motion sensor is very cheap and sometimes triggers when no one is in the room. (This can be minimized by **reducing the ESP’s Wi-Fi signal strength**, as cheap motion sensors are prone to misfire due to Wi-Fi interference.)
1. The motion sensor can trigger when you **air the room**, as it detects heat changes.
1. The presence sensor uses **24 GHz**. While it can detect mostly stationary humans, it cannot detect **very small movements** or someone under a blanket. (This mostly applies to my girlfriend — somehow I am tracked a bit better 😅).
1. The presence sensor is **extremely hard to solder**. I actually broke a sensor by accidentally desoldering the resistor right next to the pins. I now solder the wires directly to the pins which is janky but it works and is a lot easier.

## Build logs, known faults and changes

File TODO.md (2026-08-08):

# TODO

## Calibration

- Add gain (multiplier) number entities for temperature and humidity alongside the existing offset entities, enabling proper linear calibration (`raw × gain + offset`). A pure offset assumes a constant error across the full range; gain+offset handles sensors whose error scales with the measured value. Both entities would be runtime-configurable from HA (default gain: 1.0, no reflashing needed). Requires two reference measurements at different values to derive both parameters.

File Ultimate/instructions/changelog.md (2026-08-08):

## 🆕 Changelog

### v1.0.2

1. Add a Firmware version diagnostic sensor, showing the flashed release version in Home Assistant
1. Add OpenThread as a connectivity alternative to WiFi (esp32c6 variant, requires a local build with your own OTBR TLV)
1. Update ESPHome to 2026.7

### v1.0.1

1. Occupancy LED color adjusted to a lighter, more neutral warm white
1. The Occupied sensor now turns back on if presence is detected within 10 seconds of it turning off
1. Update ESPHome to 2026.6

### What it does better than the All-In-One Smart Home Sensor Case V2

1. Multi-person, zone-based presence tracking: The LD2450 allows tracking multiple people simultaneously and triggering automations based on their position within defined room zones.
1. Improved still-presence detection: The C4001 sensor provides significantly more reliable detection of stationary occupants, even at greater distances.
1. Reduced false positives: The Panasonic PIR sensor is substantially less prone to false triggers compared to the PIR used in the previous version.
1. True CO₂ measurements: The SCD40 measures actual CO₂ concentration. In contrast, the BME680 used previously only estimated CO₂ based on VOC readings and responded more slowly to changes.
1. More capable MCU: The ESP32-C6 adds Wi‑Fi 6 support and integrated Zigbee hardware (Zigbee is not yet enabled in software).
1. Status LED integration: A built-in status LED can be used, for example, to provide immediate visual feedback when indoor air quality degrades.
1. Higher accuracy and stability for environmental sensing: The SHT41 (temperature & humidity) and SGP30 (VOC) replace the BME680 to achieve faster response times, better long-term stability, and more reliable measurements.

### What it does worse than the All-In-One Smart Home Sensor Case V2

1. Slightly larger physical footprint.
1. Higher overall cost (approximately €60-70 for the sensors excluding shipping).
1. Increased power consumption.
1. Greater assembly complexity due to a higher number of sensors and solder joints.
1. Limited board compatibility: only ESP32 Super Mini and DFRobot Beetle are supported (no D1 Mini or ESP32 Large variants).

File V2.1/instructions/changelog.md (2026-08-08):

## 🆕 Changelog

### V2.1.4

1. Add a Firmware version diagnostic sensor, showing the flashed release version in Home Assistant
1. Add OpenThread as a connectivity alternative to WiFi (esp32c6 variant, requires a local build with your own OTBR TLV)
1. Update ESPHome to 2026.7

### V2.1.3

1. Occupancy LED color adjusted to a lighter, more neutral warm white
1. The Occupied sensor now turns back on if presence is detected within 10 seconds of it turning off
1. Update ESPHome to 2026.6
1. BME680 air quality status now uses translated labels ("Good", "Warning", "Critical") instead of hardcoded English strings

### V2.1.2

1. Air quality state is now always visible in Home Assistant (no longer hidden by default)
1. Air quality state now shows translated values ("Good", "Warning", "Critical") instead of internal strings
1. Air quality state and occupancy no longer show "unknown" after the device boots — they start at "Good" and "not occupied" immediately
1. Humidity is now clamped to 0–100% so offset calibration can never push the value out of range
1. All Home Assistant entities now have icons

### V2.1.1

1. Changed LD2410B seat to reduce reflections.
    - If you had any problems with the ld2410b detecting very high values while no one is in the room, this will fix it.
    - I now got idle values of 3-5%.
    - It makes such a huge difference, that I even upgraded all fronts of my sensors to this new version
2. Changed LED automation colors slightly
    - Color for occupancy is now warm white
    - effect of occupancy is now explicitly "none"
3. Updated Instructions accordingly

### V2.1.0

1. Add an LED to show status for e.g. Improv BLE
1. Smaller Enclosure for the ESP32 Large variant
1. Software changes
    - Precompiled binaries
    - Add Improv BLE instead of captive Portal
    - No need to change any secrets or variables
    - An optional occupancy automation which shows the occupancy status via the status led
    - An optional air quality automation which shows the air quality status via the status led

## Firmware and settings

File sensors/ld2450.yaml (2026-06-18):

# Pinned to a contributor's fork branch instead of the official v1.0.6 release: upstream doesn't
# compile against current ESPHome (removed `sensor::Sensor::unit_of_measurement_`, see
# https://github.com/TillFleisch/ESPHome-HLK-LD2450/issues/41). This fork branch carries the fix
# from the still-open https://github.com/TillFleisch/ESPHome-HLK-LD2450/pull/44. Switch back to
# the official repo once that PR is merged and released.
external_components:
  - source: github://flo-rian/ESPHome-HLK-LD2450@pr/esphome-2026-compat

uart:
  - id: ld2450_uart
    tx_pin: ${tx_pin}
    rx_pin: ${rx_pin}
    baud_rate: 256000
    parity: NONE
    stop_bits: 1

# Each zone's polygon is entered as a single text entity in HA, formatted as "x1,y1;x2,y2;x3,y3;..."
# (meters, at least 3 points). This allows arbitrary polygons - not just a fixed number of corners -
# without needing a number entity per point. The polygon lambda re-parses the text every 30 seconds,
# so editing it in HA reshapes the zone within half a minute. Unparsable or invalid
# (non-convex/duplicate-point/too-short) polygons are ignored by the component and the previous
# valid polygon is kept, so a zone can never end up in a broken state while typing.
LD2450:
  uart_id: ld2450_uart
  name: "LD2450"
  flip_x_axis: false
  fast_off_detection: false
  max_distance_margin: 25cm
  max_detection_distance:
    name: LD2450 ${label_max} ${label_distance}
    initial_value: 6.0m
    step: 0.1m
    restore_value: true
    entity_category: config
    icon: mdi:map-marker-distance
    disabled_by_default: true
    web_server:
      sorting_group_id: ld2450_group
  max_detection_tilt_angle:
    name: LD2450 ${label_max} ${label_angle}
    initial_value: 90°
    step: 1°
    restore_value: true
    entity_category: config
    icon: mdi:angle-acute
    disabled_by_default: true
    web_server:
      sorting_group_id: ld2450_group
  min_detection_tilt_angle:
    name: LD2450 ${label_min} ${label_angle}
    initial_value: -90°
    step: 1°
    restore_value: true
    entity_category: config
    icon: mdi:angle-acute
    disabled_by_default: true
    web_server:
      sorting_group_id: ld2450_group
  occupancy:
    id: ld2450_presence
    name: LD2450 ${label_presence}
    disabled_by_default: true
    icon: mdi:account-eye-outline
    web_server:
      sorting_group_id: ld2450_group
  target_count:
    name: LD2450 ${label_presence_target} ${label_count}
    icon: mdi:counter
    disabled_by_default: true
    web_server:
      sorting_group_id: ld2450_group
  restart_button:
    name: LD2450 ${label_restart}
    entity_category: diagnostic
    disabled_by_default: true
    icon: mdi:restart-alert
    web_server:
      sorting_group_id: ld2450_group
  factory_reset_button:
    name: LD2450 ${label_factory_defaults}
    icon: mdi:factory
    disabled_by_default: true
    entity_category: diagnostic
    web_server:
      sorting_group_id: ld2450_group
  tracking_mode_switch:
    name: LD2450 ${label_multi_target_tracking}
    icon: mdi:account-multiple
    restore_mode: RESTORE_DEFAULT_ON
    disabled_by_default: true
    web_server:
      sorting_group_id: ld2450_group
  bluetooth_switch:
    name: LD2450 ${label_bluetooth_mode}
    icon: mdi:bluetooth
    restore_mode: RESTORE_DEFAULT_OFF
    disabled_by_default: true
    entity_category: diagnostic
    web_server:
      sorting_group_id: ld2450_group
  targets:
    - target:
        name: "LD2450"
        x_position:
          id: ld2450_target_1_x
          name: "${label_target}-1 X ${label_position}"
          icon: mdi:axis-x-arrow
          disabled_by_default: true
          web_server:
            sorting_group_id: ld2450_group
        y_position:
          id: ld2450_target_1_y
          name: "${label_target}-1 Y ${label_position}"
          icon: mdi:axis-y-arrow
          disabled_by_default: true
          web_server:
            sorting_group_id: ld2450_group
        speed:
          id: ld2450_target_1_speed
          name: "${label_target}-1 ${label_speed}"
          icon: mdi:speedometer
          disabled_by_default: true
          web_server:
            sorting_group_id: ld2450_group
        distance_resolution:
          id: ld2450_target_1_resolution
          name: "${label_target}-1 ${label_distance_resolution}"
          icon: mdi:ruler
          disabled_by_default: true
          web_server:
            sorting_group_id: ld2450_group
        angle:
          id: ld2450_target_1_angle
          name: "${label_target}-1 ${label_angle}"
          icon: mdi:angle-acute
          disabled_by_default: true
          web_server:
            sorting_group_id: ld2450_group
        distance:
          id: ld2450_target_1_distance
          name: "${label_target}-1 ${label_distance}"
          icon: mdi:map-marker-distance
          disabled_by_default: true
          web_server:
            sorting_group_id: ld2450_group
    - target:
        name: "LD2450"
        x_position:
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

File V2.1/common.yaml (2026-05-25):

substitutions:
  friendly_name: All in One Sensor # the friendly name of your device, can be anything.

esphome:
  name: all-in-one-sensor # the name of your device. It should not contain any special characters or whitespaces. the device can be found in the network by this name.
  friendly_name: ${friendly_name}
  name_add_mac_suffix: True
  includes:
    - "<esp_wifi.h>"
  on_boot:
    priority: 200.0
    then:
      - lambda: |-
          float val = id(wifi_tx_power_dbm);
          int8_t power_val = (int8_t)(val * 4);

          wifi::global_wifi_component->set_output_power(val);

          esp_err_t err = esp_wifi_set_max_tx_power(power_val);

          if (err == ESP_OK) {
            ESP_LOGI("wifi_control", "Max TX Power changed to %.2f dBm.", val);
          } else {
            ESP_LOGE("wifi_control", "Error changing max tx power: %s", esp_err_to_name(err));
          }

globals:
  - id: wifi_tx_power_dbm
    type: float
    restore_value: True
    initial_value: "8.5"

esp32:
  variant: ${variant}
  framework:
    type: esp-idf

## Remove this if you don't want to track bluetooth device presence.
esp32_ble_tracker:
  scan_parameters:
    active: True # Whether to send scan-request packets to devices to gather more info (like devicename)
    interval: 211ms # suggested 211ms # default 320ms
    window: 30ms # suggested 120ms # default 30ms

## Remove this if you don't need to expand your home assistants bluetooth range
bluetooth_proxy:
  active: true

## Enables logging, eats ram, only enable if necessary.
# logger:
#   level: DEBUG

web_server:
  port: 80
  local: true

## Enables the Home Assistant API
api:
  id: api_id
  encryption: # Uses key set by Home Assistant
  on_client_connected:
    - script.execute: control_leds
  on_client_disconnected:
    - script.execute: control_leds

## Enables to update the firmware over the air
ota:
  - platform: esphome
  - platform: web_server

wifi:
  id: wifi_id
  output_power: "20db"
  on_connect:
    - lambda: id(improv_ble_in_progress) = false;
    - script.execute: control_leds
  on_disconnect:
    - script.execute: control_leds

esp32_improv:
  authorizer: none
  # next_url: https://my.home-assistant.io/redirect/config_flow_start?domain=esphome&ip_address={{ip_address}}
  on_start:
    - lambda: id(improv_ble_in_progress) = true;
    - script.execute: control_leds
  on_provisioned:
    - lambda: id(improv_ble_in_progress) = false;
    - script.execute: control_leds
  on_stop:
    - lambda: id(improv_ble_in_progress) = false;
    - script.execute: control_leds

## adds support to choose your wifi through the esp fallback hotspot
# captive_portal:

sensor:
  ## this will report the uptime of the device. If your device reboots unexpectedly you can see it in this value.
  - platform: uptime
    type: seconds
    name: ${label_uptime}
    update_interval: 60s
    icon: mdi:timer-outline

  ## this will report the free memory. If your device reboots unexpectedly it may be because there is not enough free memory. In my experience there must be at least 40-50kb available at all times for reliable operation.
  - platform: template
    name: ${label_free_mem}
    lambda: return heap_caps_get_free_size(MALLOC_CAP_INTERNAL);
    icon: "mdi:memory"
    entity_category: diagnostic
    state_class: measurement
    unit_of_measurement: "b"
    update_interval: 60s
    disabled_by_default: true

  ## this reports the wifi signal strength of your wifi access point. If you want to reduce or increase your wifi output power of your access point you can use this value for reference. This value does not reflect the output power of the esp device, but the output power of the wifi access point.
  - platform: wifi_signal # Reports the WiFi signal strength/RSSI in dB
    disabled_by_default: true
    name: ${label_wifi_signal}
    id: wifi_signal_db
    update_interval: 1s
    entity_category: "diagnostic"

binary_sensor:
  ## this reports whether the device is online.
  - platform: status
    icon: mdi:chip
    name: "${friendly_name} Status"
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

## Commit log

2025-08-29 removes temperature offset
2025-09-21 removed throttle and moved to esp-idf framework
2025-12-31 adds V2 Sensor Case
2026-01-02 moved sensors to own files
2026-01-03 fix supermini i2c pinout
    [esp32supermini.yaml]
2026-01-27 adds ultimate case
2026-04-20 replaced sgp4x with sgp30
    [device.yaml]
2026-05-20 adds model files, pinout draw.io, fixes image files
    [D1Mini.3mf, D1Mini.stl, Large.3mf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]
2026-05-21 chore: optimizes pipeline release
    [v2-D1Mini.3mf, v2-D1Mini.stl, v2-Large.3mf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]
2026-05-25 adds v2.1 build with variable tx power
2026-05-25 adds model files for v2.1
    [V2.1-D1Mini.3mf, V2.1-D1Mini.stl, V2.1-Large.3mf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]
2026-05-25 moves air quality status led automation to own file
2026-05-25 changes status led colors
2026-05-25 adds status led in documentation
2026-05-25 filters unnecessary script calls to status led
2026-06-03 changed occupancy status led color to warm white
2026-06-03 changed seat of ld2410b to reduce reflections
    [V2.1-D1Mini.3mf, V2.1-D1Mini.stl, V2.1-Large.3mf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]
2026-06-18 add Ultimate sensor release with shared architecture
    - Add Ultimate/device.yaml with ESP32-C6, LD2450 + C4001 dual presence,
    SGP30 + SCD4x air quality, SHT4x/BME280 temperature, BH1750 and EKMC PIR
    - Add GitHub Actions CI/CD for Ultimate (matrix: lang × temp, factory + OTA
    binaries, PDF instructions, GitHub Release on ultimate* tags)
    - Extract shared common.yaml at repo root; V2.1 and Ultimate device files
    now own their substitutions (friendly_name, device_name) and web_server
    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
2026-06-18 fix c4001 UART pins and improve flashing robustness
    - Move C4001 UART to GPIO22/GPIO23 (avoids strapping pin conflicts on ESP32-C6)
    - Add timeout and watchdog feeding to c4001 blocking loops to prevent WDT crashes when sensor is unresponsive
    - Add pin reference table to assembly instructions
    - Add flashing troubleshooting note for factory-fresh devices that bootloop
    - Update connection drawings for new pin assignments
    [c4001.h, device.yaml]
2026-06-18 add connection drawing source and 3D models
    [ultimate.3mf, ultimate.stl]
2026-06-18 add LED blackout step and images to assembly instructions
2026-06-18 add tolerance to sensor covers
    [ultimate.3mf, ultimate.stl]
2026-06-18 add LD2450 polygon zone support with runtime configuration
    Replaces the previous LD2450 config with the TillFleisch/ESPHome-HLK-LD2450
    external component (pinned to a fork branch for ESPHome 2026 compat). Zones are
    now defined as free-form convex polygons entered as text in HA, re-evaluated
    every 30s. Zone margins and detection limits (max distance, tilt angles) are
    configurable at runtime via HA number entities. All target and zone sub-sensor
    names are fully translated for both de/en. Instructions updated with polygon
    format, decimal separator note, and zone state behavior.
    [ld2450.yaml]
2026-06-18 polish entities: icons, boot states, language labels, humidity clamp, instructions table
    - Add icons to all entities missing them (LD2450 per-target sensors, zone
    occupancies/counts, C4001 presence/save button, ws2812, automation switches,
    wifi signal, air quality status)
    - Add mdi:lightbulb-auto to occupancy and air quality LED automation switches
    - Disable zone 2/3 entities, max_detection_distance, and multi-target tracking
    switch by default; set restore_mode for tracking and bluetooth switches
    - Translate air quality state values (Good/Warning/Critical) via lang substitutions
    and publish initial Good state on boot; fix occupied boot state with has_state() guard
    - Add humidity clam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
    [bme680.yaml, common.yaml, ld2450.yaml]
2026-08-07 Open thread support (#6)
    * added optional openThread connection alternative to wifi
    * added openthread support to the v2 instructions
    * remove openthread block from the normal esp32 config
    ---------
2026-08-07 Remove dead wifi_ssid/wifi_password vars from V2 esp32.yaml common include
    These were left over after #6 moved WiFi config into connectivity/wifi.yaml;
    common.yaml no longer reads them.
    Claude-Session: https://claude.ai/code/session_01GBVgN6BqQc8vAP1mh2auSj
    [esp32.yaml]
2026-08-08 Add firmware version text sensor, set from tag in CI
    Adds a Firmware diagnostic text sensor (common.yaml) fed by a new
    top-level `version` substitution, so the flashed build's version is
    visible in Home Assistant without checking the binary filename.
    version defaults to the current release number per device.yaml, for
    local builds. CI now computes it from the git tag (or a dev.<run>
    fallback for PR builds) in a dedicated step and passes it via
    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
2026-08-08 Bump version and add changelog entries for firmware version sensor
    Ultimate v1.0.1 -> v1.0.2, V2.1.3 -> V2.1.4.
2026-08-08 Add OpenThread as a connectivity alternative for V2.1 and Ultimate (#12)
    * Add OpenThread connectivity option for V2.1 and Ultimate
    Same approach as #6 for V2: extract WiFi-specific config (BLE tracker,
    Bluetooth proxy, esp32_improv, TX-power control, wifi_signal sensor) out
    of the shared common.yaml into a new connectivity/wifi_improv.yaml
    package, so both V2.1 and Ultimate can instead select the existing
    connectivity/thread.yaml (esp32c6 variant only) for OpenThread/Matter.
    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
2026-08-08 Make CI status checks required-check-safe (#14)
    * Make CI workflows always post a status check for required-checks support
    Drop the trigger-level `paths:` filter on pull_request (which meant a PR
    outside those paths never got a check run posted, permanently blocking
    merge once the check is required). Path relevance is now computed in a
    `changes` job via dorny/paths-filter and used to skip build-pdf/build-bin
    instead - a skipped job still reports a check. Each workflow gets an
    always-run `*-ci-gate` job as the single required status check.
    * Bump dorny/paths-filter to v4 (latest)
    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
2026-08-08 Update ESPHome to 2026.7 (#15)
    * Update ESPHome CI build image to 2026.7 (latest stable)
    Float the minor-version tag (2026.7) instead of pinning an exact
    patch, so CI picks up patch fixes automatically.
    * Fix V2 changelog heading: V2.0.3 (V2.0.2 already used)
    * Squash unreleased changelog entries into single next version
    V2.1.4/1.0.2 through the ESPHome bump were never released (last
    tags: v2.1.3 / ultimate-v1.0.1) - fold into one V2.1.4 / v1.0.2
    heading instead of releasing three versions in a row.
    * Move V2 changelog to own file, reference it from V2.1 changelog
    Extract V2's inline README changelog into V2/CHANGELOG.md and link
    to it from V2.1's changelog instead of duplicating the f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
    [device.yaml]
2026-11-12 Add high humidity LED alarm and CO2/VOC selection for air quality
    - Ultimate: two config switches (default on) to choose whether CO2 and/or
    TVOC are evaluated for the air quality state and LED.
    - Ultimate + V2.1: high humidity alarm. New "High Humidity" binary sensor
    with a configurable threshold (default 65 %, 2 % hysteresis), and a
    switch (default off) that makes the LED pulse turquoise. Air quality
    alarms take priority over humidity, humidity over occupancy.
    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
